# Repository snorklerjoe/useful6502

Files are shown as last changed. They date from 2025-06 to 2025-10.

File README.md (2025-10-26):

# Useful 6502 Machine

The goal of this project is to build a 6502-based portable machine,
running my own operating system.

## Current Status

*See the complete implementation plan and progress here: [Implemementation Plan](./IMPLEMENTATION_PLAN.md)*

PCB assembled, PIC is able to load code for the 6502 to execute, the 6502 can read/write to the 2-port SRAM.

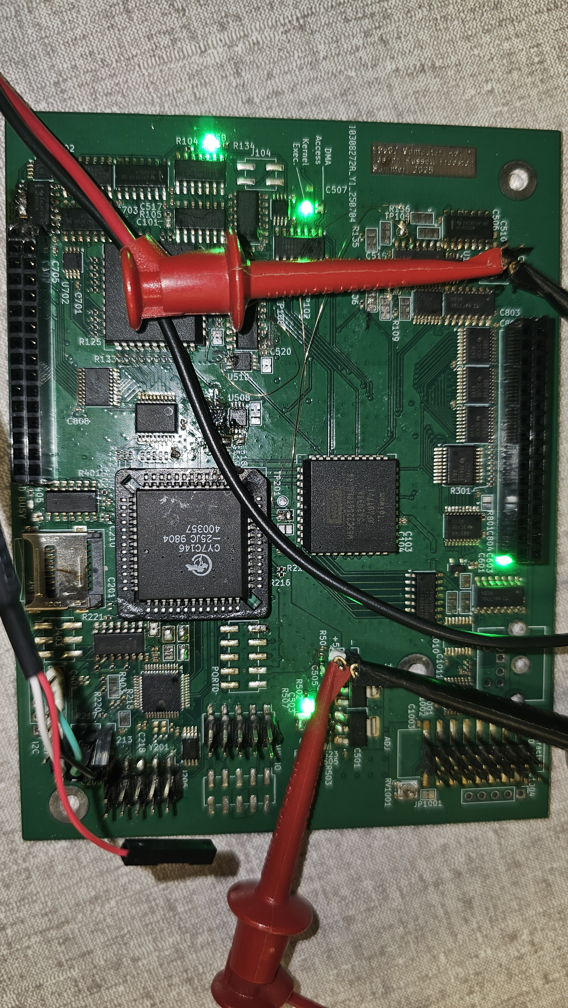
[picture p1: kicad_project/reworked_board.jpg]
Photo of the current (ish) assembled PCB


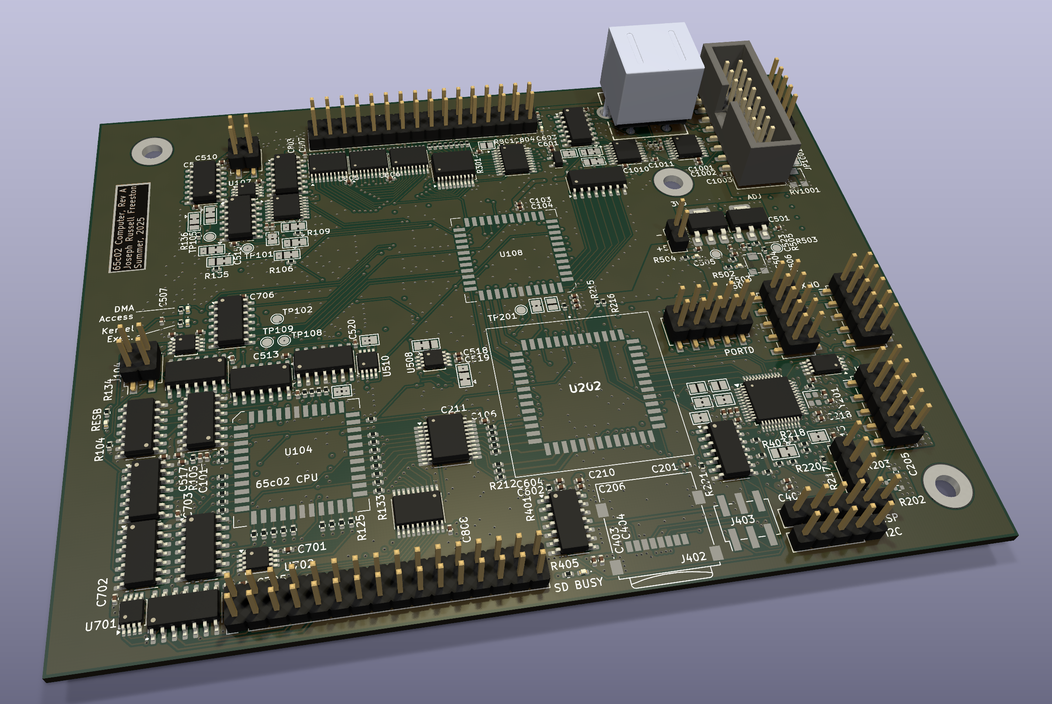
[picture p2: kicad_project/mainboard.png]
Main PCB rendering

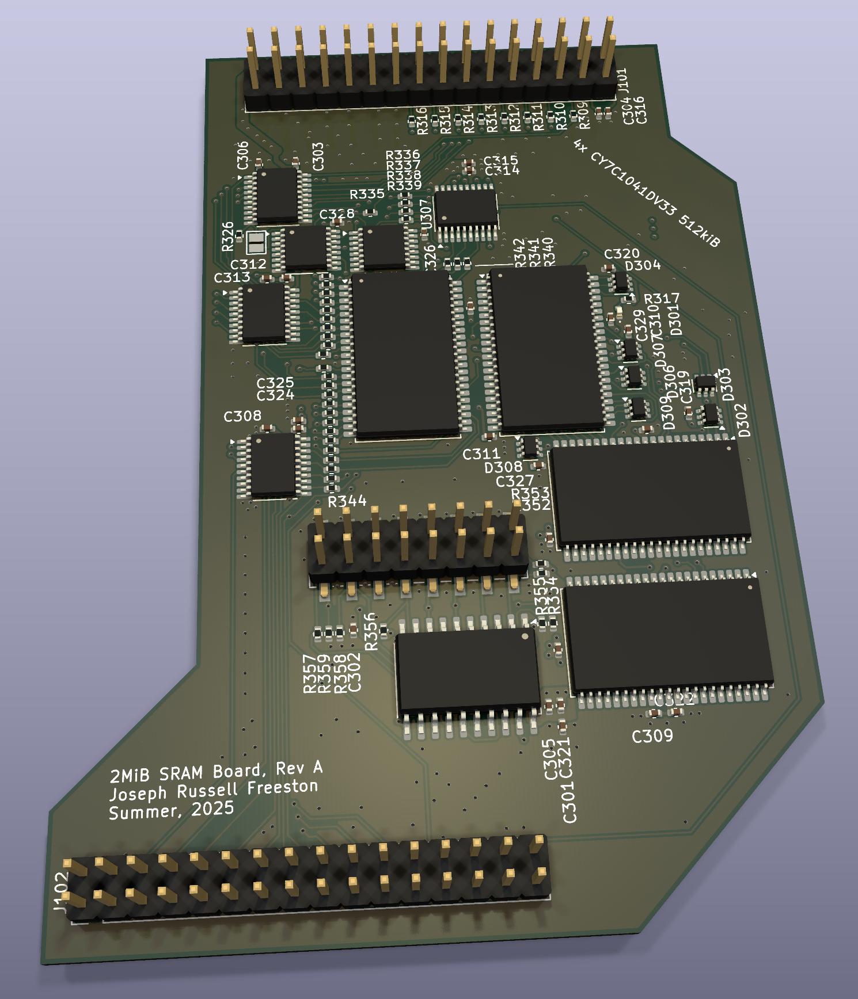
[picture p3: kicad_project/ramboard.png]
RAM Daughterboard rendering


## Hardware Goals

*These are some general points; for the full hardware specification, see here: [Hardware Specification](./HARDWARE.md)*

I want the following end goals to categorize the machine as "useful":

- At least 2 Megabytes of program memory and 2 Megabytes of data memory, of which at least 16k of memory can be used by a single process.
- Protected memory (kernel and user run modes defined by hardware checking if kernel or user code is being executed)
- PIC16 as peripheral coprocessor for fast i/o

## Software Goals

- Traps via "BRK" instruction for sys calls
- Full preemptive multitasking with up to 255 processes, round robin scheduler (maybe mlfq eventually)
- Filesystem: Tree, leaf nodes are devices or drivers.
- Driver for FAT32-formatted SD cards for easy file storage & transfer
- Standard library compatible with cc65 for creating high-level programs
- Basic UNIX-like shell utilities
- Simple web browser?
- SSH client based on DropBear?

## Faults

Faults will be detected by hardware and trigger a RESET, and the kernel will terminate the process.

## Hardware Timers

A hardware timer using the 65c22 will be used to interrupt processes with an NMI.
The kernel will maintain a global clock for user timing needs.

The PIC peripheral coprocessor may, perhaps, feature a watchdog timer to restart the kernel in the event of a crash.

## Particularly Helpful References

There are many resources that have proven themselves indispensible to the progress of his project.  
Here is a *small subset* of such resources:

- <https://www.pagetable.com/c64ref/6502/#>
- <http://www.6502.org/users/andre/index.html>
- <https://wilsonminesco.com/>
- <https://www.burtonsys.com/ps2_chapweske.htm>
- <https://www.pagetable.com/?p=1416>
- <https://github.com/commanderx16/x16-rom/>

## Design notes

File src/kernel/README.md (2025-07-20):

# Kernel Software Secification

This document will define the workings of the kernel I plan to implement for this machine.

Note that present tense will be used in this document irrespective of the implementation status.

## User / Supervisor Modes

The kernel implements user / supervisor modes with a simple mechanism:

- Any interrupt, software (`BRK`) or hardware (`RESB`, `IRQ`, or `NMI`), will force the system into kernel (supervisor) mode.
- As soon as an interrupt occurs, the kernel must quickly force a user-mode inhibit flag
- To exit, the 

## Memory Layout

## Interrupts

### Types & Hardware

### Interrupt Service Routines

## System Tree

### File Paths

## Processes

### Proc Struct
****

### Context Switch

### Scheduling

## System Calls

### Trap Machanism

### List of Calls

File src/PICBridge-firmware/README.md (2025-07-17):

# Build Options

## Setup

I have a modified version of pk2cmd installed on my machine, and the makefile has been given the location of `xc_cc` on my machine.  
If I still have `sudo` in my `Makefile`, it means I have still been too lazy to get the udev rules to work correctly without it.

## Commands

Run `make cycle` to clean, compile, flash, verify, and release the reset pin.

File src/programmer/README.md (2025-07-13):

#  Useful6502 Programmer

This will be python code to use a USB-to-TTL serial device to program kernel
images, load debug binaries, etc. to the 6502 via the PIC interface.

Here is how this will work:

- This script will load a 512-Byte chunk of code via uart to the PIC, along with an address for where it goes
- The PIC will load a 32-Byte copying boot routine to move these code bytes to wherever they need to go  
    This routine will reside in the top 32 bytes of memory addressed by the 6502, and will need to include all of the system vectors.
- The PIC will start the 6502 by bringing RESB high
- The PIC will halt until it gets interrupted by the 6502, indicating that it is done copying.
- At this point, the PIC will hold the 6502 back in a reset state.
  This process will continue until all data has been loaded.
- Finally, the values of the vectors (which reside in SRAM anyway) will be transmitted over uart
- The PIC will load these values in, start the 6502, and wait for an interrupt.

Thus, this programming script needs to do the following:

- Break a 64kiB binary image into 512-Byte chunks
- Figure out the 32-Byte bootloader code for each chunk
- Communicate with the PIC to load it all over and show progress in the terminal

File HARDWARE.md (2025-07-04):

# Hardware Overview

This document provides an overview and detailed description of the hardware for this Useful 6502 Machine project.

*View the full electrical schematic here: [Schematic](./kicad_project/Homebrew6502Project/Homebrew6502Project.pdf)*

## System Overview

The Useful 6502 Machine is a portable computer based on the WDC 65c02 CPU, featuring protected memory, a PIC16 peripheral coprocessor, dual-port SRAM, and support for external storage via SPI EEPROM and SD card. The system is designed for robust multitasking and expandability.

## Major Components

### 65c02 support logic

#### Clock and bus arbitration

The system clock is initially provided by an external function generator, allowing flexible frequency selection for bring-up and testing. The design includes provisions for a future custom clock board, perhaps with a clock divider to select multiple speeds.  
A hardware-test benchmark program will be used to determine maximum reliable clock speeds, which may be operation-dependent. However, the goal of this design is to clock the CPU at a frequency of at least 10MHz.

To meet the timing requirements of the 65c02 and its peripherals, the design generates several delayed and phase-shifted clock signals. Solder jumpers on the board allow for different devices to receieve clock signals with different delays imparted by slower 74xx logic series to ensure that setup and hold times can be met.  
The delayed clocks can also be used to operate bus switches as a measure against bus contention.

It is worth noting that the system clock as described here is separate from the PIC peripheral coprocessor (explained below), which will use an internal PLL or an external crystal. Rather, the system clock applies for the 65c02 CPU and any relevant synchronous devices thereattached.

#### User / Kernel mode logic

The design implements hardware-enforced user and kernel modes to provide memory protection and process isolation. This is achieved using glue logic that monitors the CPU's address and control lines.

When the CPU accesses an interrupt vector, the logic asserts a "kernel mode" signal. Access to kernel memory (the top 16k), as well as privileged instructions is gated by this signal. If user-mode code attempts to access protected resources, the hardware can trigger a fault. All faults are soft resets, which will not affect the information stored in memory but will lose information in the CPU registers. This is not an issue, as a process that generates a fault will be terminated by the kernel immediately and its memory freed.

#### Interrupts

Non-maskable interrupts will solely be generated by an externally-mapped timer in the 65c22 Versatle Interface Adapter (VIA) chip. This will be used to initiate forced context switching, interrupting whatever process is running regardless of the interrupt flag.
Normal (IRQ) interrupts will be used for i/o purposes, which can be disabled during timing-sensitive operations even while in userspace.

#### Direct character i/o

The primary user interface for this machine will be through a PS/2 keyboard input and a set of character LCD displays.

The PS/2 keyboard interface has a single byte buffer. Whenever a byte is received from the keyboard and the buffer is filled, the interface will signal to the keyboard that it cannot accept another byte by pulling the clock line low until the byte is read. The byte can be read by reading `PORTA` of the 65c22 VIA chip. The data ready / data taken handshake bits of the VIA are used by the PS/2 keyboard interface.

To output information to the character LCD interface, two bits of `PORTB` are used, via an active-low decoder, to select which LCD chip select line (of four) will be driven low. Two addional bits are used for the overall LCD enable, and the LCD register select.  
Writing to the data pins is functionally identical to writing to a memory banking regster (see below), with both least-significant address bits set. The LCD interface can only be written to, and so a character buffer will need to exist in memory.

### Memory

All volatile memory will be mapped into a bank-switched 65c02 address space. The mechanisms and specifics thereof are discussed below:

#### Memory map & address decode

Address decode is almost entirely performed by discrete 74xx logic gates. Devices are chosen carefully to consider propagation delays to attempt the maximum possible speed.

The overall virtual (or as far as the 65c02's address space is aware) memory map is as follows:

Addr Range  |   Label   |   Usage   |   Switched    |   User Privs
------------|-----------|-----------|---------------|----------------
FFFF<br>..<br>F810 | DMA  | Mapping of a dual-port SRAM shared with the PIC16 peripheral coprocessor | NEVER | None
F80F<br>..<br>F800 | VIA | Mapping of VIA hardware registers | NEVER | None
F7FF<br>..<br>C000 | KMEM | General-purpose resident kernel memory. Use for top-level trap routines, ISRs, context switching routines, and whatever else will fit. | NEVER | None
BFFF<br>..<br>8000 | BP2 | Third banked page. Available to user processes upon request. Mapped over the same physical memory as BP1 if not in use. | YES | RWX
7FFF<br>..<br>4000  | BP1 | Second banked page. Available to user processes upon request. Mapped over the same physical memory as BP1 if not in use. | YES | RWX
3FFF<br>..<br>0000 | BP0 | First banked page. Not to be confused with "Zero page", which is a portion of this region. Bank 0 belongs to kernel; everything else here is for userspace. | YES | RWX

All banked memory is physically stored on a daughterboard, for ease of experimentation and expandability.

As far as address decode is concerned, one subsection of the implementation determines a `HIMEM` condition based on the top two bits of the "virtual" address. Anything within "High-Memory" (the top 16kiB) belongs exclusively to the kernel. Obviously, the `VIA` and the `DMA` segments are not bank switched and exist physically within the corresponding devices. The `KMEM` segment is also a resident segment and is hardwired to be stored in bank zero.

#### Bank switching

There are a total of four banking registers in use, which technically enable up to 1 GiB of physical memory to be addressed. Because the memory needs to operate asynchronously and as a result of the cost of SRAM, it is unlikely this limit will ever be reached.
That being said, a PSRAM interface may be an option down the line, particularly as the CPU's bus synchronization controls are made available in the RAM daughterboard headers.

The banking registers are configured as follows:

The "Root bank" register (8-bits) is intended to select which RAM card is being addressed, and represents the 8 most-significant bits of the physical address.

The Bank [A, B, and C] registers store the next 8 most-significant bits. Which register is used for these bits is determined by the two most-significant bits of the virtual address, as defined in the memory map above.

Writing to these registers requires a few steps. Before writing to any of the bank registers, the `/WRITBANKEN` flag in `PORTB` of the 65c22 VIA must be driven low. At that point, the write may be performed (only by code executing in `HIMEM`) by any non-`HIMEM` write, partiularly a zero-page write. It is worth noting that the hardware stack will not function until the `/WRITBANKEN` flag is set back to a `1`. During the write, the "Root Bank" register is written if the third bit (bit 2) of the address is set. Otherwise, the A, B, or C register will be written according to the value of the two least-significant bits of the address. Thus, any bank switch may be performed with three 65c02 instructions: a PORTB clear-bit instruction, a zero-page write, and a set-bit instruction to reset `/WRITBANKEN`.

**Bank Register Map:**

Register      | Address/Selection Bits | Function
--------------|-----------------------|-----------
Root Bank    | Addr bit 2 = 1        | Selects RAM card (8 MSbs of physical addr)
Bank A       | Addr bits [1:0] = 00  | second 8 MSbs for BP0 region
Bank B       | Addr bits [1:0] = 01  | second 8 MSbs for BP1 region
Bank C       | Addr bits [1:0] = 10  | second 8 MSbs for BP2 region

Writes are enabled by clearing `/WRITBANKEN` (VIA PORTB), then writing to the appropriate address. The hardware stack is disabled during this operation and re-enabled by setting `/WRITBANKEN`.

**Note:** Registers are write-only; software should maintain shadow copies for context switching and debugging.

#### Memory protection

User memory will all be bank switched. Any process may be given 16, 32, or 48 kiB of memory in 1-3 banks, respectively. All bank registers will be context-switched, so that no process may access any memory outside of the banks assigned to it. If banks of virtual memory are unused by a process, they will be set to the same bank as `BP0`, so that the address space will wrap around.

While in user-mode, if the address becomes set to any location in `HIMEM` without first involving an interrupt vector-pull, a fault will occur and the process will be terminated as described above.

#### CY7C1041DV33 SRAM interface

The initial solution for volatile memory uses 4x CY7C1041DV33 (512kiB SRAM) to provide 2 MiB of RAM. The CY7C1041DV33 was chosen based on availability and price, despite it being arranged in 16-bit words and using 3.3V logic (requiring level conversion). Glue logic, buffers, and line drivers are thus used to interface to the RAM; see the schematic for more details.

#### Dual-port SRAM

The resident `DMA` segment of the address space is mapped to a CY7C146-25JC 2kiB dual-port SRAM, also chosen by availability and price.

This is accessed by both the 65c02 and the PIC peripheral coprocessor, described below. Mutual exclusion synchronization must be implemented in software to ensure that both processors do not attempt to access the same memory location, although there are hardware provisions for utilizing the CY7C146-25JC's built-in mutual-exclusion hardware to pause the 65c02 CPU in the event of an issue, though preferably the PIC will cooperatively yield.

### Peripheral Interfaces and I/O

#### PIC16 peripheral coprocessor

The PIC16 peripheral coprocessor is responsible for handling fast i/o, offloading time-sensitive and busywork-like i/o tasks from the 65c02. It communicates with the 65c02 primarily through the dual-port SRAM, allowing for efficient data exchange and command passing.

The PIC16 manages a few otherwse-tedious interfaces:

- **SD card interface** (via level-shifted open-collector SPI)  
    This will operate merely as a single-sector buffer and SPI interface. The actual FAT32 implementation will run on the 65c02. When it desires a sector be read, this can be signalled to the peripheral coprocessor via an interrupt, and the 65c02 can be interrupted later, once the entire sector is read into the `DMA` memory and ready for the FAT32 interface to access.
- **SPI EEPROM** (for bootloading and storage of the current kernel image)  
    The intention is that this can be written solely through the PIC over UART to flash a new kernel image and bootloader. The self-installing bootloader and boot-time interrupt vectors will be placed in DMA memory, and the 65c02 will be reset by the PIC. The two processors will then cooperate to move the kernel image from the EEPROM into memory in pieces that fit in the `DMA` memory. Once the image is loaded, a handshake will occur to ensure both processors are in a fully-initialized state before the 65c02 initializes drivers and starts up a shell.
- **General serial peripheral busses**, such as UART and I2C can be used to interface with other devices.  
    This may eventually include an ESP-01 based WiFi interface for network access, and will certainly enable the use of RS-232 peripherals down the line with an external MAX-232 based interface.

An ICSP header is included on the board to enable in-circuit programming and debugging of the PIC coprocessor.

Synchronization between the PIC16 and 65c02 is achieved through software protocols, with the option to use the dual-port SRAM's hardware mutual-exclusion features for critical sections as described previously, but the PIC16 is generally expected to yield access to shared resources as needed to avoid contention.

### Boot Process Summary

The boot process for this machine is as follows:

1. **Power-On:**
   - The PIC16 coprocessor initializes using its internal PLL or external crystal.
   - The 65c02 and peripherals are held in reset while the PIC performs initial checks.

2. **Firmware/Kernel Loading:**
   - The PIC16 bootloader communicates with a host PC (via UART) to receive a new kernel image if needed, programming it into the SPI EEPROM.
   - On normal boot, the PIC16 reads the kernel image from the SPI EEPROM and transfers it in chunks to the dual-port SRAM (DMA region) or main RAM.

3. **System Initialization:**
   - Once the kernel image is loaded, the PIC16 signals the 65c02 to release reset.
   - The 65c02 begins execution from the loaded kernel image, initializing memory, bank registers, and device drivers.

4. **Handshake and Ready State:**
   - The PIC16 and 65c02 perform a handshake via the dual-port SRAM to ensure both are ready.
   - The kernel may perform hardware tests or diagnostics before starting user processes.

5. **Normal Operation:**
   - The system enters normal operation, with the kernel on the 65c02 CPU managing multitasking, memory protection, and I/O.

This process ensures reliable startup, easy firmware updates, and robust initialization of all hardware subsystems.

---

*This document will be updated as features evolve.*

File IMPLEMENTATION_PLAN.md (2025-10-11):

# Implementation Plan

This is the implementation plan for my homebrew 65c02 machine, from initial hardware validation to kernel and OS development

## Hardware Debugging & Validation

- [x]  **Rev A design completion**  
  - Goals & constraints identified
  - Initial schematics developed
  - PCB layout
  - PCB, stencil, and component ordering

- [x]  **Main board assembly**  
  - Assembly & reflow

- [x]  **Initial electrical tests**  
  - Test voltage regulators & check for shorts

- [x] **PIC16 bring-up: Hello world**
  - Write and flash a simple test program (UART Hello World) to verify PIC programming and basic operation.

- [x] **PIC to Dual-port SRAM communication**
  - Develop subroutines for accessing and verifying the dual-port SRAM from the PIC

- [ ] **PIC programs 65c02 memory**
  - Use the PIC to write a short program into SRAM.
  - Allow the 65c02 to execute this program, verifying code/data path and bus arbitration.

- [ ] **PIC ↔ SPI EEPROM**
  - Develop routines for the PIC to read/write the SPI EEPROM.
  - Test with known data patterns and verify persistence.

- [ ] **PIC bootloader & host communication**
  - Implement a bootloader on the PIC that communicates with a Python script on the host PC (via UART).
  - Enable easy programming of kernel images into the SPI EEPROM.
  - Validate end-to-end image transfer and storage (using a checksum?).

- [ ] **65c02 boot from SRAM**
  - Use the PIC to load a test/benchmark image into SRAM.
  - Run the image on the 65c02, verifying CPU operation and memory access.

- [ ] **Hardware test & benchmark suite**
  - Develop a comprehensive test image to exercise all hardware features (memory, I/O, timers, etc.).
  - Run tests at various clock frequencies to determine system stability and performance limits.

- [ ] **System clock board**
  - Design and build a dedicated clock board to replace the function generator.
  - Test with the rest of the system

## Kernel Development

This is still vague until the hardware is validated / debugged and low-level firmware matures.

- [ ] **Initial Kernel Bring-Up**
  - Develop a minimal kernel to handle basic process management and hardware abstraction.
  - Test context switching, memory protection, and basic I/O.

- [ ] **Driver Development**
  - Write drivers for SD card (FAT32), serial I/O, and other peripherals.
  - Integrate with kernel and validate functionality.

- [ ] **CC65 Libc**
  - Develop a custom libc that enabls userland applications to be written or ported in C

- [ ] **Userland & Shell**
  - Develop a simple shell and basic utilities.

---

*Update this plan as milestones are reached and new challenges arise.*

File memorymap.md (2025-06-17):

# Memory Map

Addr Range  |   Label   |   Usage   |   Switched    |   User Privs
------------|-----------|-----------|---------------|----------------
F810 - FFFF | DMA  | Mapping of a dual-port SRAM shared with the PIC16 peripheral coprocessor | NEVER | None
F800 - F80F | VIA | Mapping of VIA hardware registers | NEVER | None
C000 - F7FF | KMEM | General-purpose resident kernel memory. Use for top-level trap routines, ISRs, context switching routines, and whatever else will fit. | NEVER | None
8000 - BFFF | BP2 | Second banked page. Available to user processes upon request. Mapped over the same physical memory as BP1 if not in use. | YES | RWX
4000 - 7FFF | BP2 | Second banked page. Available to user processes upon request. Mapped over the same physical memory as BP1 if not in use. | YES | RWX
0000 - 3FFF | BP1 | First banked page. Not to be confused with "Zero page", which is a portion of this region. Bank 0 belongs to kernel; everything else here is for userspace. | YES | RWX

## Special Addresses

Addr | Label    | Usage
-----|----------|------

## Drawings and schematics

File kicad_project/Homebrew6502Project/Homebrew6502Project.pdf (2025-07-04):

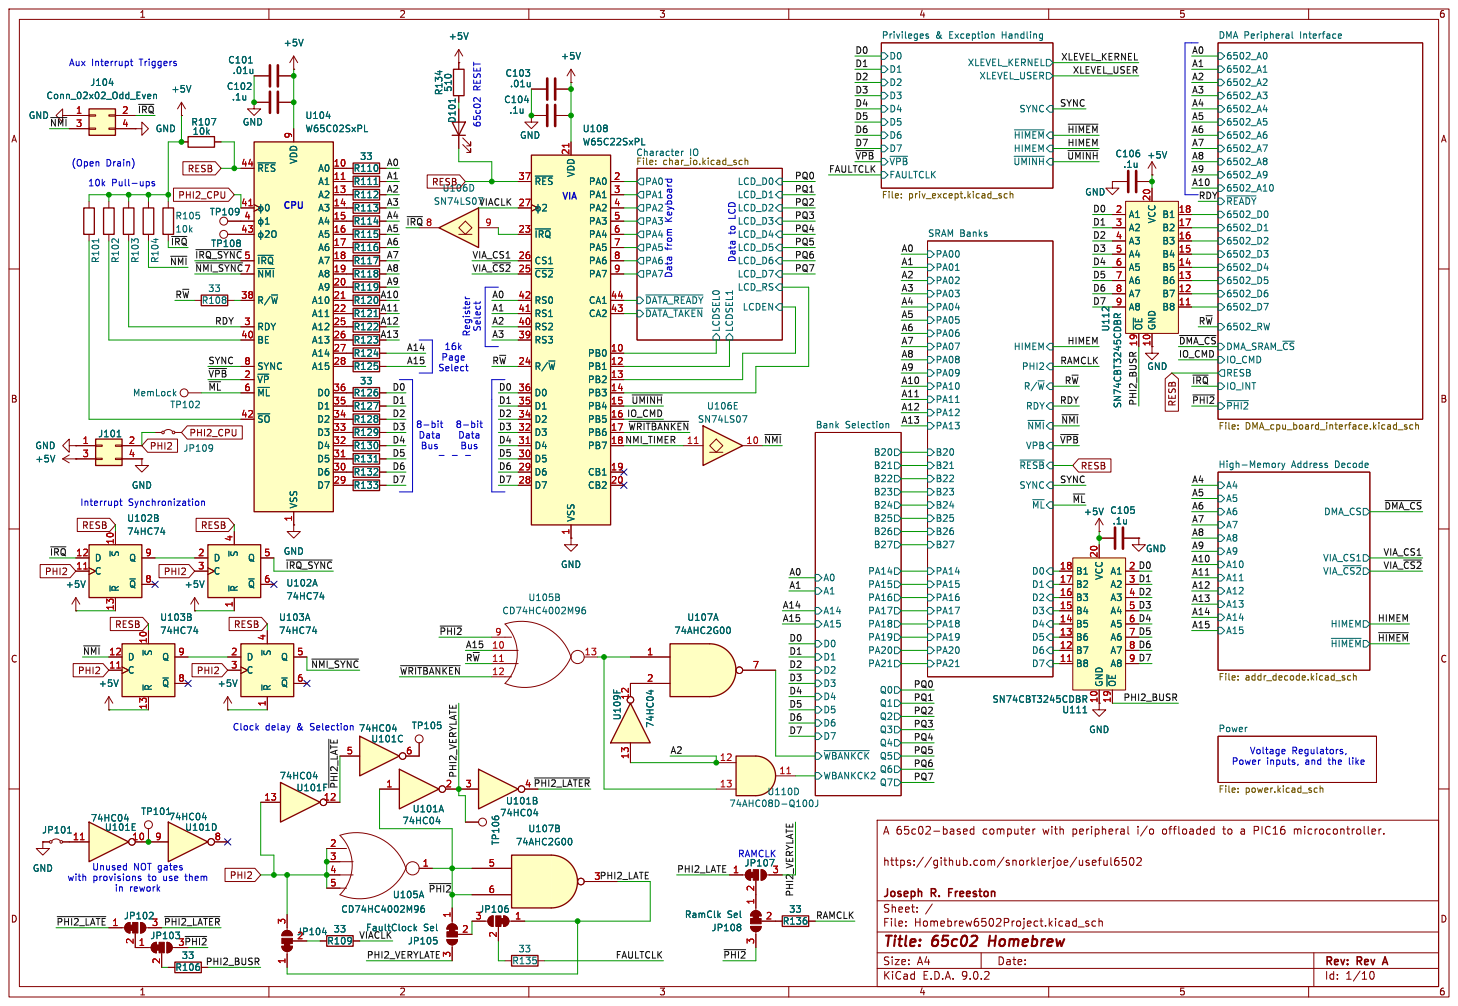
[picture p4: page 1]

8-bit Data Bus

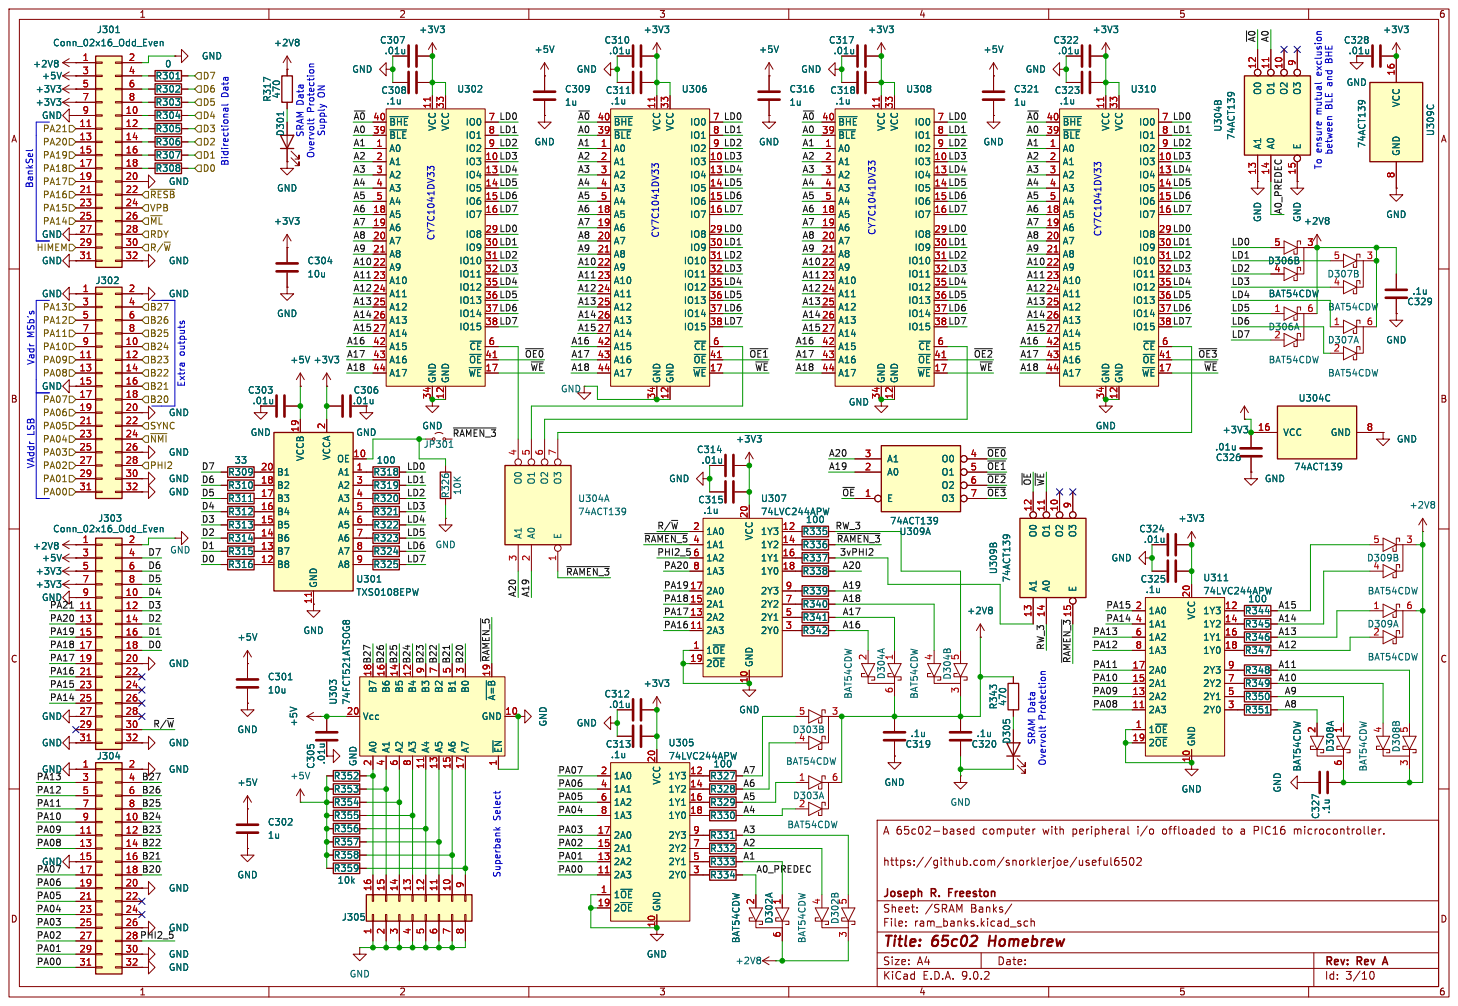
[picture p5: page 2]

IO15 38 ~{CE}6 ~{OE} 41 ~{WE} 17 A0 1 A1 2 A2 3 A3 4 A4 5 A5 18 A6 19 A7 20 A8 21 A9 22 A10 23 A11 24 A12 25 A13 26 A14 27 A15 42 A16 43 A17 44 GND

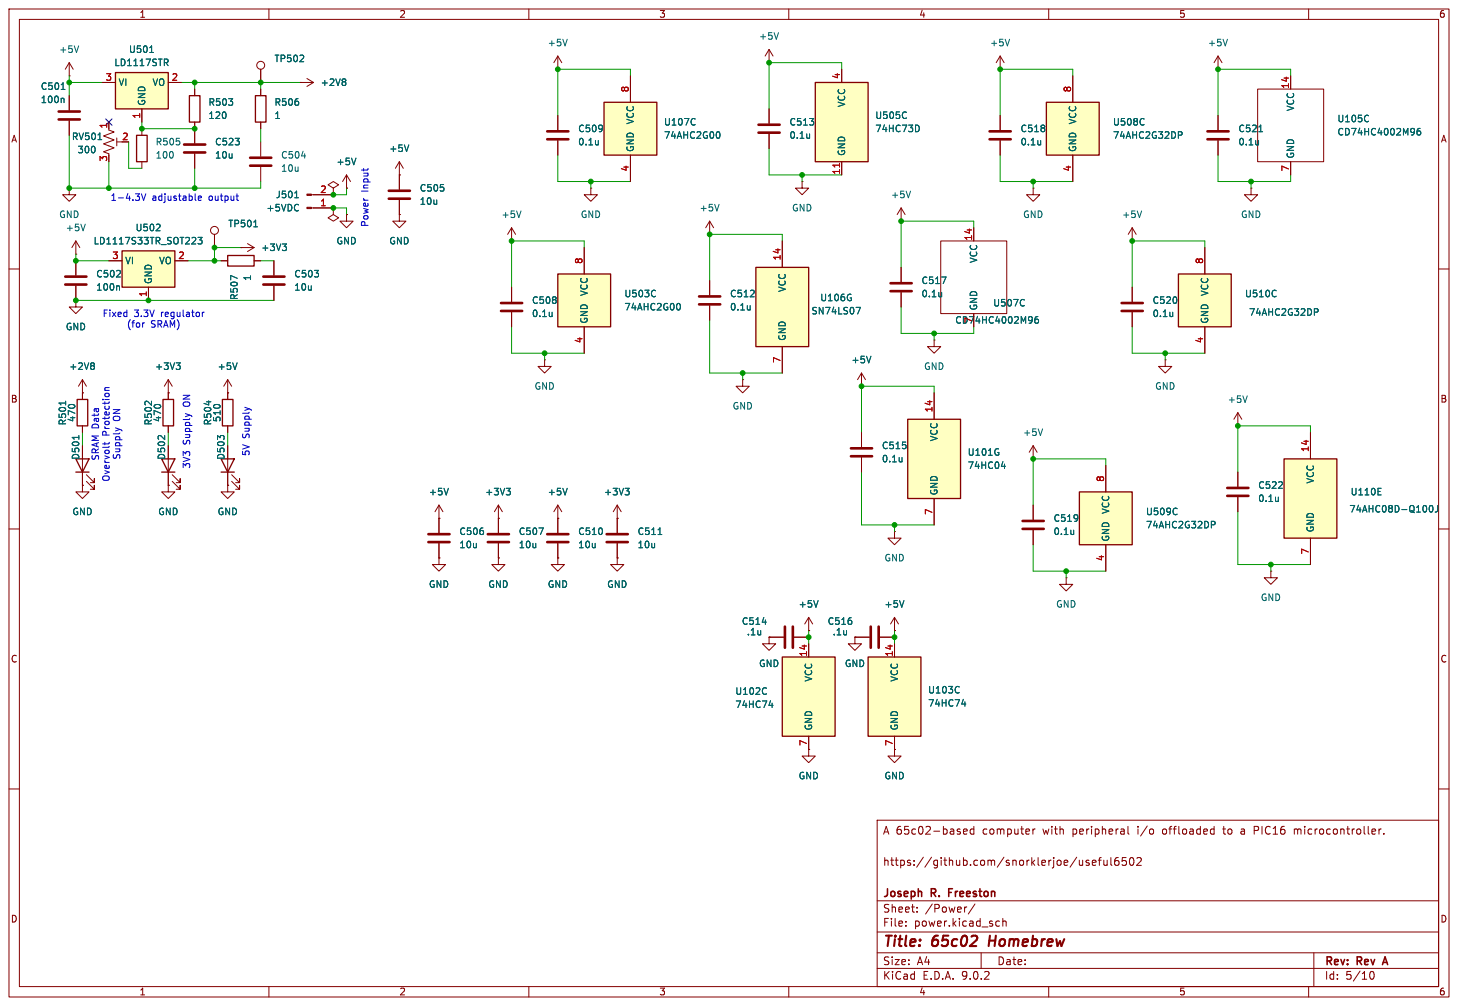
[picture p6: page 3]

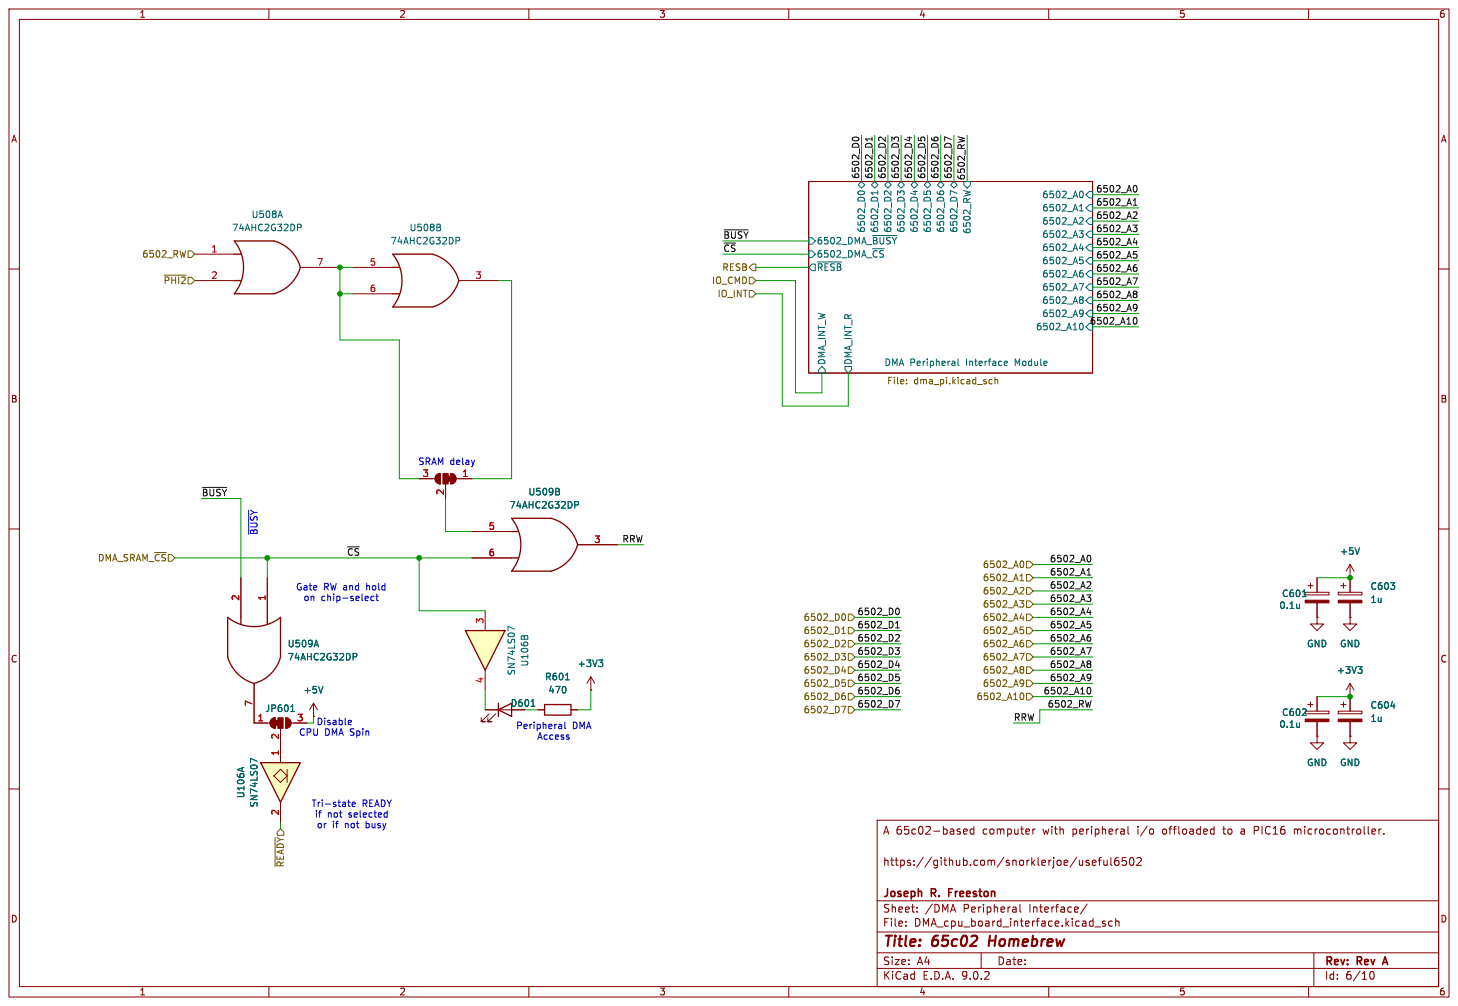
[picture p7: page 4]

or if not busy Gate RW and hold
on chip-select +5V U509A

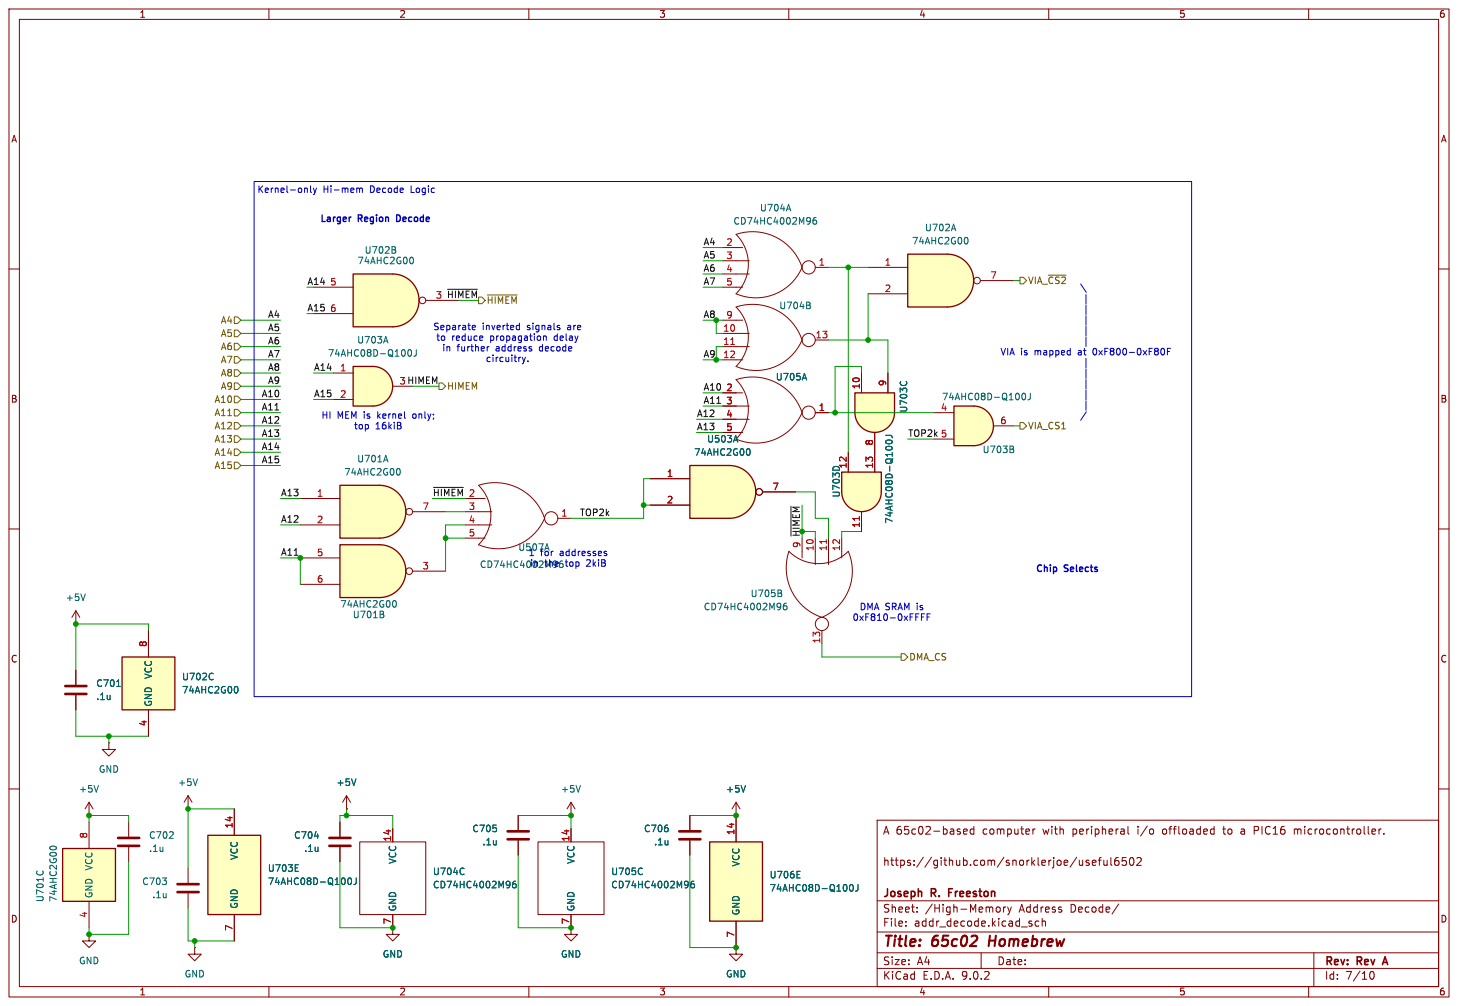
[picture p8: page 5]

Separate inverted signals are

VIA is mapped at 0xF800-0xF80F

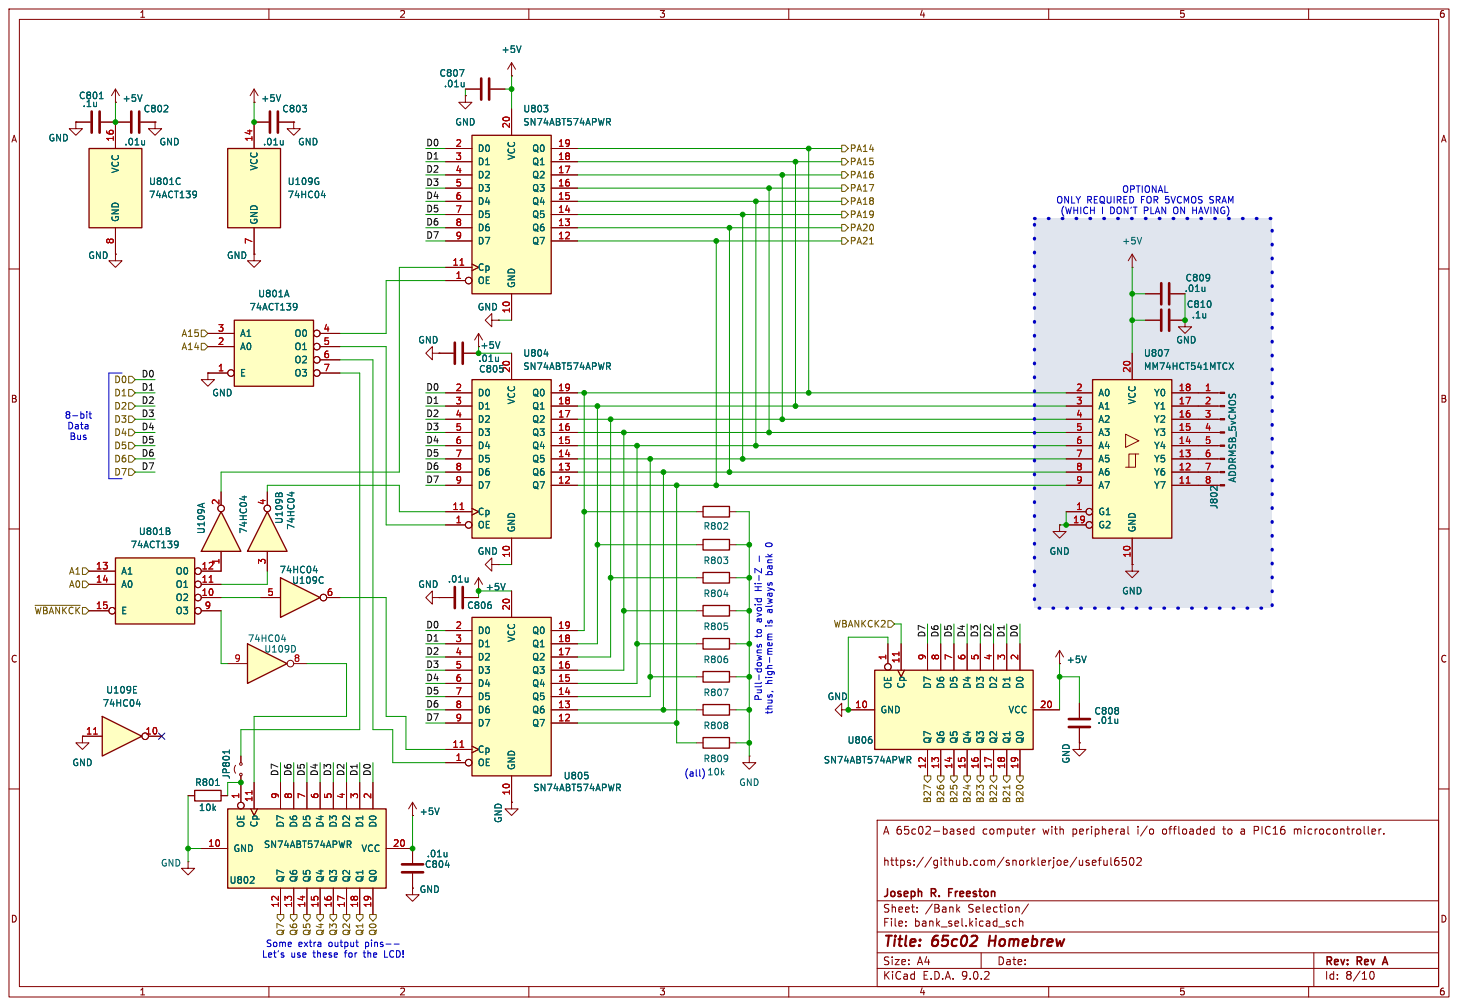
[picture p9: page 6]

(WHICH I DON'T PLAN ON HAVING)
.01u +5V GND
.01u GND

1 VCC 20 GND 10 Q0 19 Q1 18 Q2 17 Q3 16 Q4 15 Q5 14 Q6 13 Q7 12 U802 SN74ABT574APWR GND GND

1 VCC 20 GND 10 Q0 19 Q1 18 Q2 17 Q3 16 Q4 15 Q5 14 Q6 13 Q7 12 U806 SN74ABT574APWR GND GND

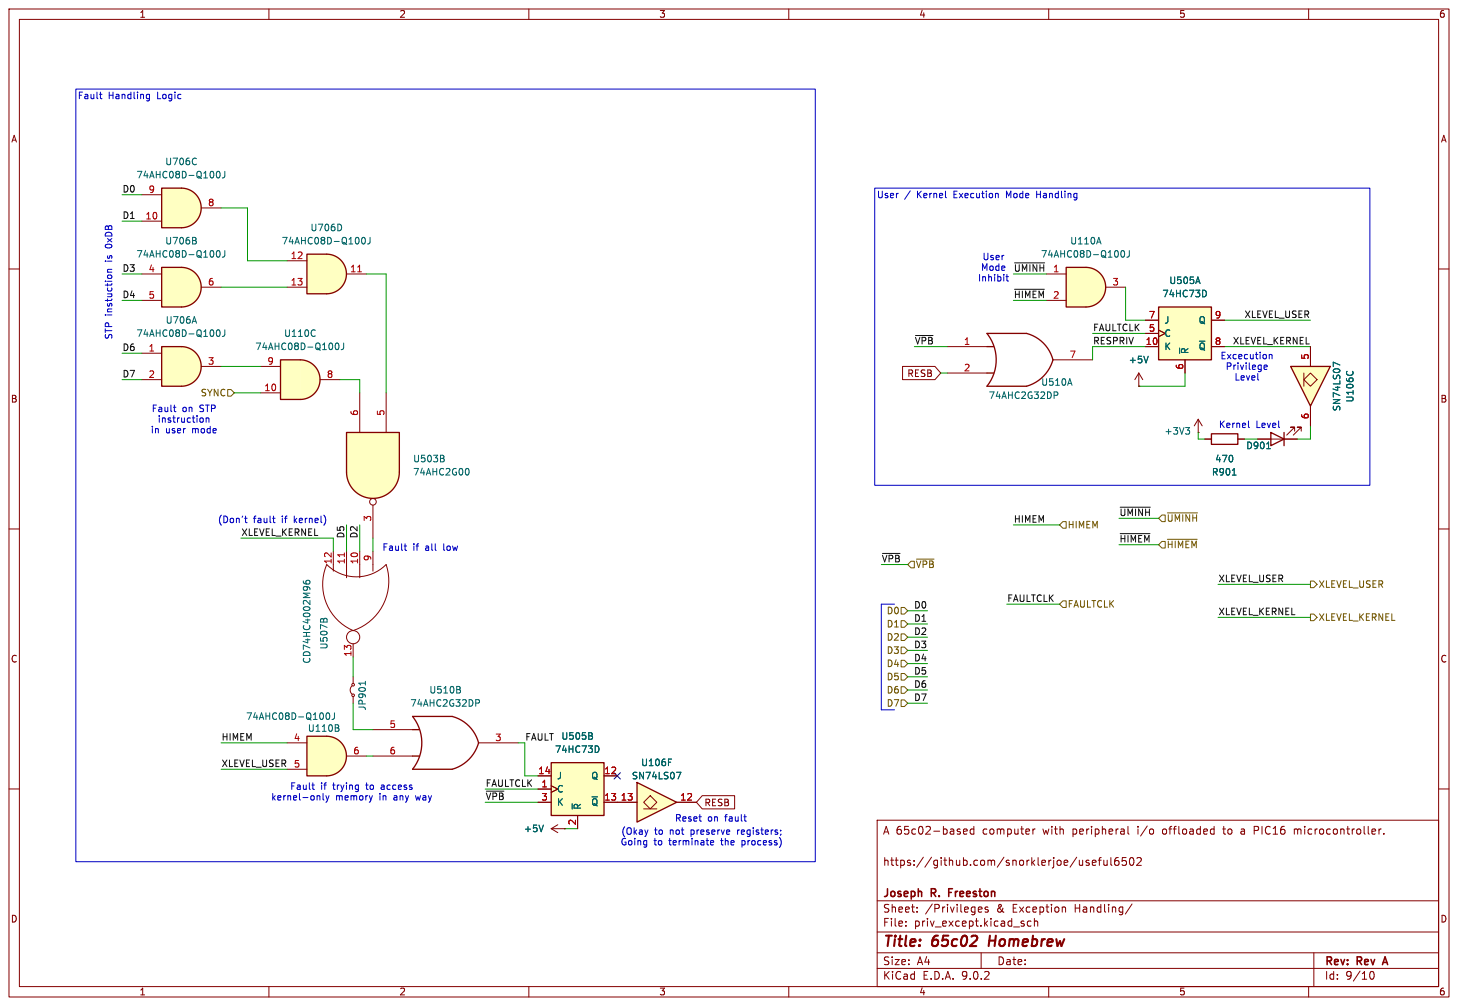
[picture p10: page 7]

Fault if trying to access

(Okay to not preserve registers;

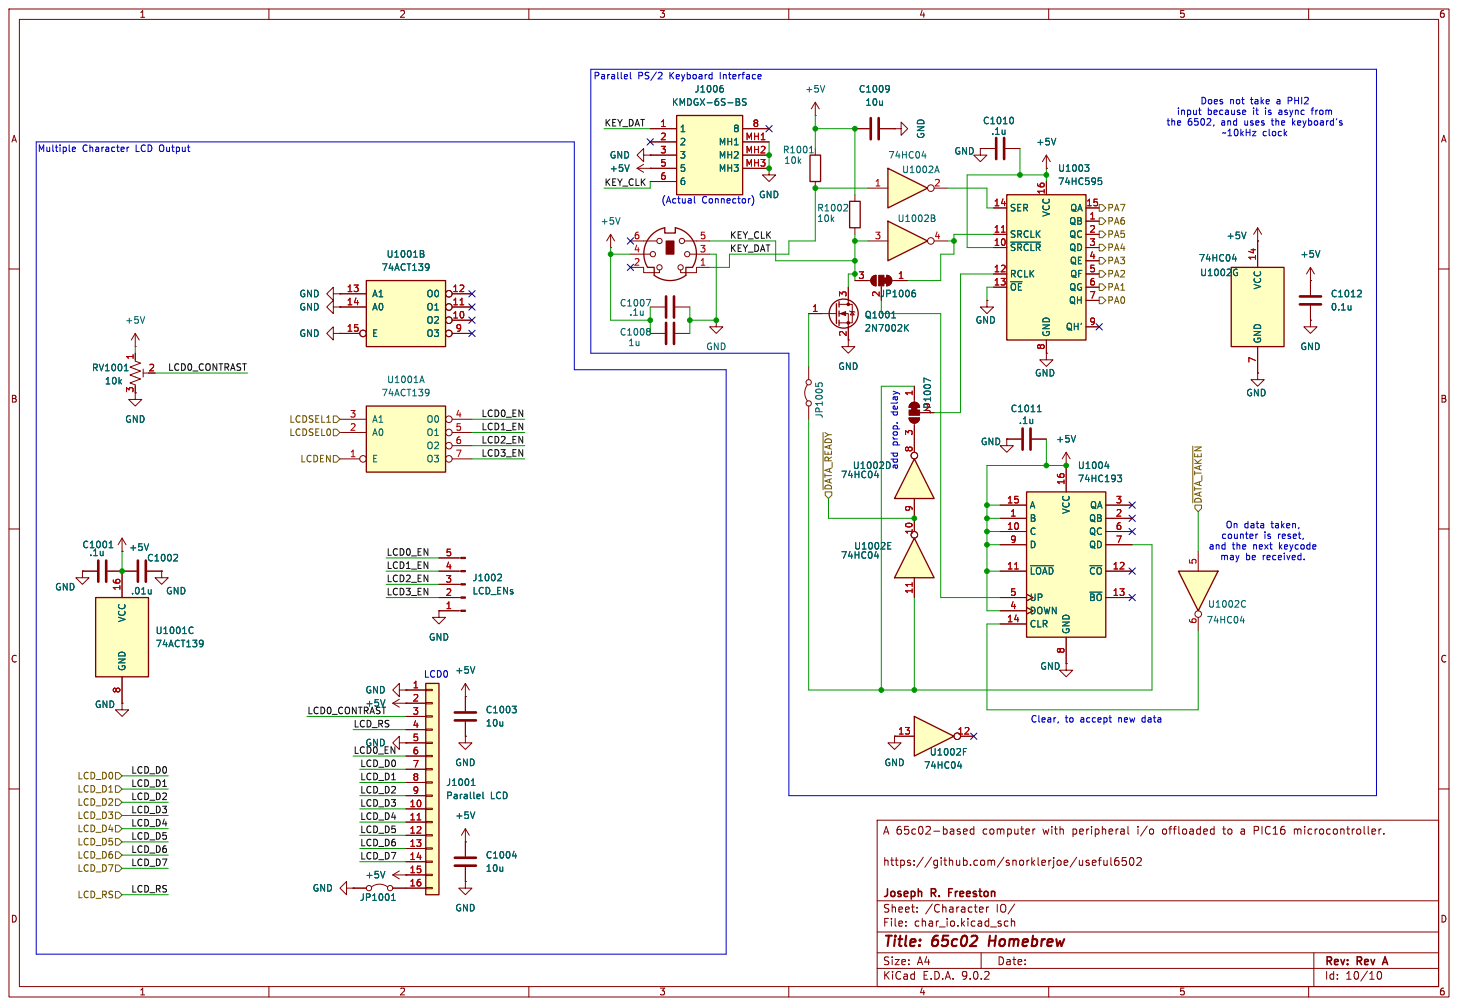
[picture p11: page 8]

input because it is async from

the 6502, and uses the keyboard's ~10kHz clock Clear, to accept new data

GND GND VCC 16 GND

8 QA 3 QB 2 QC 6 QD 7 ~{CO}12 ~{BO}13 GND GND GND

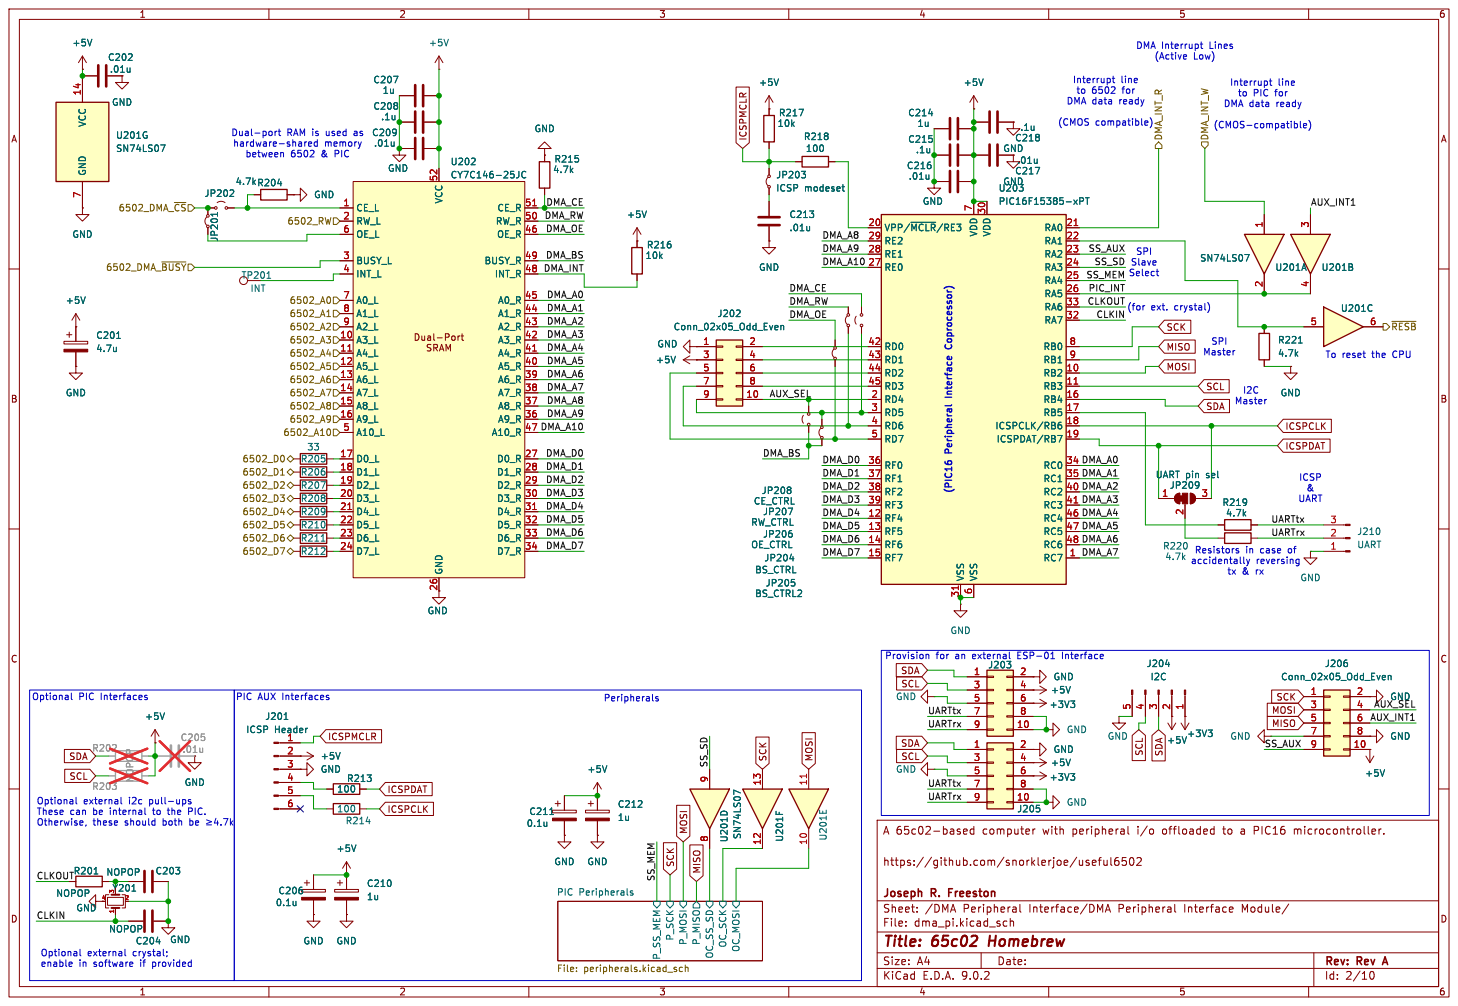
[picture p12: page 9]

to PIC for DMA data ready

to 6502 for DMA data ready

1 2 U203 PIC16F15385-xPT RD5 3 RD6 4 VPP/~{MCLR}/RE3 20 RE2 29 RE1 28 RE0 27 RD0 42 RD1 43 RD2 44 RD3 45 RD4 2 RD7 5 RF0 36 RF1 37 RF2 38 RF3 39 RF4 12 RF5 13 RF6 14 RF7 15 VSS 31 VDD

To reset the CPU

PIC Peripherals File: peripherals.kicad_sch

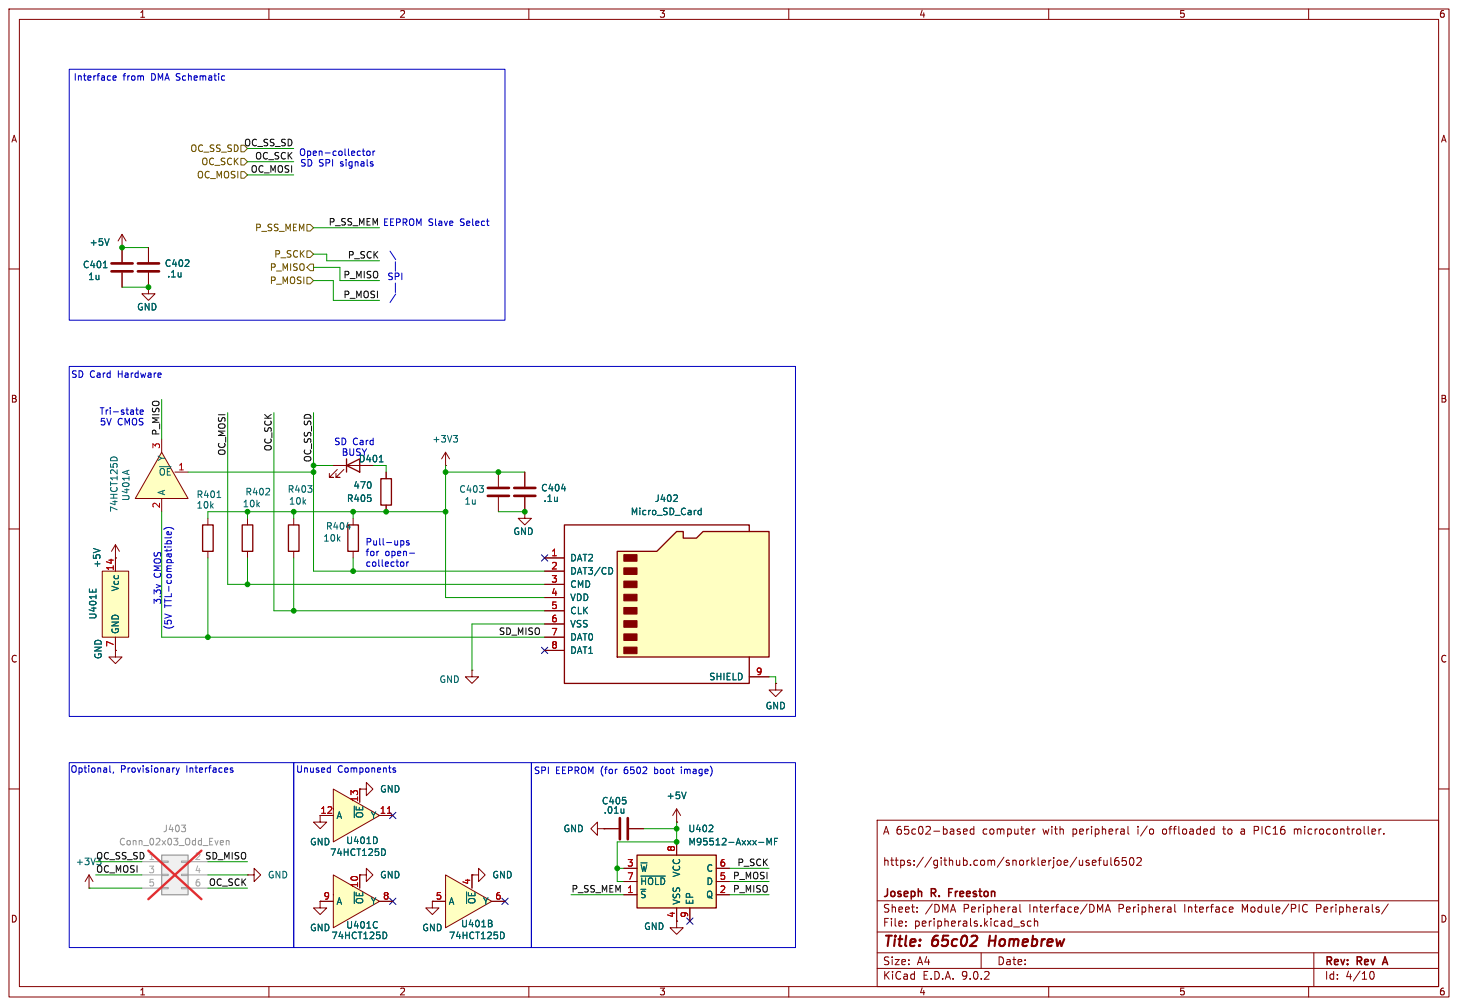
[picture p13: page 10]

Open-collector SD SPI signals C402

for open- collector SD Card BUSY

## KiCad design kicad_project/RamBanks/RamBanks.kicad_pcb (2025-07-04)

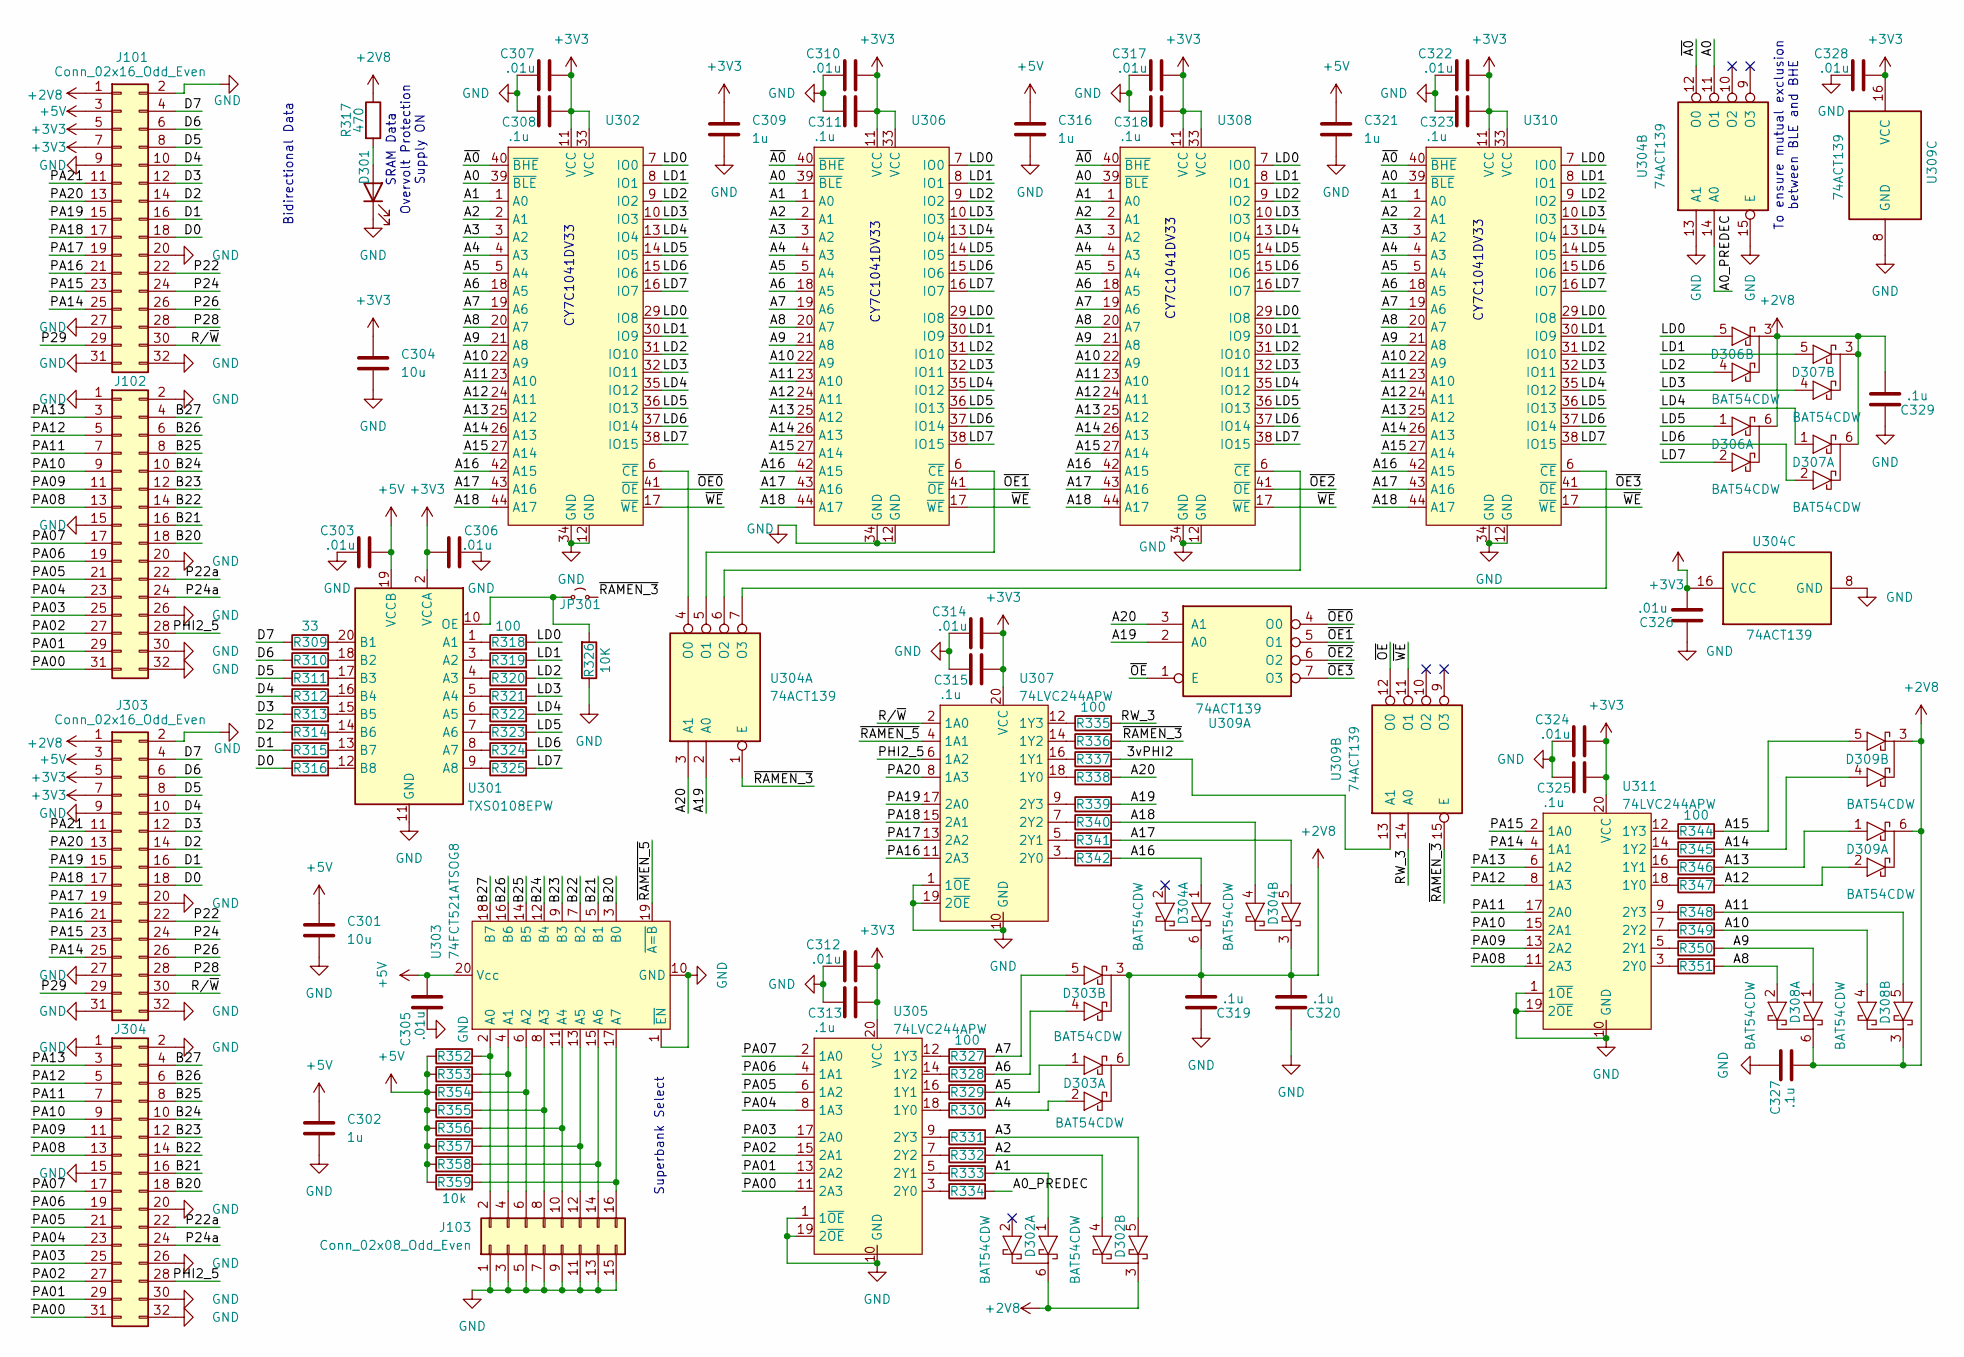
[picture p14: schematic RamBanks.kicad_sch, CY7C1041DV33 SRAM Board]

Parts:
C301, C304: 10u; C_0402_1005Metric
C302, C309, C316, C321: 1u; C_0402_1005Metric
C303, C305, C306, C307, C310, C312, C314, C317, C322, C324, C326, C328: .01u; C_0402_1005Metric
C308, C311, C313, C315, C318, C319, C320, C323, C325, C327, C329: .1u; C_0402_1005Metric
D301: LED; LED_0402_1005Metric
D302, D303, D304, D306, D307, D308, D309: BAT54CDW; SOT-363_SC-70-6
J101, J102: Conn_02x16_Odd_Even; PinHeader_2x16_P2.54mm_Vertical
J103: Conn_02x08_Odd_Even; PinHeader_2x08_P2.54mm_Vertical_SMD
J303, J304: Conn_02x16_Odd_Even; PinHeader_2x16_P2.54mm_Vertical_SMD
JP301: Jumper_2_Small_Open; SolderJumper-2_P1.3mm_Open_Pad1.0x1.5mm
R309, R310, R311, R312, R313, R314, R315, R316: 33; R_0402_1005Metric
R317: 470; R_0402_1005Metric
R318, R319, R320, R321, R322, R323, R324, R325, R327, R328, R329, R330, R331, R332, R333, R334, R335, R336, R337, R338, R339, R340, R341, R342, R344, R345, R346, R347, R348, R349, R350, R351: 100; R_0402_1005Metric
R326: 10K; R_0402_1005Metric
R352, R353, R354, R355, R356, R357, R358, R359: 10k; R_0402_1005Metric
U301: TXS0108EPW; TSSOP-20_4.4x6.5mm_P0.65mm
U302, U306, U308, U310: TSOP-II-44_10.16x18.41mm_P0.8mm
U303: 74FCT521ATSOG8; SOIC-20W_7.5x12.8mm_P1.27mm
U304, U309: 74ACT139; TSSOP-16_4.4x5mm_P0.65mm
U305, U307, U311: 74LVC244APW; TSSOP-20_4.4x6.5mm_P0.65mm

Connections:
+2V8: C319.1, C320.1, C327.1, C329.1, D302.3 (K2), D302.6 (K2), D303.3 (K2), D303.6 (K2), D304.3 (K2), D304.6 (K2), D306.3 (K2), D306.6 (K2), D307.3 (K2), D307.6 (K2), D308.3 (K2), D308.6 (K2), D309.3 (K2), D309.6 (K2), J101.1, J303.1, R317.1
+3V3: C304.1, C306.1, C307.1, C308.1, C309.1, C310.1, C311.1, C312.1, C313.1, C314.1, C315.1, C317.1, C318.1, C322.1, C323.1, C324.1, C325.1, C326.1, C328.1, J101.5, J101.7, J303.5, J303.7, U301.2 (VCCA), U302.11 (VCC), U302.33 (VCC), U304.16 (VCC), U305.20 (VCC), U306.11 (VCC), U306.33 (VCC), U307.20 (VCC), U308.11 (VCC), U308.33 (VCC), U309.16 (VCC), U310.11 (VCC), U310.33 (VCC), U311.20 (VCC)
+5V: C301.1, C302.1, C303.1, C305.1, C316.1, C321.1, J101.3, J303.3, R352.1, R353.1, R354.1, R355.1, R356.1, R357.1, R358.1, R359.1, U301.19 (VCCB), U303.20 (Vcc)
/3vPHI2: R337.2, U309.13 (A1)
/A0: U302.39 (~BLE), U304.11 (O1), U306.39 (~BLE), U308.39 (~BLE), U310.39 (~BLE)
/A0_PREDEC: R334.2, U304.14 (A0)
/A1: D302.1 (A01), R333.2, U302.1 (A0), U306.1 (A0), U308.1 (A0), U310.1 (A0)
/A2: D302.4 (A02), R332.2, U302.2 (A1), U306.2 (A1), U308.2 (A1), U310.2 (A1)
/A3: D302.5 (A12), R331.2, U302.3 (A2), U306.3 (A2), U308.3 (A2), U310.3 (A2)
/A4: D303.2 (A02), R330.2, U302.4 (A3), U306.4 (A3), U308.4 (A3), U310.4 (A3)
/A5: D303.1 (A01), R329.2, U302.5 (A4), U306.5 (A4), U308.5 (A4), U310.5 (A4)
/A6: D303.4 (A02), R328.2, U302.18 (A5), U306.18 (A5), U308.18 (A5), U310.18 (A5)
/A7: D303.5 (A12), R327.2, U302.19 (A6), U306.19 (A6), U308.19 (A6), U310.19 (A6)
/A8: D308.2 (A02), R351.2, U302.20 (A7), U306.20 (A7), U308.20 (A7), U310.20 (A7)
/A9: D308.1 (A01), R350.2, U302.21 (A8), U306.21 (A8), U308.21 (A8), U310.21 (A8)
/A10: D308.4 (A02), R349.2, U302.22 (A9), U306.22 (A9), U308.22 (A9), U310.22 (A9)
/A11: D308.5 (A12), R348.2, U302.23 (A10), U306.23 (A10), U308.23 (A10), U310.23 (A10)
/A12: D309.2 (A02), R347.2, U302.24 (A11), U306.24 (A11), U308.24 (A11), U310.24 (A11)
/A13: D309.1 (A01), R346.2, U302.25 (A12), U306.25 (A12), U308.25 (A12), U310.25 (A12)
/A14: D309.4 (A02), R345.2, U302.26 (A13), U306.26 (A13), U308.26 (A13), U310.26 (A13)
/A15: D309.5 (A12), R344.2, U302.27 (A14), U306.27 (A14), U308.27 (A14), U310.27 (A14)
/A16: D304.1 (A01), R342.2, U302.42 (A15), U306.42 (A15), U308.42 (A15), U310.42 (A15)
/A17: D304.5 (A12), R341.2, U302.43 (A16), U306.43 (A16), U308.43 (A16), U310.43 (A16)
/A18: D304.4 (A02), R340.2, U302.44 (A17), U306.44 (A17), U308.44 (A17), U310.44 (A17)
/A19: R339.2, U304.2 (A0), U309.2 (A0)
/A20: R338.2, U304.3 (A1), U309.3 (A1)
/B20: J102.18, J304.18, U303.3 (B0)
/B21: J102.16, J304.16, U303.5 (B1)
/B22: J102.14, J304.14, U303.7 (B2)
/B23: J102.12, J304.12, U303.9 (B3)
/B24: J102.10, J304.10, U303.12 (B4)
/B25: J102.8, J304.8, U303.14 (B5)
/B26: J102.6, J304.6, U303.16 (B6)
/B27: J102.4, J304.4, U303.18 (B7)
/D0: J101.18, J303.18, R316.1
/D1: J101.16, J303.16, R315.1
/D2: J101.14, J303.14, R314.1
/D3: J101.12, J303.12, R313.1
/D4: J101.10, J303.10, R312.1
/D5: J101.8, J303.8, R311.1
/D6: J101.6, J303.6, R310.1
/D7: J101.4, J303.4, R309.1
/LD0: D306.5 (A12), R318.2, U302.7 (IO0), U302.29 (IO8), U306.7 (IO0), U306.29 (IO8), U308.7 (IO0), U308.29 (IO8), U310.7 (IO0), U310.29 (IO8)
/LD1: D307.5 (A12), R319.2, U302.8 (IO1), U302.30 (IO9), U306.8 (IO1), U306.30 (IO9), U308.8 (IO1), U308.30 (IO9), U310.8 (IO1), U310.30 (IO9)
/LD2: D306.4 (A02), R320.2, U302.9 (IO2), U302.31 (IO10), U306.9 (IO2), U306.31 (IO10), U308.9 (IO2), U308.31 (IO10), U310.9 (IO2), U310.31 (IO10)
/LD3: D307.4 (A02), R321.2, U302.10 (IO3), U302.32 (IO11), U306.10 (IO3), U306.32 (IO11), U308.10 (IO3), U308.32 (IO11), U310.10 (IO3), U310.32 (IO11)
/LD4: D307.1 (A01), R322.2, U302.13 (IO4), U302.35 (IO12), U306.13 (IO4), U306.35 (IO12), U308.13 (IO4), U308.35 (IO12), U310.13 (IO4), U310.35 (IO12)
/LD5: D306.1 (A01), R323.2, U302.14 (IO5), U302.36 (IO13), U306.14 (IO5), U306.36 (IO13), U308.14 (IO5), U308.36 (IO13), U310.14 (IO5), U310.36 (IO13)
/LD6: D307.2 (A02), R324.2, U302.15 (IO6), U302.37 (IO14), U306.15 (IO6), U306.37 (IO14), U308.15 (IO6), U308.37 (IO14), U310.15 (IO6), U310.37 (IO14)
/LD7: D306.2 (A02), R325.2, U302.16 (IO7), U302.38 (IO15), U306.16 (IO7), U306.38 (IO15), U308.16 (IO7), U308.38 (IO15), U310.16 (IO7), U310.38 (IO15)
/P22: J101.22, J303.22
/P22a: J102.22, J304.22
/P24: J101.24, J303.24
/P24a: J102.24, J304.24
/P26: J101.26, J303.26
/P28: J101.28, J303.28
/P29: J101.29, J303.29
/PA00: J102.31, J304.31, U305.11 (2A3)
/PA01: J102.29, J304.29, U305.13 (2A2)
/PA02: J102.27, J304.27, U305.15 (2A1)
/PA03: J102.25, J304.25, U305.17 (2A0)
/PA04: J102.23, J304.23, U305.8 (1A3)
/PA05: J102.21, J304.21, U305.6 (1A2)
/PA06: J102.19, J304.19, U305.4 (1A1)
/PA07: J102.17, J304.17, U305.2 (1A0)
/PA08: J102.13, J304.13, U311.11 (2A3)
/PA09: J102.11, J304.11, U311.13 (2A2)
/PA10: J102.9, J304.9, U311.15 (2A1)
/PA11: J102.7, J304.7, U311.17 (2A0)
/PA12: J102.5, J304.5, U311.8 (1A3)
/PA13: J102.3, J304.3, U311.6 (1A2)
/PA14: J101.25, J303.25, U311.4 (1A1)
/PA15: J101.23, J303.23, U311.2 (1A0)
/PA16: J101.21, J303.21, U307.11 (2A3)
/PA17: J101.19, J303.19, U307.13 (2A2)
/PA18: J101.17, J303.17, U307.15 (2A1)
/PA19: J101.15, J303.15, U307.17 (2A0)
/PA20: J101.13, J303.13, U307.8 (1A3)
/PA21: J101.11, J303.11
/PHI2_5: J102.28, J304.28, U307.6 (1A2)
/RW_3: R335.2, U309.14 (A0)
/R/~W: J101.30, J303.30, U307.2 (1A0)
/~A0: U302.40 (~BHE), U304.12 (O0), U306.40 (~BHE), U308.40 (~BHE), U310.40 (~BHE)
/~OE0: U302.41 (~OE), U309.4 (O0)
/~OE1: U306.41 (~OE), U309.5 (O1)
/~OE2: U308.41 (~OE), U309.6 (O2)
/~OE3: U309.7 (O3), U310.41 (~OE)
/~OE: U309.1 (E), U309.12 (O0)
/~RAMEN_3: JP301.2 (B), R336.2, U304.1 (E), U309.15 (E)
/~RAMEN_5: U303.19 (~A=B), U307.4 (1A1)
/~WE: U302.17 (~WE), U306.17 (~WE), U308.17 (~WE), U309.11 (O1), U310.17 (~WE)
GND: C301.2, C302.2, C303.2, C304.2, C305.2, C306.2, C307.2, C308.2, C309.2, C310.2, C311.2, C312.2, C313.2, C314.2, C315.2, C316.2, C317.2, C318.2, C319.2, C320.2, C321.2, C322.2, C323.2, C324.2, C325.2, C326.2, C327.2, C328.2, C329.2, D301.1 (K), J101.2, J101.9, J101.20, J101.27, J101.31, J101.32, J102.1, J102.2, J102.15, J102.20, J102.26, J102.30, J102.32, J103.1, J103.3, J103.5, J103.7, J103.9, J103.11, J103.13, J103.15, J303.2, J303.9, J303.20, J303.27, J303.31, J303.32, J304.1, J304.2, J304.15, J304.20, J304.26, J304.30, J304.32, R326.1, U301.11 (GND), U302.12 (GND), U302.34 (GND), U303.1 (~EN), U303.10 (GND), U304.8 (GND), U304.13 (A1), U304.15 (E), U305.1 (1~OE), U305.10 (GND), U305.19 (2~OE), U306.12 (GND), U306.34 (GND), U307.1 (1~OE), U307.10 (GND), U307.19 (2~OE), U308.12 (GND), U308.34 (GND), U309.8 (GND), U310.12 (GND), U310.34 (GND), U311.1 (1~OE), U311.10 (GND), U311.19 (2~OE)
unnamed: D301.2 (A), R317.2
unnamed: J103.2, R352.2, U303.2 (A0)
unnamed: J103.4, R353.2, U303.4 (A1)
unnamed: J103.6, R354.2, U303.6 (A2)
unnamed: J103.8, R355.2, U303.8 (A3)
unnamed: J103.10, R356.2, U303.11 (A4)
unnamed: J103.12, R357.2, U303.13 (A5)
unnamed: J103.14, R358.2, U303.15 (A6)
unnamed: J103.16, R359.2, U303.17 (A7)
unnamed: JP301.1 (A), R326.2, U301.10 (OE)
unnamed: R318.1, U301.1 (A1)
unnamed: R319.1, U301.3 (A2)
unnamed: R320.1, U301.4 (A3)
unnamed: R321.1, U301.5 (A4)
unnamed: R322.1, U301.6 (A5)
unnamed: R323.1, U301.7 (A6)
unnamed: R324.1, U301.8 (A7)
unnamed: R325.1, U301.9 (A8)
unnamed: R309.2, U301.20 (B1)
unnamed: R310.2, U301.18 (B2)
unnamed: R311.2, U301.17 (B3)
unnamed: R312.2, U301.16 (B4)
unnamed: R313.2, U301.15 (B5)
unnamed: R314.2, U301.14 (B6)
unnamed: R315.2, U301.13 (B7)
unnamed: R316.2, U301.12 (B8)
unnamed: U302.6 (~CE), U304.4 (O0)
unnamed: U304.5 (O1), U306.6 (~CE)
unnamed: U304.6 (O2), U308.6 (~CE)
unnamed: U304.7 (O3), U310.6 (~CE)
unnamed: R330.1, U305.18 (1Y0)
unnamed: R329.1, U305.16 (1Y1)
unnamed: R328.1, U305.14 (1Y2)
unnamed: R327.1, U305.12 (1Y3)
unnamed: R334.1, U305.3 (2Y0)
unnamed: R333.1, U305.5 (2Y1)
unnamed: R332.1, U305.7 (2Y2)
unnamed: R331.1, U305.9 (2Y3)
unnamed: R338.1, U307.18 (1Y0)
unnamed: R337.1, U307.16 (1Y1)
unnamed: R336.1, U307.14 (1Y2)
unnamed: R335.1, U307.12 (1Y3)
unnamed: R342.1, U307.3 (2Y0)
unnamed: R341.1, U307.5 (2Y1)
unnamed: R340.1, U307.7 (2Y2)
unnamed: R339.1, U307.9 (2Y3)
unnamed: R347.1, U311.18 (1Y0)
unnamed: R346.1, U311.16 (1Y1)
unnamed: R345.1, U311.14 (1Y2)
unnamed: R344.1, U311.12 (1Y3)
unnamed: R351.1, U311.3 (2Y0)
unnamed: R350.1, U311.5 (2Y1)
unnamed: R349.1, U311.7 (2Y2)
unnamed: R348.1, U311.9 (2Y3)

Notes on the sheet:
SRAM Data Overvolt Protection Supply ON
Superbank Select
CY7C1041DV33
To ensure mutual exclusion between BLE and BHE
Bidirectional Data

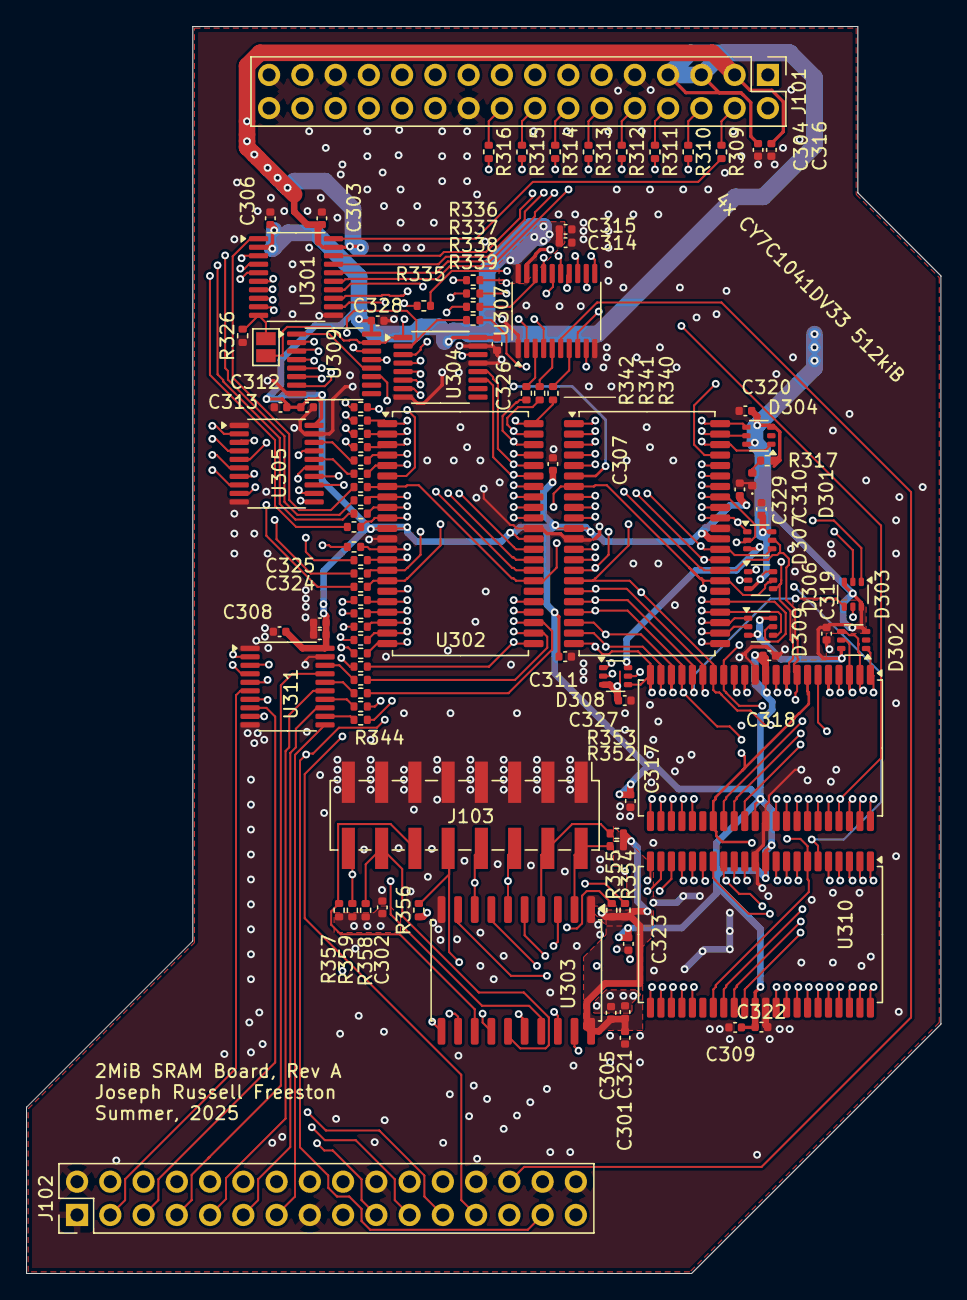
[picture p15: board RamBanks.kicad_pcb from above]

Board: 4 copper layers, 69.8 x 95.2 mm, 102 parts (0 on the bottom side), 138 nets.

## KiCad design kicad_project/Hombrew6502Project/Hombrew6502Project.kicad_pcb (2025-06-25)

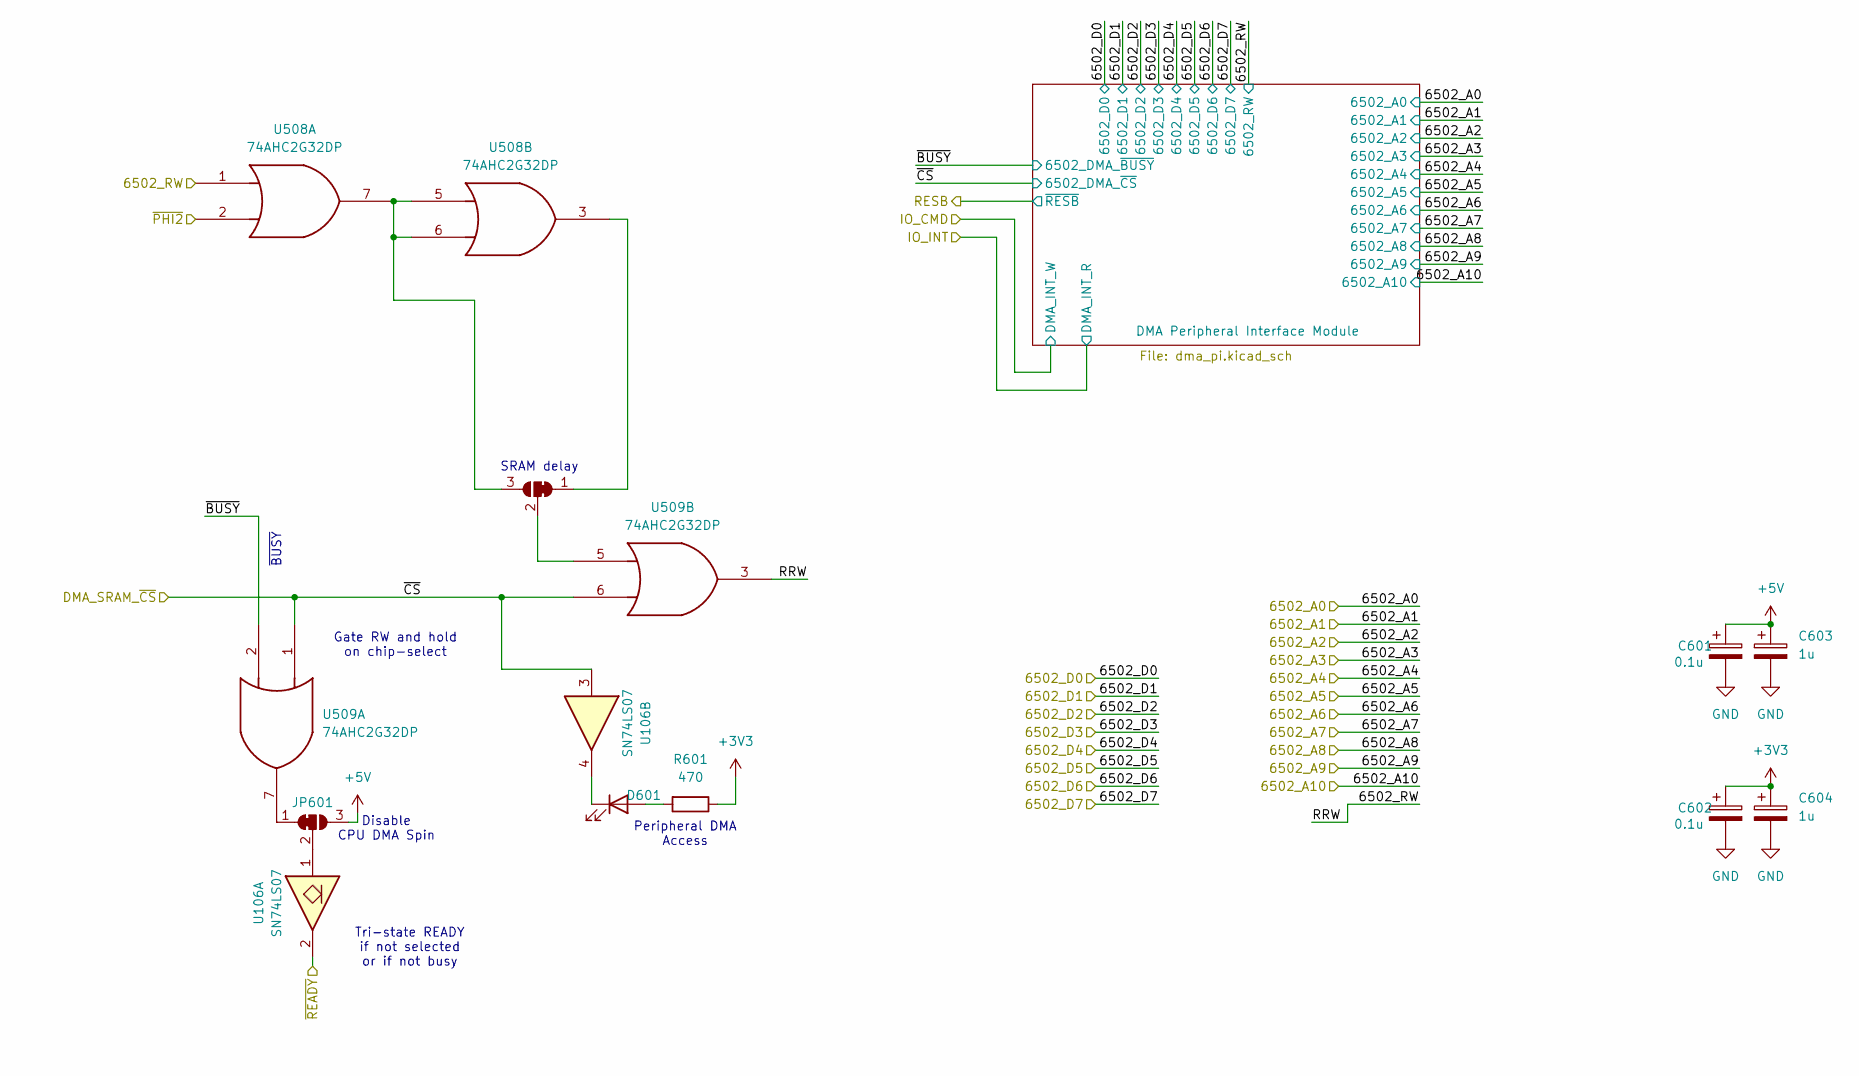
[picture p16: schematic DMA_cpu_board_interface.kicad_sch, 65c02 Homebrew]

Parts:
C601, C602: 0.1u; C_0402_1005Metric
C603, C604: 1u; C_0402_1005Metric
D601: LED; LED_0402_1005Metric
JP601, JP602: SolderJumper_3_Bridged12; SolderJumper-3_P1.3mm_Bridged12_Pad1.0x1.5mm
R601: 470; R_0402_1005Metric
U106: SN74LS07; SOIC-14_3.9x8.7mm_P1.27mm
U508, U509: 74AHC2G32DP; TSSOP-8_3x3mm_P0.65mm

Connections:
+3V3: C602.1, C604.1, R601.1; also elsewhere on the board
+5V: C601.1, C603.1, JP601.3 (B); also elsewhere on the board
/DMA Peripheral Interface/~BUSY: U509.2; also elsewhere on the board
/RDY: U106.2; also elsewhere on the board
/R~W: U508.1, U509.3; also elsewhere on the board
/~DMA_CS: U106.3, U509.1, U509.6; also elsewhere on the board
/~PHI2: U508.2; also elsewhere on the board
GND: C601.2, C602.2, C603.2, C604.2; also elsewhere on the board
unnamed: D601.2 (A), R601.2
unnamed: D601.1 (K), U106.4
unnamed: JP601.1 (A), U509.7
unnamed: JP601.2 (C), U106.1
unnamed: JP602.1 (A), U508.3
unnamed: JP602.3 (B), U508.5, U508.6, U508.7
unnamed: JP602.2 (C), U509.5

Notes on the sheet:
SRAM delay
Gate RW and hold on chip-select
Tri-state READY if not selected or if not busy
~{BUSY}
Disable CPU DMA Spin
Peripheral DMA Access

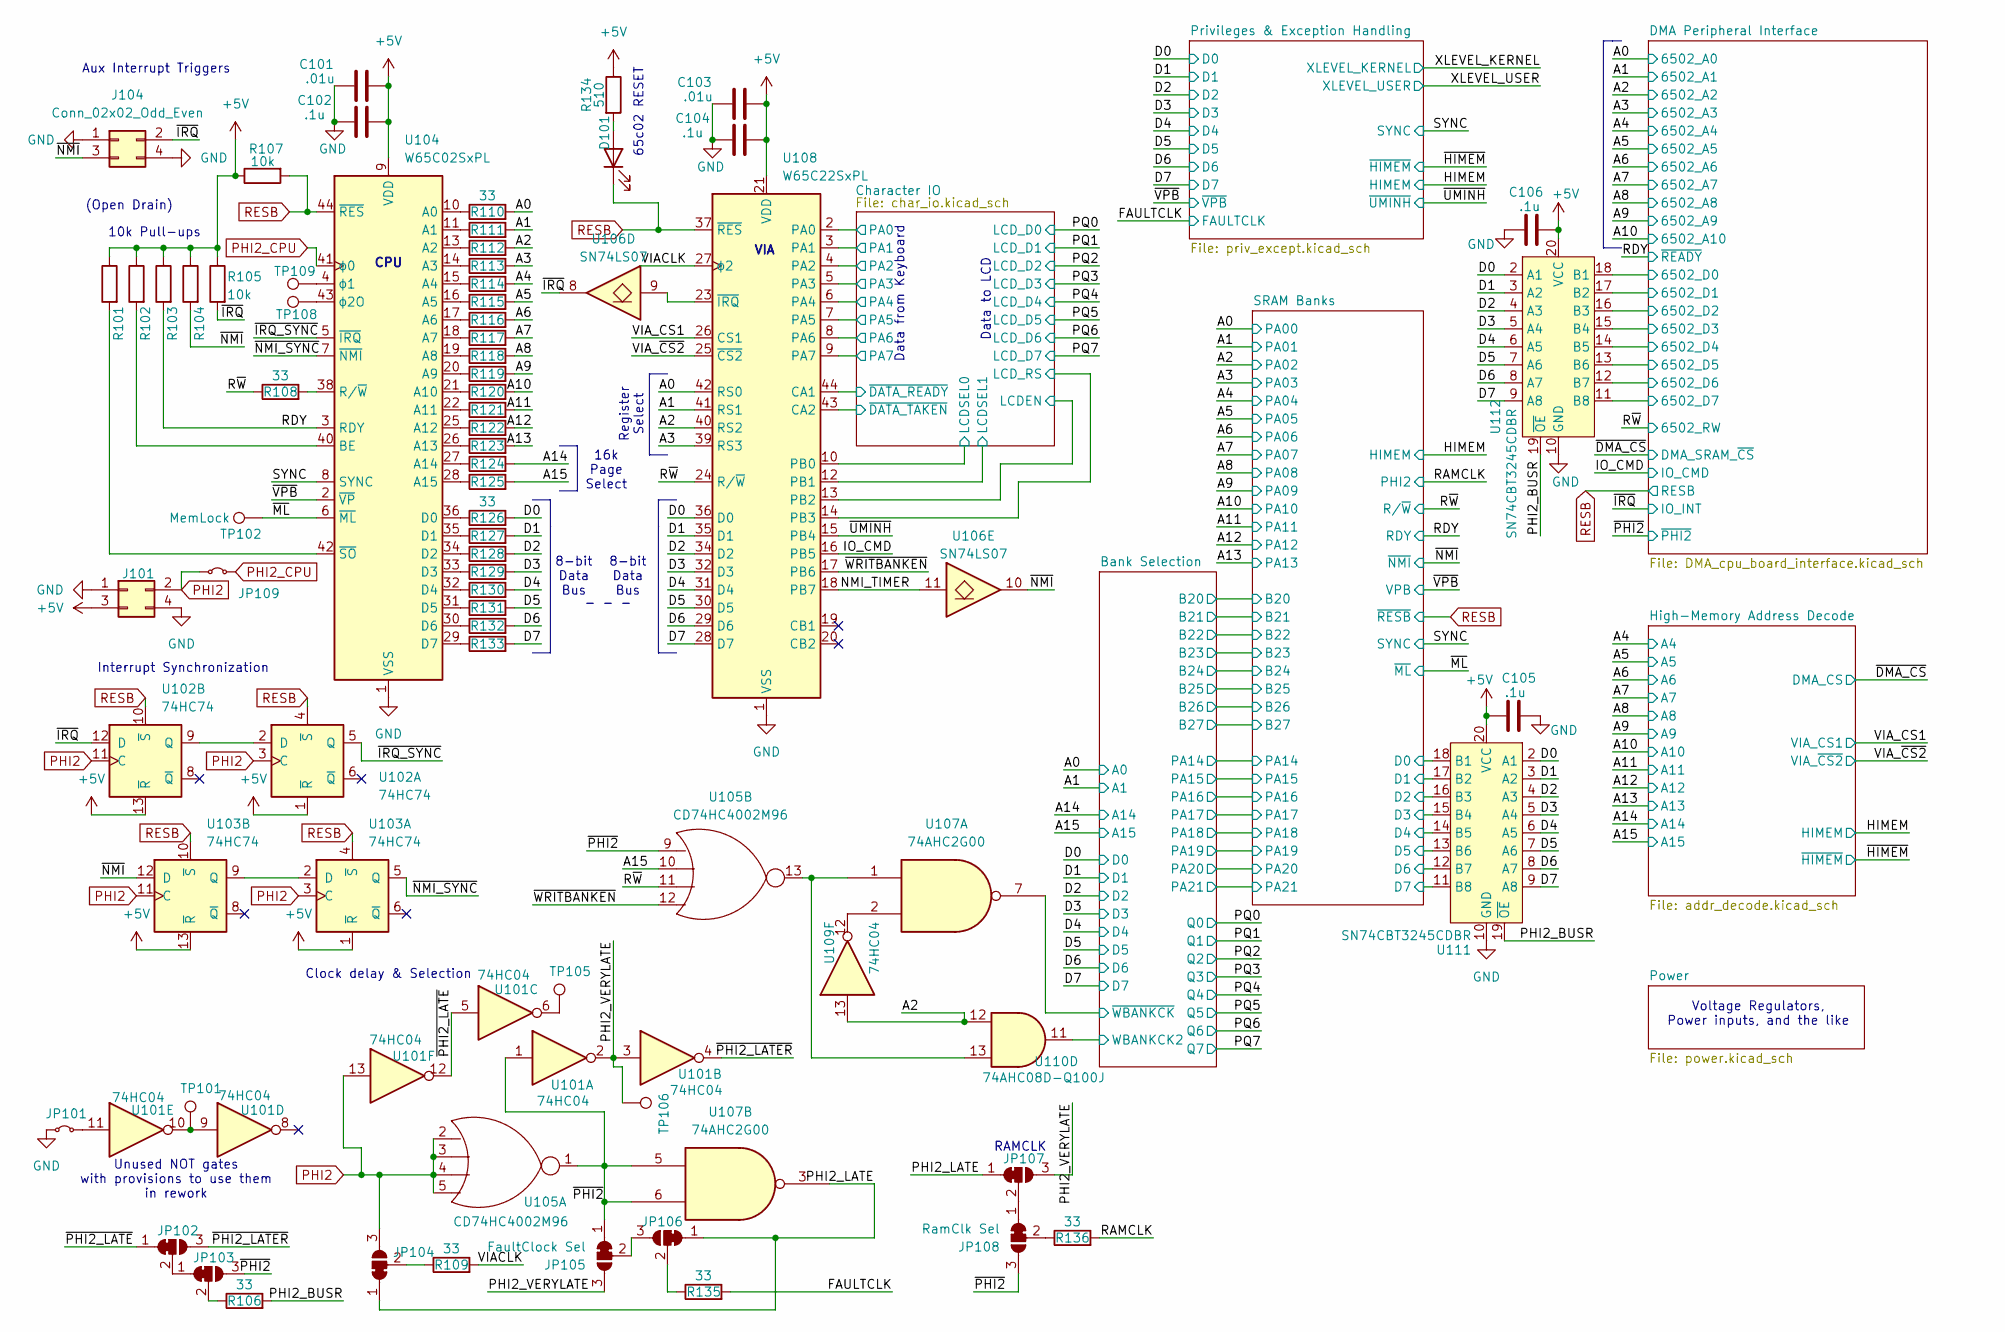
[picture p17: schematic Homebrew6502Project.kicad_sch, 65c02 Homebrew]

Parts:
C101, C103: .01u; C_0402_1005Metric
C102, C104, C105, C106: .1u; C_0402_1005Metric
D101: LED; LED_0402_1005Metric
J101, J104: Conn_02x02_Odd_Even; PinHeader_2x02_P2.54mm_Vertical_SMD
JP101, JP109: Jumper_2_Small_Bridged; SolderJumper-2_P1.3mm_Bridged2Bar_Pad1.0x1.5mm
JP102, JP103, JP105, JP106, JP107: FaultClock Sel; SolderJumper-3_P1.3mm_Bridged12_Pad1.0x1.5mm
JP104: SolderJumper_3_Bridged12; SolderJumper-3_P1.3mm_Bridged12_Pad1.0x1.5mm
JP108: RamClk Sel; SolderJumper-3_P1.3mm_Bridged12_Pad1.0x1.5mm
R101, R102, R103, R104, R105, R107: 10k; R_0402_1005Metric
R106, R108, R109, R110, R111, R112, R113, R114, R115, R116, R117, R118, R119, R120, R121, R122, R123, R124, R125, R126, R127, R128, R129, R130, R131, R132, R133, R135, R136: 33; R_0402_1005Metric
R134: 510; R_0402_1005Metric
TP101: TestPoint; TestPoint_Pad_D2.5mm
TP102: MemLock; TestPoint_Pad_D1.5mm
TP105, TP106: TestPoint; TestPoint_Pad_D1.5mm
TP108: phi2O; TestPoint_Pad_D1.5mm
TP109: phi1; TestPoint_Pad_D1.5mm
U101, U109: 74HC04; SOIC-14_3.9x8.7mm_P1.27mm
U102, U103: 74HC74; SOIC-14_3.9x8.7mm_P1.27mm
U104: W65C02SxPL; PLCC-44
U105: CD74HC4002M96; SOIC-14_3.9x8.7mm_P1.27mm
U106: SN74LS07; SOIC-14_3.9x8.7mm_P1.27mm
U107: 74AHC2G00; TSSOP-8_3x3mm_P0.65mm
U108: W65C22SxPL; PLCC-44
U110: 74AHC08D-Q100J; SOIC-14_3.9x8.7mm_P1.27mm
U111, U112: SN74CBT3245CDBR; SSOP-20_5.3x7.2mm_P0.65mm

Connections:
+5V: C101.1, C102.1, C103.1, C104.1, C105.1, C106.1, J101.3, R101.1, R102.1, R103.1, R104.1, R105.1, R107.1, R134.1, U102.1 (~R), U102.13 (~R), U103.1 (~R), U103.13 (~R), U104.9 (VDD), U104.37 (VDD), U108.21 (VDD), U111.20 (VCC), U112.20 (VCC); also elsewhere on the board
/A0: R110.2, U108.42 (RS0); also elsewhere on the board
/A1: R111.2, U108.41 (RS1); also elsewhere on the board
/A2: R112.2, U108.40 (RS2), U109.13, U110.12; also elsewhere on the board
/A3: R113.2, U108.39 (RS3); also elsewhere on the board
/A4: R114.2; also elsewhere on the board
/A5: R115.2; also elsewhere on the board
/A6: R116.2; also elsewhere on the board
/A7: R117.2; also elsewhere on the board
/A8: R118.2; also elsewhere on the board
/A9: R119.2; also elsewhere on the board
/A10: R120.2; also elsewhere on the board
/A11: R121.2; also elsewhere on the board
/A12: R122.2; also elsewhere on the board
/A13: R123.2; also elsewhere on the board
/A14: R124.2; also elsewhere on the board
/A15: R125.2, U105.10; also elsewhere on the board
/Bank Selection/WBANKCK2: U110.11; also elsewhere on the board
/Bank Selection/~WBANKCK: U107.7; also elsewhere on the board
/Character IO/LCDEN: U108.13 (PB2); also elsewhere on the board
/Character IO/LCDSEL0: U108.10 (PB0); also elsewhere on the board
/Character IO/LCDSEL1: U108.12 (PB1); also elsewhere on the board
/Character IO/LCD_RS: U108.14 (PB3); also elsewhere on the board
/Character IO/PA0: U108.2 (PA0); also elsewhere on the board
/Character IO/PA1: U108.3 (PA1); also elsewhere on the board
/Character IO/PA2: U108.4 (PA2); also elsewhere on the board
/Character IO/PA3: U108.5 (PA3); also elsewhere on the board
/Character IO/PA4: U108.6 (PA4); also elsewhere on the board
/Character IO/PA5: U108.7 (PA5); also elsewhere on the board
/Character IO/PA6: U108.8 (PA6); also elsewhere on the board
/Character IO/PA7: U108.9 (PA7); also elsewhere on the board
/Character IO/~DATA_READY: U108.44 (CA1); also elsewhere on the board
/Character IO/~DATA_TAKEN: U108.43 (CA2); also elsewhere on the board
/D0: R126.2, U108.36 (D0), U111.2 (A1), U112.2 (A1); also elsewhere on the board
/D1: R127.2, U108.35 (D1), U111.3 (A2), U112.3 (A2); also elsewhere on the board
/D2: R128.2, U108.34 (D2), U111.4 (A3), U112.4 (A3); also elsewhere on the board
/D3: R129.2, U108.32 (D3), U111.5 (A4), U112.5 (A4); also elsewhere on the board
/D4: R130.2, U108.31 (D4), U111.6 (A5), U112.6 (A5); also elsewhere on the board
/D5: R131.2, U108.30 (D5), U111.7 (A6), U112.7 (A6); also elsewhere on the board
/D6: R132.2, U108.29 (D6), U111.8 (A7), U112.8 (A7); also elsewhere on the board
/D7: R133.2, U108.28 (D7), U111.9 (A8), U112.9 (A8); also elsewhere on the board
/DMA Peripheral Interface/6502_D0: U112.18 (B1); also elsewhere on the board
/DMA Peripheral Interface/6502_D1: U112.17 (B2); also elsewhere on the board
/DMA Peripheral Interface/6502_D2: U112.16 (B3); also elsewhere on the board
/DMA Peripheral Interface/6502_D3: U112.15 (B4); also elsewhere on the board
/DMA Peripheral Interface/6502_D4: U112.14 (B5); also elsewhere on the board
/DMA Peripheral Interface/6502_D5: U112.13 (B6); also elsewhere on the board
/DMA Peripheral Interface/6502_D6: U112.12 (B7); also elsewhere on the board
/DMA Peripheral Interface/6502_D7: U112.11 (B8); also elsewhere on the board
/FAULTCLK: R135.2; also elsewhere on the board
/IO_CMD: U108.16 (PB5); also elsewhere on the board
/NMI_TIMER: U106.11, U108.18 (PB7)
/PHI2_BUSR: R106.2, U111.19 (~OE), U112.19 (~OE)
/PHI2_LATE: JP104.1 (A), JP106.1 (A), JP107.1 (A), U107.3
/PHI2_VERYLATE: JP105.3 (B), JP107.3 (B), TP106.1, U101.2, U101.3
/RAMCLK: R136.2; also elsewhere on the board
/RDY: R103.2, U104.3 (RDY); also elsewhere on the board
/R~W: R108.1, U105.11, U108.24 (R/~W); also elsewhere on the board
/SRAM Banks/D0: U111.18 (B1); also elsewhere on the board
/SRAM Banks/D1: U111.17 (B2); also elsewhere on the board
/SRAM Banks/D2: U111.16 (B3); also elsewhere on the board
/SRAM Banks/D3: U111.15 (B4); also elsewhere on the board
/SRAM Banks/D4: U111.14 (B5); also elsewhere on the board
/SRAM Banks/D5: U111.13 (B6); also elsewhere on the board
/SRAM Banks/D6: U111.12 (B7); also elsewhere on the board
/SRAM Banks/D7: U111.11 (B8); also elsewhere on the board
/SYNC: U104.8 (SYNC); also elsewhere on the board
/VIACLK: R109.2, U108.27 (ϕ2)
/VIA_CS1: U108.26 (CS1); also elsewhere on the board
/VIA_~CS2: U108.25 (~CS2); also elsewhere on the board
/~IRQ_SYNC: U102.5 (Q), U104.5 (~IRQ)
/~IRQ: J104.2, R105.2, U102.12 (D), U106.8; also elsewhere on the board
/~ML: TP102.1, U104.6 (~ML); also elsewhere on the board
/~NMI_SYNC: U103.5 (Q), U104.7 (~NMI)
/~NMI: J104.3, R104.2, U103.12 (D), U106.10; also elsewhere on the board
/~PHI2_LATER: JP102.3 (B), U101.4
/~PHI2_LATE: JP102.1 (A), U101.5, U101.12
/~PHI2: JP103.3 (B), JP105.1 (A), JP108.3 (B), U101.1, U105.1, U105.9, U107.5, U107.6; also elsewhere on the board
/~UMINH: U108.15 (PB4); also elsewhere on the board
/~VPB: U104.2 (~VP); also elsewhere on the board
/~WRITBANKEN: U105.12, U108.17 (PB6)
GND: C101.2, C102.2, C103.2, C104.2, C105.2, C106.2, J101.1, J101.4, J104.1, J104.4, JP101.1 (A), U104.1 (VSS), U104.23 (VSS), U104.24 (VSS), U108.1 (VSS), U111.10 (GND), U112.10 (GND); also elsewhere on the board
unnamed: D101.2 (A), R134.2
unnamed: JP101.2 (B), U101.11
unnamed: JP102.2 (C), JP103.1 (A)
unnamed: JP103.2 (C), R106.1
unnamed: JP104.2 (C), R109.1
unnamed: JP105.2 (C), JP106.3 (B)
unnamed: JP106.2 (C), R135.1
unnamed: JP107.2 (C), JP108.1 (A)
unnamed: JP108.2 (C), R136.1
unnamed: TP101.1, U101.9, U101.10
unnamed 287: U101.8; also elsewhere on the board
unnamed: TP105.1, U101.6
unnamed: U102.2 (D), U102.9 (Q)
unnamed: U103.2 (D), U103.9 (Q)
unnamed: R110.1, U104.10 (A0)
unnamed: R111.1, U104.11 (A1)
unnamed: R112.1, U104.13 (A2)
unnamed: R113.1, U104.14 (A3)
unnamed: R114.1, U104.15 (A4)
unnamed: R115.1, U104.16 (A5)
unnamed: R116.1, U104.17 (A6)
unnamed: R117.1, U104.18 (A7)
unnamed: R118.1, U104.19 (A8)
unnamed: R119.1, U104.20 (A9)
unnamed: R120.1, U104.21 (A10)
unnamed: R121.1, U104.22 (A11)
unnamed: R122.1, U104.25 (A12)
unnamed: R123.1, U104.26 (A13)
unnamed: R124.1, U104.27 (A14)
unnamed: R125.1, U104.28 (A15)
unnamed: R102.2, U104.40 (BE)
unnamed: R126.1, U104.36 (D0)
unnamed: R127.1, U104.35 (D1)
unnamed: R128.1, U104.34 (D2)
unnamed: R129.1, U104.33 (D3)
unnamed: R130.1, U104.32 (D4)
unnamed: R131.1, U104.31 (D5)
unnamed: R132.1, U104.30 (D6)
unnamed: R133.1, U104.29 (D7)
unnamed: R108.2, U104.38 (R/~W)
unnamed: R101.2, U104.42 (~SO)
unnamed: TP109.1, U104.4 (ϕ1)
unnamed: TP108.1, U104.43 (ϕ2O)
unnamed: U105.13, U107.1, U110.13
unnamed: U107.2, U109.12
unnamed: U106.9, U108.23 (~IRQ)
PHI2: J101.2, JP104.3 (B), JP109.1 (A), U101.13, U102.3 (C), U102.11 (C), U103.3 (C), U103.11 (C), U105.2, U105.3, U105.4, U105.5
PHI2_CPU: JP109.2 (B), U104.41 (ϕ0)
RESB: D101.1 (K), R107.2, U102.4 (~S), U102.10 (~S), U103.4 (~S), U103.10 (~S), U104.44 (~RES), U108.37 (~RES); also elsewhere on the board

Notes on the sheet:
Data to LCD
65c02 RESET
(Open Drain)
VIA
10k Pull-ups
Clock delay & Selection
8-bit Data Bus
- - -
CPU
Register Select
RAMCLK
Data from Keyboard
Aux Interrupt Triggers
Unused NOT gates with provisions to use them in rework
16k Page Select
Interrupt Synchronization
Voltage Regulators, Power inputs, and the like

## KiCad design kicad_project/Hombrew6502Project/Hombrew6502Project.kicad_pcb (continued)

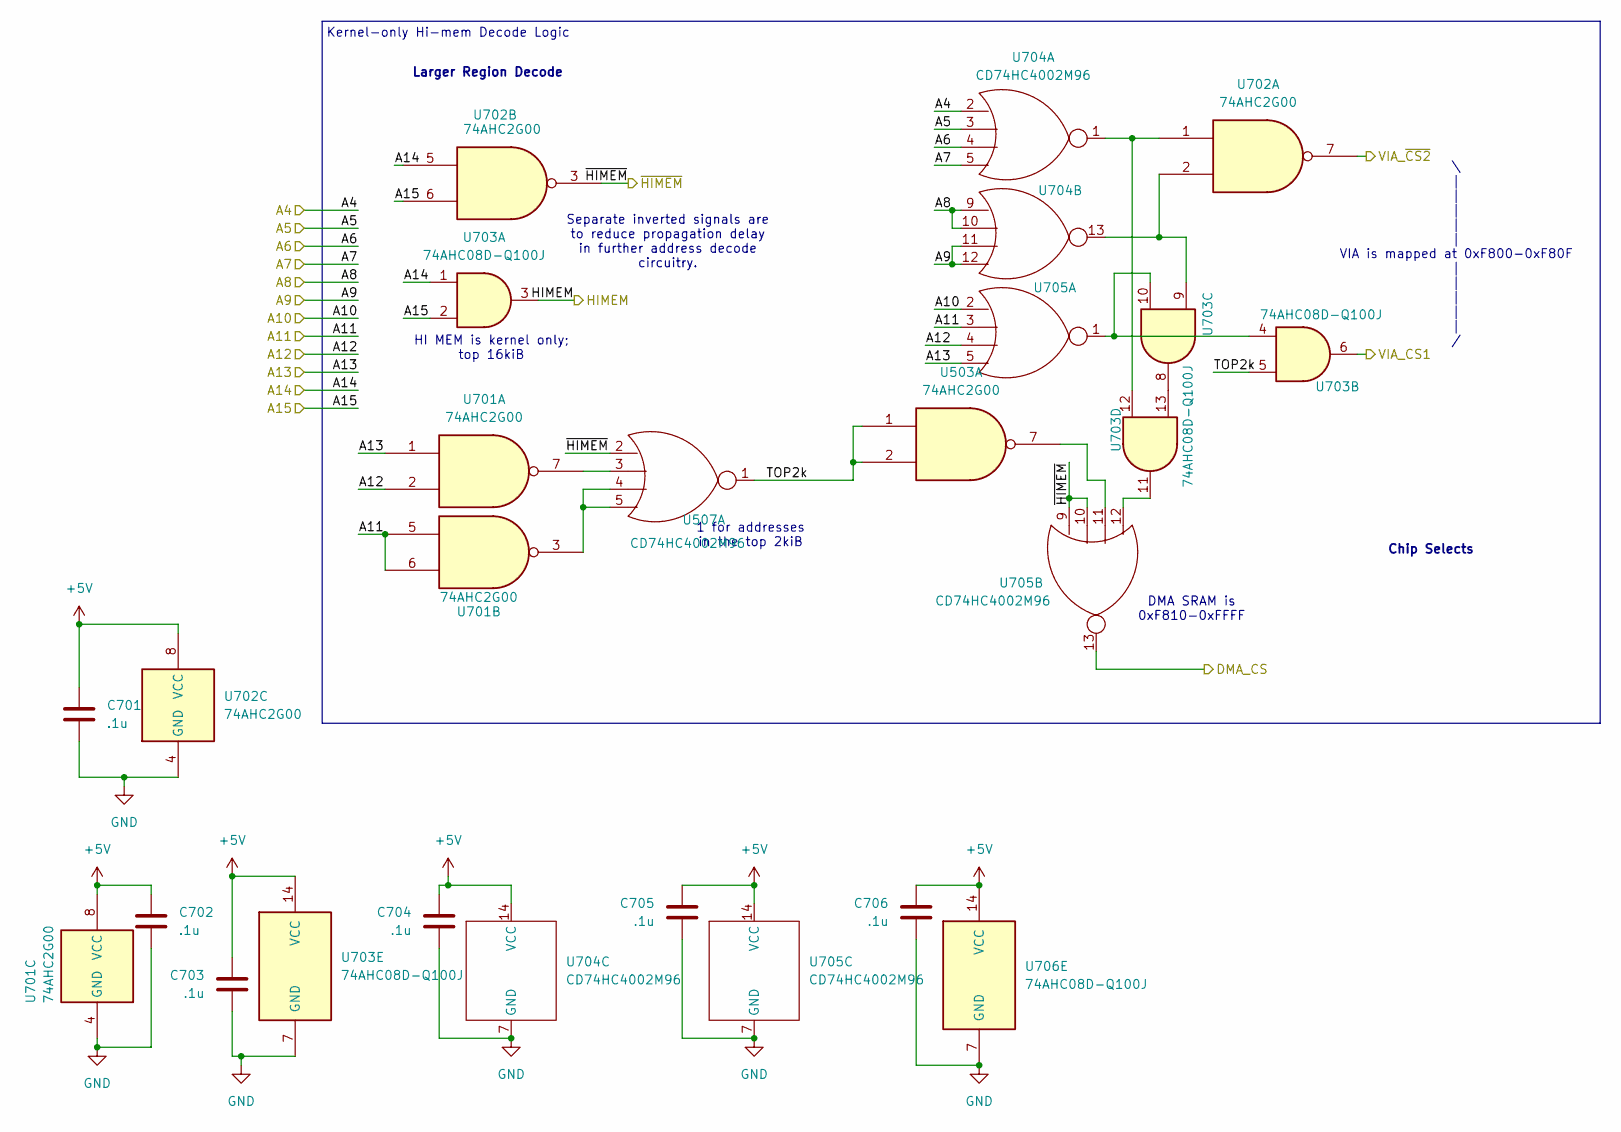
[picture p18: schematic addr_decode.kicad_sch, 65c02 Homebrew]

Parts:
C701, C702, C703, C704, C705, C706: .1u; C_0402_1005Metric
U503, U701, U702: 74AHC2G00; TSSOP-8_3x3mm_P0.65mm
U507, U704, U705: CD74HC4002M96; SOIC-14_3.9x8.7mm_P1.27mm
U703, U706: 74AHC08D-Q100J; SOIC-14_3.9x8.7mm_P1.27mm

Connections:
+5V: C701.1, C702.1, C703.1, C704.1, C705.1, C706.1, U701.8 (VCC), U702.8 (VCC), U703.14 (VCC), U704.14 (VCC), U705.14 (VCC), U706.14 (VCC); also elsewhere on the board
/A4: U704.2; also elsewhere on the board
/A5: U704.3; also elsewhere on the board
/A6: U704.4; also elsewhere on the board
/A7: U704.5; also elsewhere on the board
/A8: U704.9, U704.10; also elsewhere on the board
/A9: U704.11, U704.12; also elsewhere on the board
/A10: U705.2; also elsewhere on the board
/A11: U701.5, U701.6, U705.3; also elsewhere on the board
/A12: U701.2, U705.4; also elsewhere on the board
/A13: U701.1, U705.5; also elsewhere on the board
/A14: U702.5, U703.1; also elsewhere on the board
/A15: U702.6, U703.2; also elsewhere on the board
/HIMEM: U703.3; also elsewhere on the board
/High-Memory Address Decode/TOP2k: U503.1, U503.2, U507.1, U703.5
/VIA_CS1: U703.6; also elsewhere on the board
/VIA_~CS2: U702.7; also elsewhere on the board
/~DMA_CS: U705.13; also elsewhere on the board
/~HIMEM: U507.2, U702.3, U705.9, U705.10; also elsewhere on the board
GND: C701.2, C702.2, C703.2, C704.2, C705.2, C706.2, U701.4 (GND), U702.4 (GND), U703.7 (GND), U704.7 (GND), U705.7 (GND), U706.7 (GND); also elsewhere on the board
unnamed: U503.7, U705.11
unnamed: U507.3, U701.7
unnamed: U507.4, U507.5, U701.3
unnamed: U702.1, U703.12, U704.1
unnamed: U702.2, U703.9, U704.13
unnamed: U703.4, U703.10, U705.1
unnamed: U703.11, U705.12
unnamed: U703.8, U703.13

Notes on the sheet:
Larger Region Decode
Separate inverted signals are to reduce propagation delay in further address decode circuitry.
HI MEM is kernel only; top 16kiB
Chip Selects
Kernel-only Hi-mem Decode Logic
\ | | | | | VIA is mapped at 0xF800-0xF80F | | | | | /
1 for addresses in the top 2kiB
DMA SRAM is 0xF810-0xFFFF

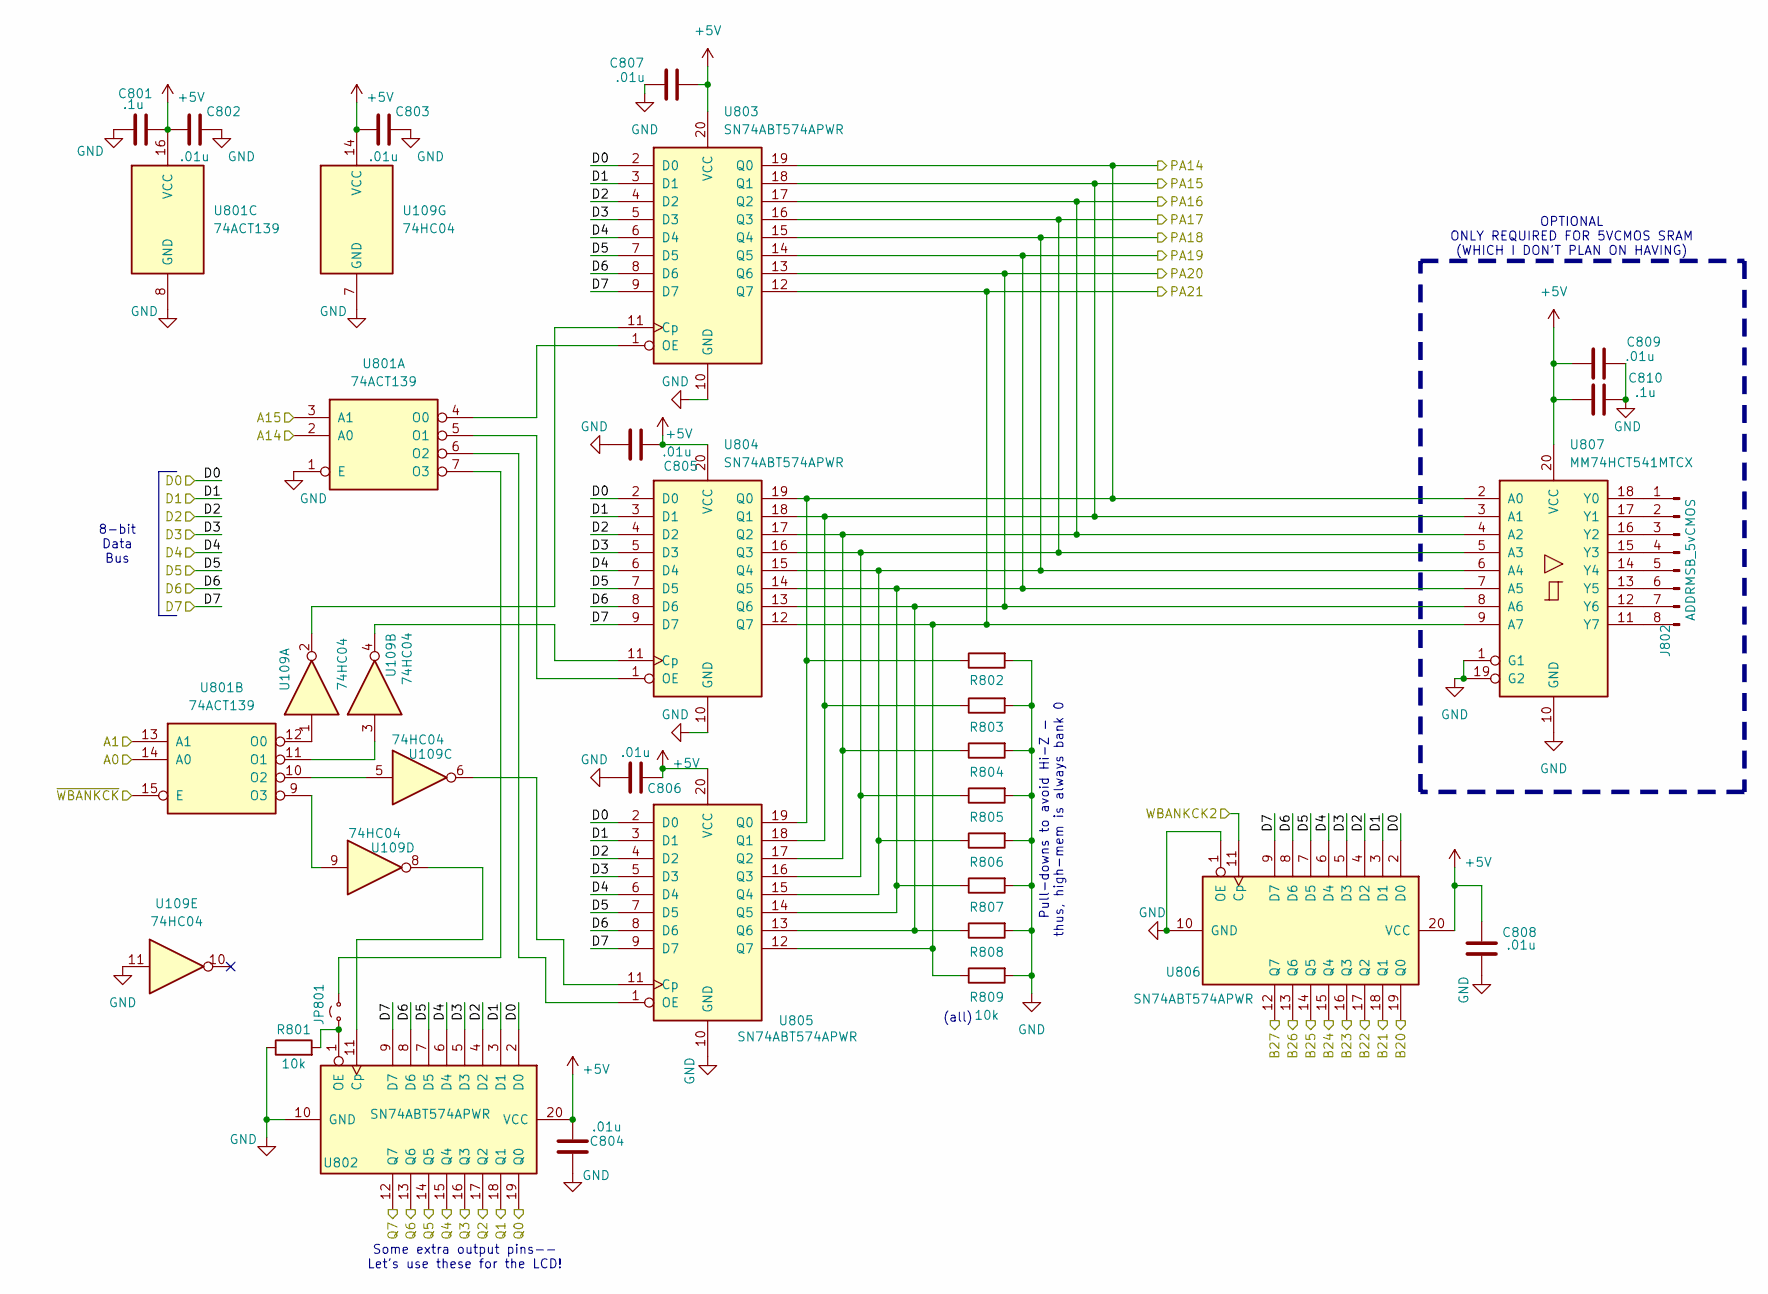
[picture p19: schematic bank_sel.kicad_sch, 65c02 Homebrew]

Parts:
C801: .1u; C_0402_1005Metric
C802, C803, C804, C805, C806, C807, C808: .01u; C_0402_1005Metric
C809: .01u
C810: .1u
J802: ADDRMSB_5vCMOS
JP801: Jumper_2_Small_Open; SolderJumper-2_P1.3mm_Open_Pad1.0x1.5mm
R801, R802, R803, R804, R805, R806, R807, R808, R809: 10k; R_0402_1005Metric
U109: 74HC04; SOIC-14_3.9x8.7mm_P1.27mm
U801: 74ACT139; TSSOP-16_4.4x5mm_P0.65mm
U802, U803, U804, U805, U806: SN74ABT574APWR; TSSOP-20_4.4x6.5mm_P0.65mm
U807: MM74HCT541MTCX

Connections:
+5V: C801.2, C802.1, C803.1, C804.2, C805.2, C806.2, C807.1, C808.2, C809.1, C810.1, U109.14 (VCC), U801.16 (VCC), U802.20 (VCC), U803.20 (VCC), U804.20 (VCC), U805.20 (VCC), U806.20 (VCC), U807.20 (VCC); also elsewhere on the board
/A0: U801.14 (A0); also elsewhere on the board
/A1: U801.13 (A1); also elsewhere on the board
/A14: U801.2 (A0); also elsewhere on the board
/A15: U801.3 (A1); also elsewhere on the board
/Bank Selection/WBANKCK2: U806.11 (Cp); also elsewhere on the board
/Bank Selection/~WBANKCK: U801.15 (E); also elsewhere on the board
/D0: U802.2 (D0), U803.2 (D0), U804.2 (D0), U805.2 (D0), U806.2 (D0); also elsewhere on the board
/D1: U802.3 (D1), U803.3 (D1), U804.3 (D1), U805.3 (D1), U806.3 (D1); also elsewhere on the board
/D2: U802.4 (D2), U803.4 (D2), U804.4 (D2), U805.4 (D2), U806.4 (D2); also elsewhere on the board
/D3: U802.5 (D3), U803.5 (D3), U804.5 (D3), U805.5 (D3), U806.5 (D3); also elsewhere on the board
/D4: U802.6 (D4), U803.6 (D4), U804.6 (D4), U805.6 (D4), U806.6 (D4); also elsewhere on the board
/D5: U802.7 (D5), U803.7 (D5), U804.7 (D5), U805.7 (D5), U806.7 (D5); also elsewhere on the board
/D6: U802.8 (D6), U803.8 (D6), U804.8 (D6), U805.8 (D6), U806.8 (D6); also elsewhere on the board
/D7: U802.9 (D7), U803.9 (D7), U804.9 (D7), U805.9 (D7), U806.9 (D7); also elsewhere on the board
/PQ0: U802.19 (Q0); also elsewhere on the board
/PQ1: U802.18 (Q1); also elsewhere on the board
/PQ2: U802.17 (Q2); also elsewhere on the board
/PQ3: U802.16 (Q3); also elsewhere on the board
/PQ4: U802.15 (Q4); also elsewhere on the board
/PQ5: U802.14 (Q5); also elsewhere on the board
/PQ6: U802.13 (Q6); also elsewhere on the board
/PQ7: U802.12 (Q7); also elsewhere on the board
/SRAM Banks/B20: U806.19 (Q0); also elsewhere on the board
/SRAM Banks/B21: U806.18 (Q1); also elsewhere on the board
/SRAM Banks/B22: U806.17 (Q2); also elsewhere on the board
/SRAM Banks/B23: U806.16 (Q3); also elsewhere on the board
/SRAM Banks/B24: U806.15 (Q4); also elsewhere on the board
/SRAM Banks/B25: U806.14 (Q5); also elsewhere on the board
/SRAM Banks/B26: U806.13 (Q6); also elsewhere on the board
/SRAM Banks/B27: U806.12 (Q7); also elsewhere on the board
/SRAM Banks/PA14: R802.1, U803.19 (Q0), U804.19 (Q0), U805.19 (Q0), U807.2 (A0); also elsewhere on the board
/SRAM Banks/PA15: R803.1, U803.18 (Q1), U804.18 (Q1), U805.18 (Q1), U807.3 (A1); also elsewhere on the board
/SRAM Banks/PA16: R804.1, U803.17 (Q2), U804.17 (Q2), U805.17 (Q2), U807.4 (A2); also elsewhere on the board
/SRAM Banks/PA17: R805.1, U803.16 (Q3), U804.16 (Q3), U805.16 (Q3), U807.5 (A3); also elsewhere on the board
/SRAM Banks/PA18: R806.1, U803.15 (Q4), U804.15 (Q4), U805.15 (Q4), U807.6 (A4); also elsewhere on the board
/SRAM Banks/PA19: R807.1, U803.14 (Q5), U804.14 (Q5), U805.14 (Q5), U807.7 (A5); also elsewhere on the board
/SRAM Banks/PA20: R808.1, U803.13 (Q6), U804.13 (Q6), U805.13 (Q6), U807.8 (A6); also elsewhere on the board
/SRAM Banks/PA21: R809.1, U803.12 (Q7), U804.12 (Q7), U805.12 (Q7), U807.9 (A7); also elsewhere on the board
GND: C801.1, C802.2, C803.2, C804.1, C805.1, C806.1, C807.2, C808.1, C809.2, C810.2, R801.1, R802.2, R803.2, R804.2, R805.2, R806.2, R807.2, R808.2, R809.2, U109.7 (GND), U109.11, U801.1 (E), U801.8 (GND), U802.10 (GND), U803.10 (GND), U804.10 (GND), U805.10 (GND), U806.1 (OE), U806.10 (GND), U807.1 (G1), U807.10 (GND), U807.19 (G2); also elsewhere on the board
unnamed: J802.1, U807.18 (Y0)
unnamed: J802.2, U807.17 (Y1)
unnamed: J802.3, U807.16 (Y2)
unnamed: J802.4, U807.15 (Y3)
unnamed: J802.5, U807.14 (Y4)
unnamed: J802.6, U807.13 (Y5)
unnamed: J802.7, U807.12 (Y6)
unnamed: J802.8, U807.11 (Y7)
unnamed: JP801.1 (A), R801.2, U802.1 (OE)
unnamed: JP801.2 (B), U801.7 (O3)
unnamed: U801.4 (O0), U803.1 (OE)
unnamed: U801.5 (O1), U804.1 (OE)
unnamed: U801.6 (O2), U805.1 (OE)
unnamed: U109.1, U801.12 (O0)
unnamed: U109.3, U801.11 (O1)
unnamed: U109.5, U801.10 (O2)
unnamed: U109.9, U801.9 (O3)
unnamed: U109.8, U802.11 (Cp)
unnamed: U109.2, U803.11 (Cp)
unnamed: U109.4, U804.11 (Cp)
unnamed: U109.6, U805.11 (Cp)

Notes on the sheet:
Pull-downs to avoid Hi-Z — thus, high-mem is always bank 0
8-bit Data Bus
OPTIONAL ONLY REQUIRED FOR 5VCMOS SRAM (WHICH I DON'T PLAN ON HAVING)
Some extra output pins-- Let's use these for the LCD!
(all)

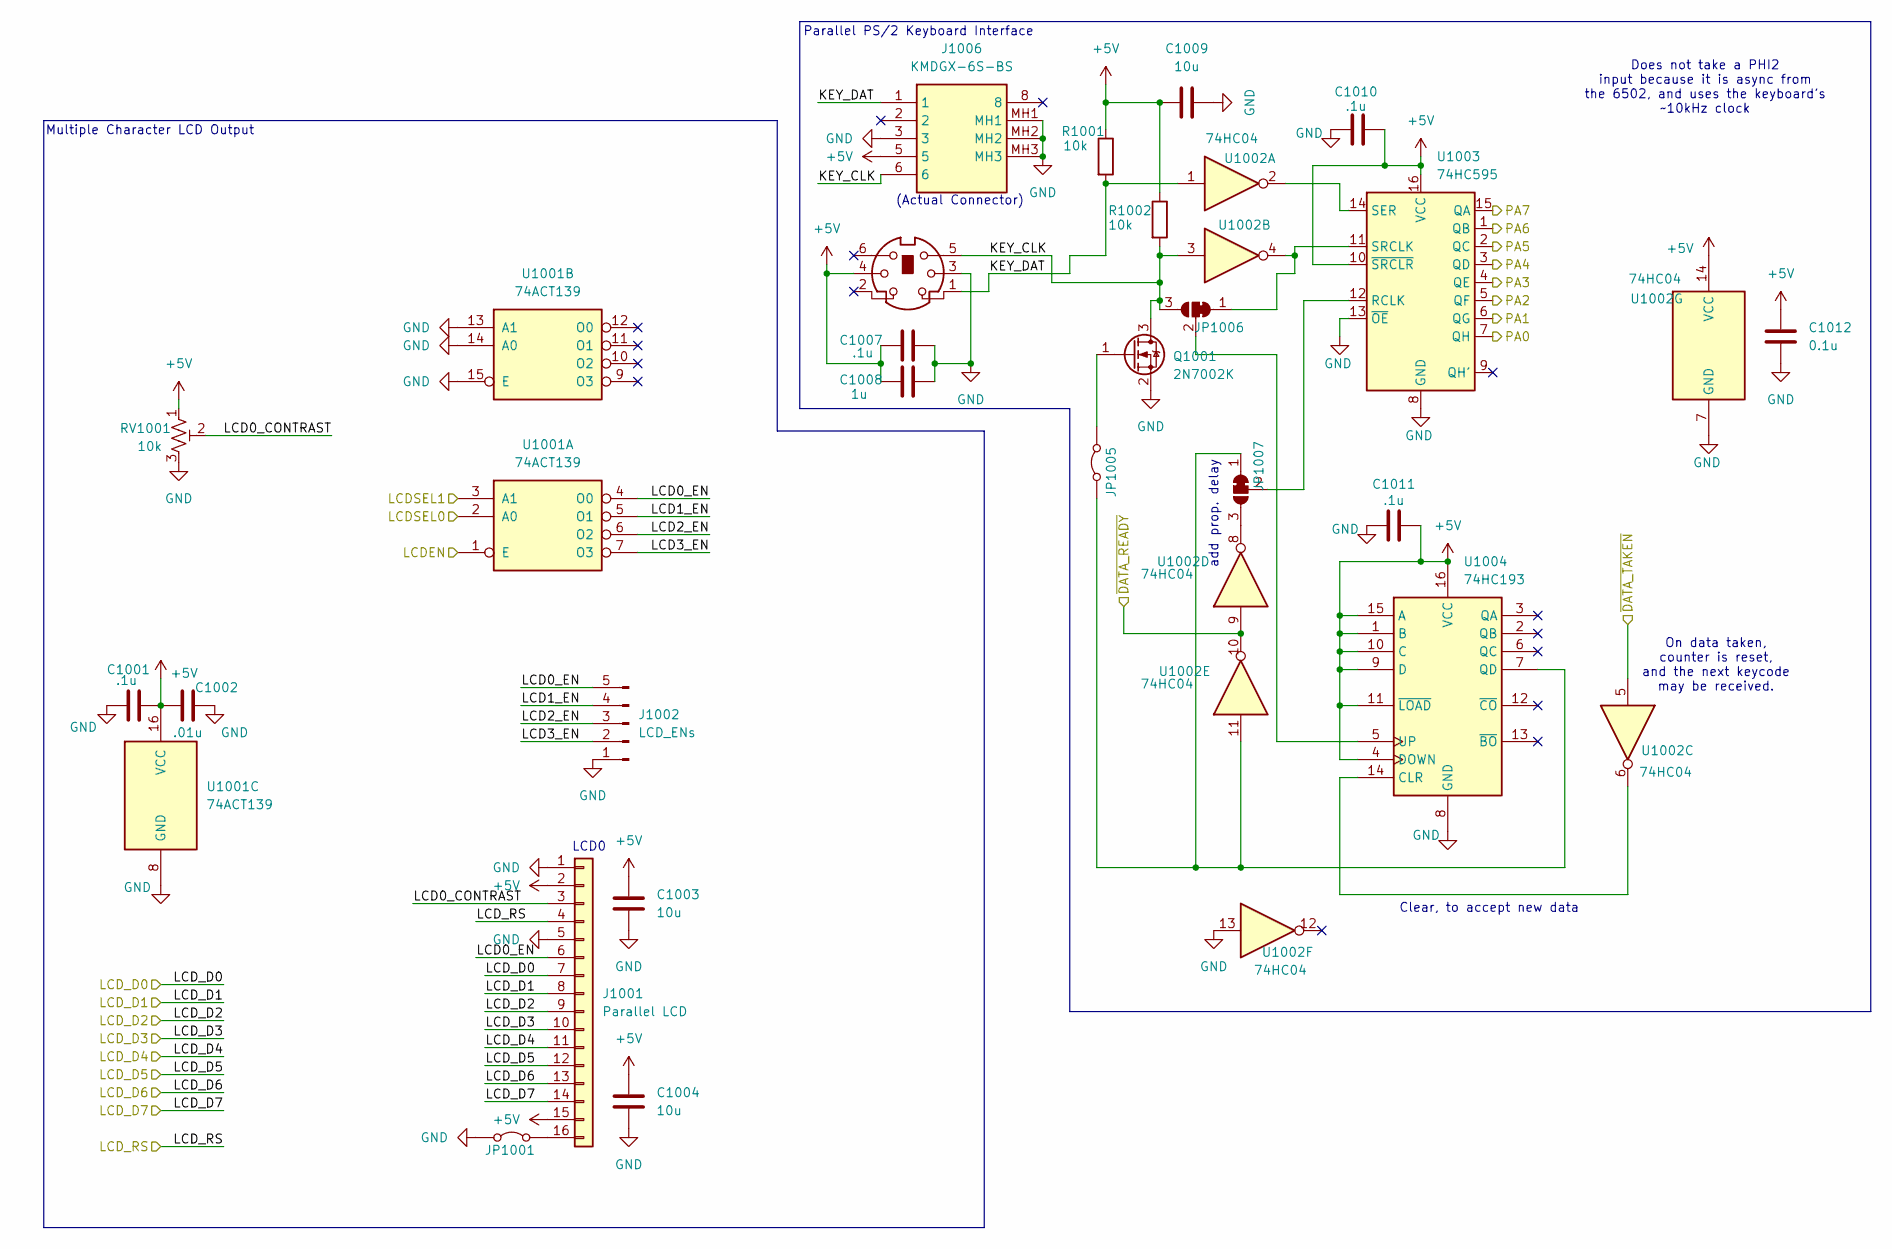
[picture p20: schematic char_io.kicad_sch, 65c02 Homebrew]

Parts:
C1001, C1007, C1010, C1011: .1u; C_0402_1005Metric
C1002: .01u; C_0402_1005Metric
C1003, C1004, C1009: 10u; C_0402_1005Metric
C1008: 1u; C_0402_1005Metric
C1012: 0.1u; C_0402_1005Metric
J1001: Parallel LCD; IDC-Header_2x08_P2.54mm_Vertical_SMD
J1002: LCD_ENs; PinHeader_1x05_P2.54mm_Vertical
J1005: KMDGX-6S-BS
J1006: KMDGX-6S-BS; KMDGX6SBS; Mouser Part Number 806-KMDGX-6S-BS
JP1001, JP1005: Jumper_2_Bridged; SolderJumper-2_P1.3mm_Bridged2Bar_Pad1.0x1.5mm
JP1006, JP1007: SolderJumper_3_Bridged12; SolderJumper-3_P1.3mm_Bridged12_Pad1.0x1.5mm
Q1001: 2N7002K; SOT-23
R1001, R1002: 10k; R_0402_1005Metric
RV1001: 10k; Potentiometer_Bourns_TC33X_Vertical
U1001: 74ACT139; TSSOP-16_4.4x5mm_P0.65mm
U1002: 74HC04; SOIC-14_3.9x8.7mm_P1.27mm
U1003: 74HC595; SOIC-16_3.9x9.9mm_P1.27mm
U1004: 74HC193; TSSOP-16_4.4x5mm_P0.65mm

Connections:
+5V: C1001.2, C1002.1, C1003.1, C1004.1, C1007.1, C1008.1, C1009.1, C1010.2, C1011.2, C1012.1, J1001.2, J1001.15, J1005.4, J1006.5, R1001.1, R1002.1, RV1001.1, U1001.16 (VCC), U1002.14 (VCC), U1003.10 (~SRCLR), U1003.16 (VCC), U1004.1 (B), U1004.4 (DOWN), U1004.9 (D), U1004.10 (C), U1004.11 (~LOAD), U1004.15 (A), U1004.16 (VCC); also elsewhere on the board
/Character IO/KEY_CLK: J1005.5, J1006.6, JP1006.3 (B), Q1001.3 (D), R1002.2, U1002.3
/Character IO/KEY_DAT: J1005.1, J1006.1, R1001.2, U1002.1
/Character IO/LCD0_CONTRAST: J1001.3, RV1001.2
/Character IO/LCD0_EN: J1001.6, J1002.5, U1001.4 (O0)
/Character IO/LCD1_EN: J1002.4, U1001.5 (O1)
/Character IO/LCD2_EN: J1002.3, U1001.6 (O2)
/Character IO/LCD3_EN: J1002.2, U1001.7 (O3)
/Character IO/LCDEN: U1001.1 (E); also elsewhere on the board
/Character IO/LCDSEL0: U1001.2 (A0); also elsewhere on the board
/Character IO/LCDSEL1: U1001.3 (A1); also elsewhere on the board
/Character IO/LCD_RS: J1001.4; also elsewhere on the board
/Character IO/PA0: U1003.7 (QH); also elsewhere on the board
/Character IO/PA1: U1003.6 (QG); also elsewhere on the board
/Character IO/PA2: U1003.5 (QF); also elsewhere on the board
/Character IO/PA3: U1003.4 (QE); also elsewhere on the board
/Character IO/PA4: U1003.3 (QD); also elsewhere on the board
/Character IO/PA5: U1003.2 (QC); also elsewhere on the board
/Character IO/PA6: U1003.1 (QB); also elsewhere on the board
/Character IO/PA7: U1003.15 (QA); also elsewhere on the board
/Character IO/~DATA_READY: U1002.9, U1002.10; also elsewhere on the board
/Character IO/~DATA_TAKEN: U1002.5; also elsewhere on the board
/PQ0: J1001.7; also elsewhere on the board
/PQ1: J1001.8; also elsewhere on the board
/PQ2: J1001.9; also elsewhere on the board
/PQ3: J1001.10; also elsewhere on the board
/PQ4: J1001.11; also elsewhere on the board
/PQ5: J1001.12; also elsewhere on the board
/PQ6: J1001.13; also elsewhere on the board
/PQ7: J1001.14; also elsewhere on the board
GND: C1001.1, C1002.2, C1003.2, C1004.2, C1007.2, C1008.2, C1009.2, C1010.1, C1011.1, C1012.2, J1001.1, J1001.5, J1002.1, J1005.3, J1006.3, J1006.MH1, J1006.MH2, J1006.MH3, JP1001.1 (A), Q1001.2 (S), RV1001.3, U1001.8 (GND), U1001.13 (A1), U1001.14 (A0), U1001.15 (E), U1002.7 (GND), U1002.13, U1003.8 (GND), U1003.13 (~OE), U1004.8 (GND); also elsewhere on the board
unnamed: J1001.16, JP1001.2 (B)
unnamed: JP1005.1 (A), JP1007.1 (A), U1002.11, U1004.7 (QD)
unnamed: JP1005.2 (B), Q1001.1 (G)
unnamed: JP1006.1 (A), U1002.4, U1003.11 (SRCLK)
unnamed: JP1006.2 (C), U1004.5 (UP)
unnamed: JP1007.3 (B), U1002.8
unnamed: JP1007.2 (C), U1003.12 (RCLK)
unnamed: U1002.2, U1003.14 (SER)
unnamed: U1002.6, U1004.14 (CLR)

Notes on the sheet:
On data taken, counter is reset, and the next keycode may be received.
(Actual Connector)
Clear, to accept new data
Multiple Character LCD Output
Parallel PS/2 Keyboard Interface
add prop. delay
LCD0
Does not take a PHI2 input because it is async from the 6502, and uses the keyboard's ~10kHz clock

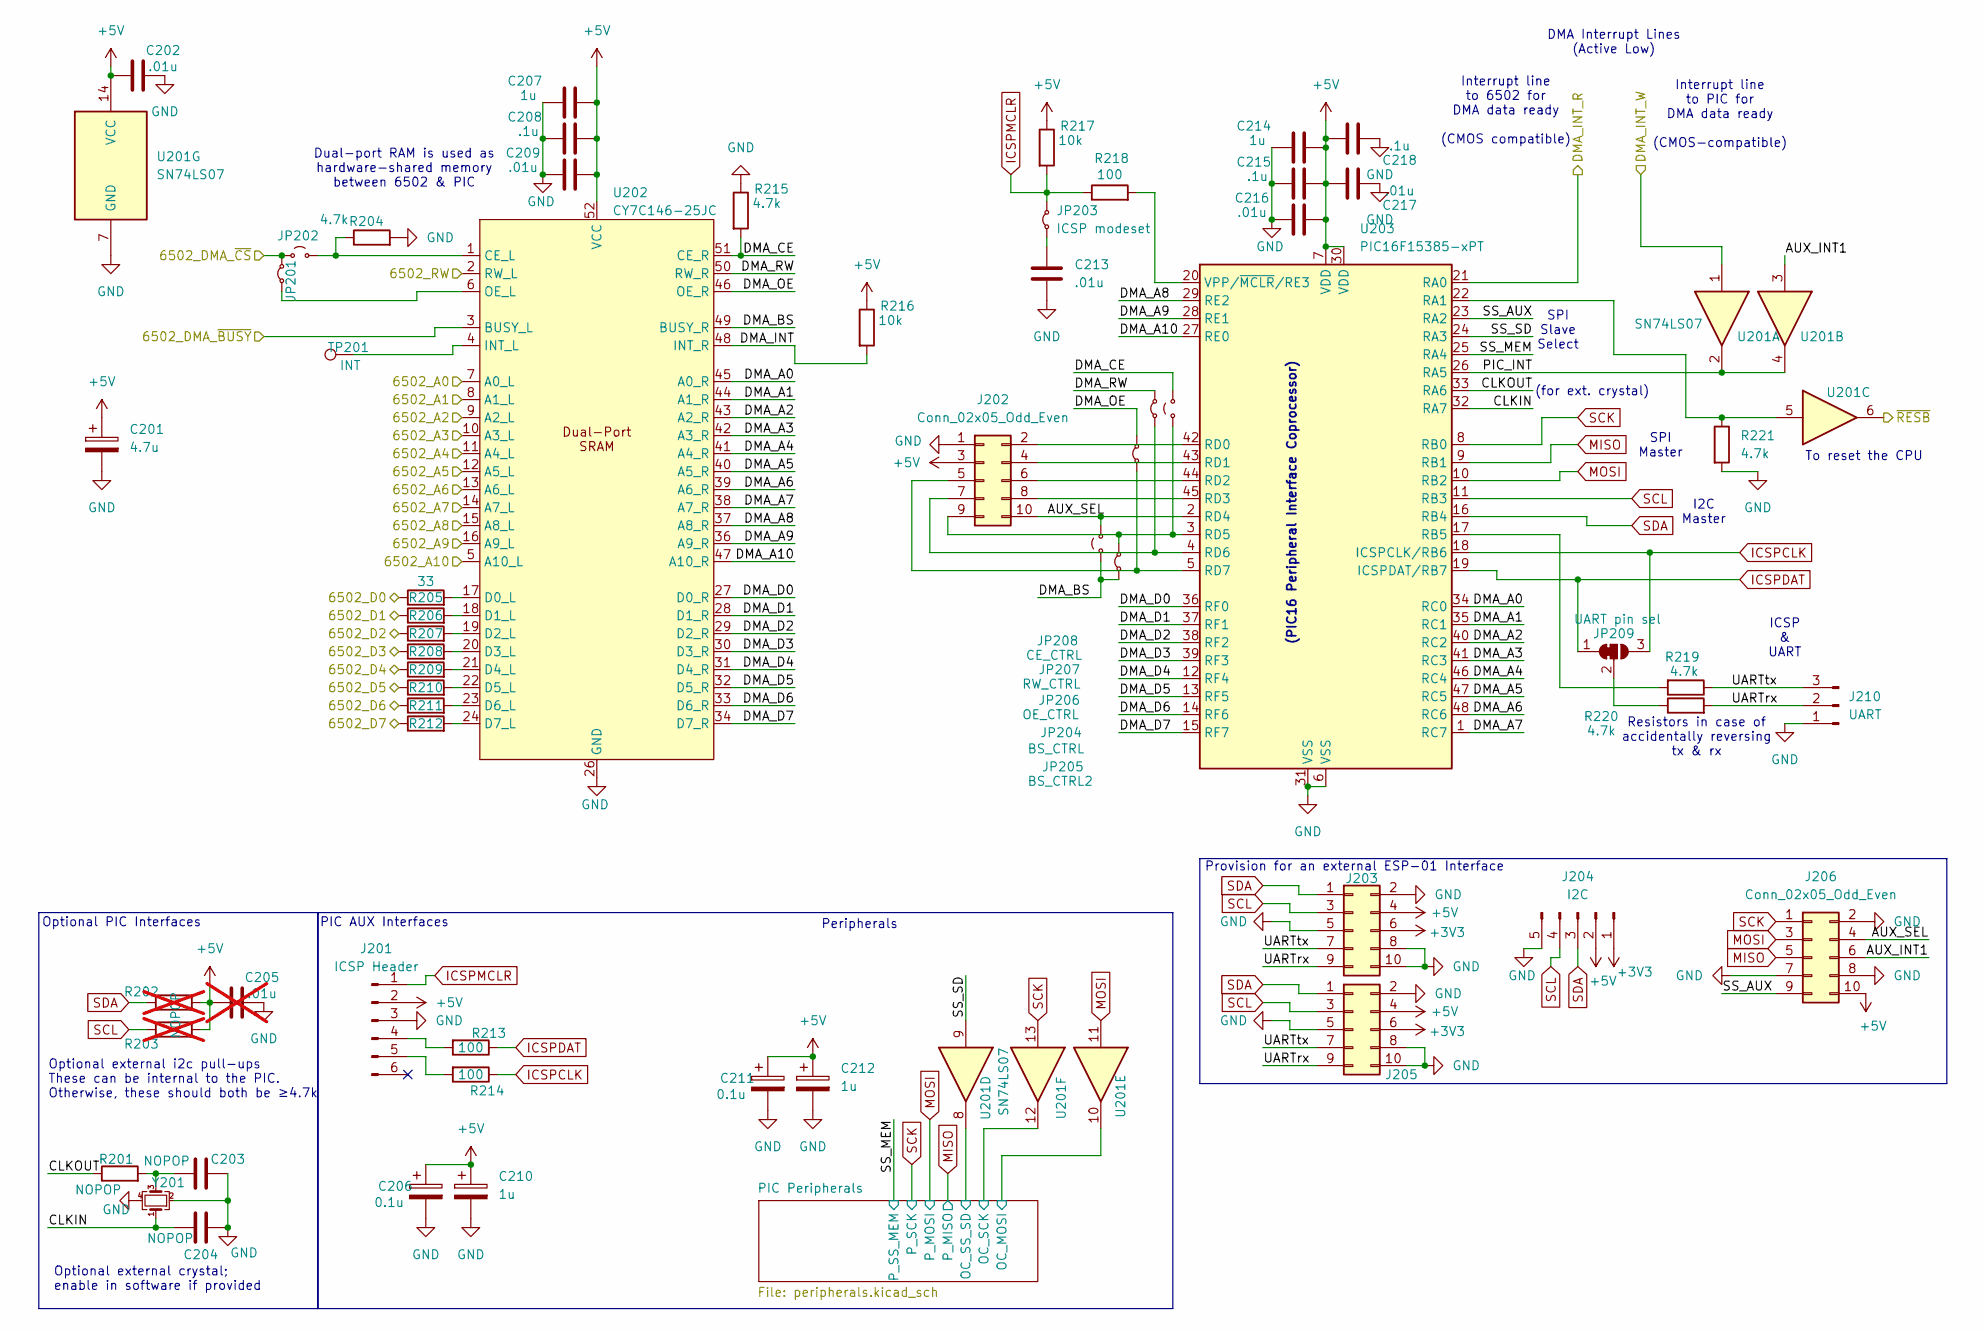
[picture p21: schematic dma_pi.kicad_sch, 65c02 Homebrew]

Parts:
C201: 4.7u; C_0402_1005Metric
C202, C209, C213, C216, C217: .01u; C_0402_1005Metric
C203, C204: NOPOP; C_0402_1005Metric
C205: .01u; C_0402_1005Metric; not fitted
C206, C211: 0.1u; C_0402_1005Metric
C207, C210, C212, C214: 1u; C_0402_1005Metric
C208, C215, C218: .1u; C_0402_1005Metric
J201: ICSP Header; PinHeader_1x06_P2.54mm_Vertical
J202, J203, J205, J206: Conn_02x05_Odd_Even; PinHeader_2x05_P2.54mm_Vertical_SMD
J204: I2C; PinHeader_1x05_P2.54mm_Vertical
J210: UART; FanPinHeader_1x03_P2.54mm_Vertical
JP201: Jumper_2_Small_Bridged; SolderJumper-2_P1.3mm_Bridged2Bar_Pad1.0x1.5mm
JP202: Jumper_2_Small_Open; SolderJumper-2_P1.3mm_Open_Pad1.0x1.5mm
JP203: ICSP modeset; SolderJumper-2_P1.3mm_Bridged2Bar_Pad1.0x1.5mm
JP204: BS_CTRL; SolderJumper-2_P1.3mm_Open_Pad1.0x1.5mm
JP205: BS_CTRL2; SolderJumper-2_P1.3mm_Bridged2Bar_Pad1.0x1.5mm
JP206: OE_CTRL; SolderJumper-2_P1.3mm_Bridged2Bar_Pad1.0x1.5mm
JP207: RW_CTRL; SolderJumper-2_P1.3mm_Bridged2Bar_Pad1.0x1.5mm
JP208: CE_CTRL; SolderJumper-2_P1.3mm_Open_Pad1.0x1.5mm
JP209: UART pin sel; SolderJumper-3_P1.3mm_Bridged12_Pad1.0x1.5mm
R201: NOPOP; R_0402_1005Metric
R202, R203: NOPOP; R_0402_1005Metric; not fitted
R204, R215, R219, R220, R221: 4.7k; R_0402_1005Metric
R205, R206, R207, R208, R209, R210, R211, R212: 33; R_0402_1005Metric
R213, R214, R218: 100; R_0402_1005Metric
R216, R217: 10k; R_0402_1005Metric
TP201: INT; TestPoint_Pad_D1.5mm
U201: SN74LS07; SOIC-14_3.9x8.7mm_P1.27mm
U202: CY7C146-25JC; 845221B1RKTP
U203: PIC16F15385-xPT; TQFP-48_7x7mm_P0.5mm
Y201: NOPOP; Crystal_SMD_2016-4Pin_2.0x1.6mm

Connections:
+3V3: J203.6, J204.1, J205.6; also elsewhere on the board
+5V: C201.1, C202.2, C205.2, C206.1, C207.1, C208.1, C209.1, C210.1, C211.1, C212.1, C214.1, C215.1, C216.1, C217.1, C218.1, J201.2, J202.3, J203.4, J204.2, J205.4, J206.10, R202.2, R203.2, R216.1, R217.1, U201.14 (VCC), U202.52 (VCC), U203.7 (VDD), U203.30 (VDD); also elsewhere on the board
/A0: U202.7 (A0_L); also elsewhere on the board
/A1: U202.8 (A1_L); also elsewhere on the board
/A2: U202.9 (A2_L); also elsewhere on the board
/A3: U202.10 (A3_L); also elsewhere on the board
/A4: U202.11 (A4_L); also elsewhere on the board
/A5: U202.12 (A5_L); also elsewhere on the board
/A6: U202.13 (A6_L); also elsewhere on the board
/A7: U202.14 (A7_L); also elsewhere on the board
/A8: U202.15 (A8_L); also elsewhere on the board
/A9: U202.16 (A9_L); also elsewhere on the board
/A10: U202.5 (A10_L); also elsewhere on the board
/DMA Peripheral Interface/6502_D0: R205.1; also elsewhere on the board
/DMA Peripheral Interface/6502_D1: R206.1; also elsewhere on the board
/DMA Peripheral Interface/6502_D2: R207.1; also elsewhere on the board
/DMA Peripheral Interface/6502_D3: R208.1; also elsewhere on the board
/DMA Peripheral Interface/6502_D4: R209.1; also elsewhere on the board
/DMA Peripheral Interface/6502_D5: R210.1; also elsewhere on the board
/DMA Peripheral Interface/6502_D6: R211.1; also elsewhere on the board
/DMA Peripheral Interface/6502_D7: R212.1; also elsewhere on the board
/DMA Peripheral Interface/DMA Peripheral Interface Module/AUX_INT1: J206.6, U201.3
/DMA Peripheral Interface/DMA Peripheral Interface Module/AUX_SEL: J202.10, J206.4, JP204.2 (B), U203.2 (RD4)
/DMA Peripheral Interface/DMA Peripheral Interface Module/CLKIN: C204.1, U203.32 (RA7), Y201.1
/DMA Peripheral Interface/DMA Peripheral Interface Module/CLKOUT: R201.1, U203.33 (RA6)
/DMA Peripheral Interface/DMA Peripheral Interface Module/DMA_A0: U202.45 (A0_R), U203.34 (RC0)
/DMA Peripheral Interface/DMA Peripheral Interface Module/DMA_A1: U202.44 (A1_R), U203.35 (RC1)
/DMA Peripheral Interface/DMA Peripheral Interface Module/DMA_A2: U202.43 (A2_R), U203.40 (RC2)
/DMA Peripheral Interface/DMA Peripheral Interface Module/DMA_A3: U202.42 (A3_R), U203.41 (RC3)
/DMA Peripheral Interface/DMA Peripheral Interface Module/DMA_A4: U202.41 (A4_R), U203.46 (RC4)
/DMA Peripheral Interface/DMA Peripheral Interface Module/DMA_A5: U202.40 (A5_R), U203.47 (RC5)
/DMA Peripheral Interface/DMA Peripheral Interface Module/DMA_A6: U202.39 (A6_R), U203.48 (RC6)
/DMA Peripheral Interface/DMA Peripheral Interface Module/DMA_A7: U202.38 (A7_R), U203.1 (RC7)
/DMA Peripheral Interface/DMA Peripheral Interface Module/DMA_A8: U202.37 (A8_R), U203.29 (RE2)
/DMA Peripheral Interface/DMA Peripheral Interface Module/DMA_A9: U202.36 (A9_R), U203.28 (RE1)
/DMA Peripheral Interface/DMA Peripheral Interface Module/DMA_A10: U202.47 (A10_R), U203.27 (RE0)
/DMA Peripheral Interface/DMA Peripheral Interface Module/DMA_BS: JP204.1 (A), JP205.1 (A), U202.49 (BUSY_R)
/DMA Peripheral Interface/DMA Peripheral Interface Module/DMA_CE: JP208.2 (B), R215.2, U202.51 (CE_R)
/DMA Peripheral Interface/DMA Peripheral Interface Module/DMA_D0: U202.27 (D0_R), U203.36 (RF0)
/DMA Peripheral Interface/DMA Peripheral Interface Module/DMA_D1: U202.28 (D1_R), U203.37 (RF1)
/DMA Peripheral Interface/DMA Peripheral Interface Module/DMA_D2: U202.29 (D2_R), U203.38 (RF2)
/DMA Peripheral Interface/DMA Peripheral Interface Module/DMA_D3: U202.30 (D3_R), U203.39 (RF3)
/DMA Peripheral Interface/DMA Peripheral Interface Module/DMA_D4: U202.31 (D4_R), U203.12 (RF4)
/DMA Peripheral Interface/DMA Peripheral Interface Module/DMA_D5: U202.32 (D5_R), U203.13 (RF5)
/DMA Peripheral Interface/DMA Peripheral Interface Module/DMA_D6: U202.33 (D6_R), U203.14 (RF6)
/DMA Peripheral Interface/DMA Peripheral Interface Module/DMA_D7: U202.34 (D7_R), U203.15 (RF7)
/DMA Peripheral Interface/DMA Peripheral Interface Module/DMA_INT: R216.2, U202.48 (INT_R)
/DMA Peripheral Interface/DMA Peripheral Interface Module/DMA_OE: JP206.2 (B), U202.46 (OE_R)
/DMA Peripheral Interface/DMA Peripheral Interface Module/DMA_RW: JP207.2 (B), U202.50 (RW_R)
/DMA Peripheral Interface/DMA Peripheral Interface Module/PIC Peripherals/OC_MO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: U201.10; also elsewhere on the board
/DMA Peripheral Interface/DMA Peripheral Interface Module/PIC Peripherals/OC_SCK: U201.12; also elsewhere on the board
/DMA Peripheral Interface/DMA Peripheral Interface Module/PIC Peripherals/OC_SS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: U201.8; also elsewhere on the board
/DMA Peripheral Interface/DMA Peripheral Interface Module/PIC_INT: U201.2, U201.4, U203.26 (RA5)
/DMA Peripheral Interface/DMA Peripheral Interface Module/SS_AUX: J206.9, U203.23 (RA2)
/DMA Peripheral Interface/DMA Peripheral Interface Module/SS_MEM: U203.25 (RA4); also elsewhere on the board
/DMA Peripheral Interface/DMA Peripheral Interface Module/SS_SD: U201.9, U203.24 (RA3)
/DMA Peripheral Interface/DMA Peripheral Interface Module/UARTrx: J203.9, J205.9, J210.2, R220.2
/DMA Peripheral Interface/DMA Peripheral Interface Module/UARTtx: J203.7, J205.7, J210.3, R219.1
/DMA Peripheral Interface/~BUSY: U202.3 (BUSY_L); also elsewhere on the board
/IO_CMD: U201.1; also elsewhere on the board
/R~W: U202.2 (RW_L); also elsewhere on the board
/~DMA_CS: JP201.2 (B), JP202.1 (A); also elsewhere on the board
/~IRQ: U203.21 (RA0); also elsewhere on the board
GND: C201.2, C202.1, C203.1, C204.2, C205.1, C206.2, C207.2, C208.2, C209.2, C210.2, C211.2, C212.2, C213.2, C214.2, C215.2, C216.2, C217.2, C218.2, J201.3, J202.1, J203.2, J203.5, J203.8, J203.10, J204.5, J205.2, J205.5, J205.8, J205.10, J206.2, J206.7, J206.8, J210.1, R204.2, R215.1, R221.2, U201.7 (GND), U202.26 (GND), U203.6 (VSS), U203.31 (VSS), Y201.2, Y201.4; also elsewhere on the board
ICSPCLK: JP209.3 (B), R214.1, U203.18 (ICSPCLK/RB6)
ICSPDAT: JP209.1 (A), R213.1, U203.19 (ICSPDAT/RB7)
ICSPMCLR: J201.1, JP203.2 (B), R217.2, R218.1
MISO: J206.5, U203.9 (RB1); also elsewhere on the board
MOSI: J206.3, U201.11, U203.10 (RB2); also elsewhere on the board
unnamed: C203.2, R201.2, Y201.3
unnamed: J201.4, R213.2
unnamed: J201.5, R214.2
unnamed: J202.2, U203.42 (RD0)
unnamed: J202.4, U203.43 (RD1)
unnamed: J202.5, JP206.1 (A), U203.5 (RD7)
unnamed: J202.6, U203.44 (RD2)
unnamed: J202.7, JP207.1 (A), U203.4 (RD6)
unnamed: J202.8, U203.45 (RD3)
unnamed: J202.9, JP205.2 (B), JP208.1 (A), U203.3 (RD5)
unnamed: JP201.1 (A), U202.6 (OE_L)
unnamed: JP202.2 (B), R204.1, U202.1 (CE_L)
unnamed: C213.1, JP203.1 (A)
unnamed: JP209.2 (C), R220.1
unnamed: R205.2, U202.17 (D0_L)
unnamed: R206.2, U202.18 (D1_L)
unnamed: R207.2, U202.19 (D2_L)
unnamed: R208.2, U202.20 (D3_L)
unnamed: R209.2, U202.21 (D4_L)
unnamed: R210.2, U202.22 (D5_L)
unnamed: R211.2, U202.23 (D6_L)
unnamed: R212.2, U202.24 (D7_L)
unnamed: TP201.1, U202.4 (INT_L)
unnamed: R221.1, U201.5, U203.22 (RA1)
unnamed: R219.2, U203.17 (RB5)
unnamed: R218.2, U203.20 (VPP/~MCLR/RE3)
RESB: U201.6; also elsewhere on the board
SCK: J206.1, U201.13, U203.8 (RB0); also elsewhere on the board
SCL: J203.3, J204.4, J205.3, R203.1, U203.11 (RB3)
SDA: J203.1, J204.3, J205.1, R202.1, U203.16 (RB4)

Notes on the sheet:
Peripherals
PIC AUX Interfaces
SPI Slave Select
Interrupt line to 6502 for DMA data ready (CMOS compatible)
DMA Interrupt Lines (Active Low)
(for ext. crystal)
(PIC16 Peripheral Interface Coprocessor)
Optional external i2c pull-ups These can be internal to the PIC. Otherwise, these should both be ≥4.7k
Optional PIC Interfaces
Provision for an external ESP-01 Interface
Optional external crystal; enable in software if provided
Interrupt line to PIC for DMA data ready (CMOS-compatible)
Dual-port RAM is used as hardware-shared memory between 6502 & PIC
ICSP & UART
SPI Master
To reset the CPU
I2C Master
Resistors in case of accidentally reversing tx & rx

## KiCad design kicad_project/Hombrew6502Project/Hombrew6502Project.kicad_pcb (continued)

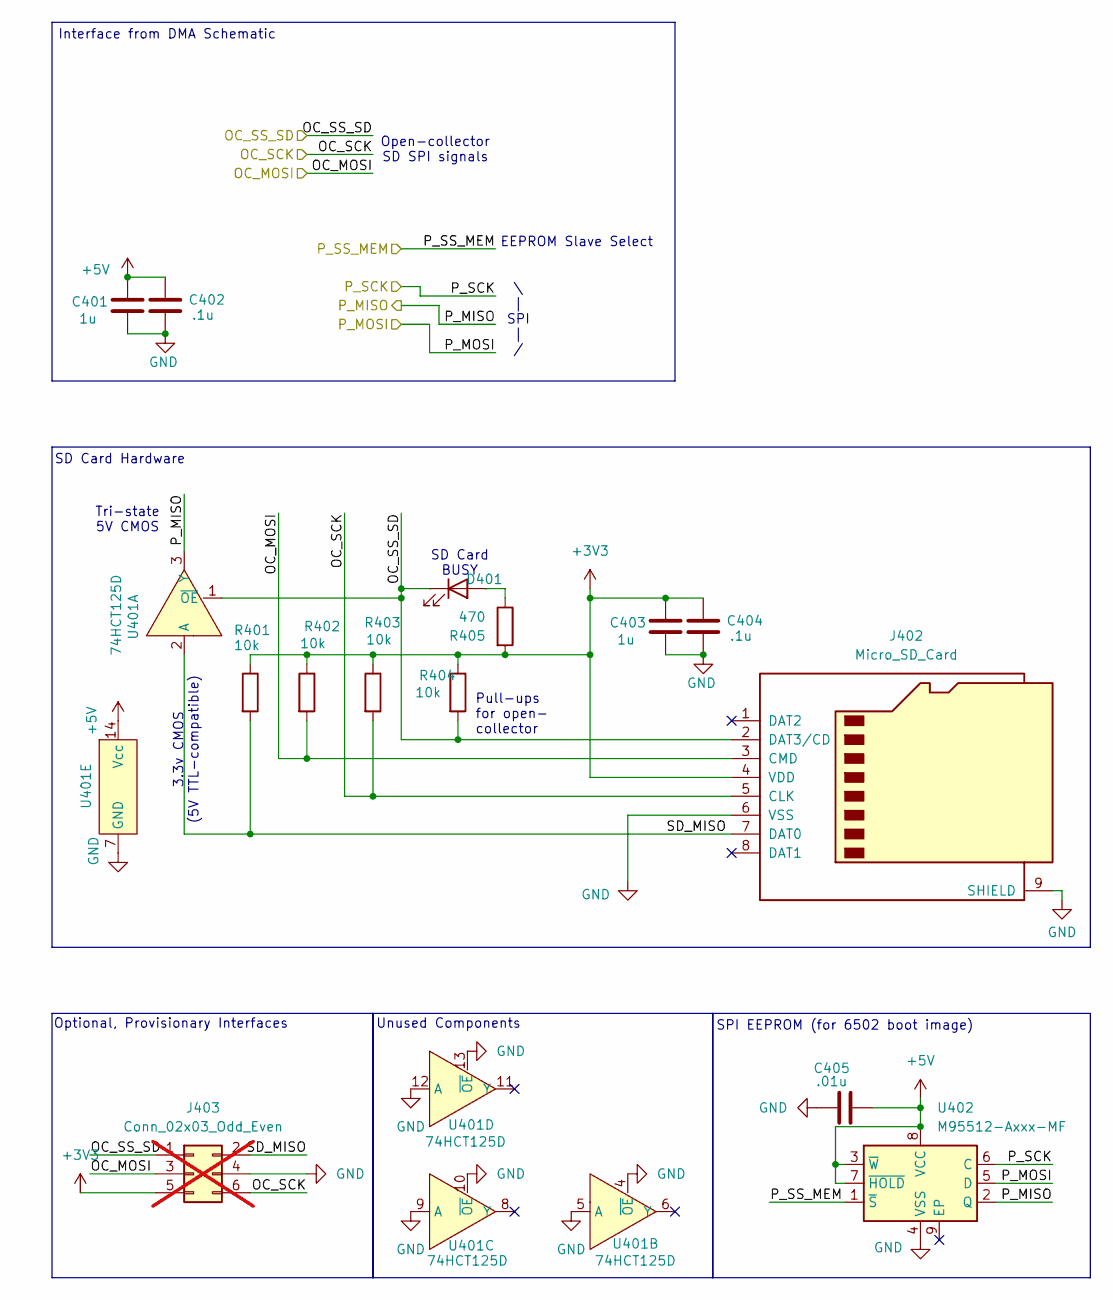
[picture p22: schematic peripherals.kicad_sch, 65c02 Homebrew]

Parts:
C401, C403: 1u; C_0402_1005Metric
C402, C404: .1u; C_0402_1005Metric
C405: .01u; C_0402_1005Metric
D401: LED; LED_0402_1005Metric
J402: Micro_SD_Card; microSD_HC_Wuerth_693072010801
J403: Conn_02x03_Odd_Even; PinHeader_2x03_P2.54mm_Vertical_SMD; not fitted
R401, R402, R403, R404: 10k; R_0402_1005Metric
R405: 470; R_0402_1005Metric
U401: 74HCT125D; SOIC-14_3.9x8.7mm_P1.27mm
U402: M95512-Axxx-MF; TSSOP-8_4.4x3mm_P0.65mm

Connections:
+3V3: C403.1, C404.1, J402.4 (VDD), J403.5, R401.1, R402.1, R403.1, R404.1, R405.2; also elsewhere on the board
+5V: C401.1, C402.1, C405.1, U401.14 (Vcc), U402.3 (~W), U402.7 (~HOLD), U402.8 (VCC); also elsewhere on the board
/DMA Peripheral Interface/DMA Peripheral Interface Module/PIC Peripherals/OC_MO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: J402.3 (CMD), J403.3, R402.2; also elsewhere on the board
/DMA Peripheral Interface/DMA Peripheral Interface Module/PIC Peripherals/OC_SCK: J402.5 (CLK), J403.6, R403.2; also elsewhere on the board
/DMA Peripheral Interface/DMA Peripheral Interface Module/PIC Peripherals/OC_SS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: D401.1 (K), J402.2 (DAT3/CD), J403.1, R404.2, U401.1 (~OE); also elsewhere on the board
/DMA Peripheral Interface/DMA Peripheral Interface Module/PIC Peripherals/SD_MI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: J402.7 (DAT0), J403.2, R401.2, U401.2 (A)
/DMA Peripheral Interface/DMA Peripheral Interface Module/SS_MEM: U402.1 (~S); also elsewhere on the board
GND: C401.2, C402.2, C403.2, C404.2, C405.2, J402.6 (VSS), J402.9 (SHIELD), J403.4, U401.4 (~OE), U401.5 (A), U401.7 (GND), U401.9 (A), U401.10 (~OE), U401.12 (A), U401.13 (~OE), U402.4 (VSS); also elsewhere on the board
MISO: U401.3 (Y), U402.2 (Q); also elsewhere on the board
MOSI: U402.5 (D); also elsewhere on the board
unnamed: D401.2 (A), R405.1
SCK: U402.6 (C); also elsewhere on the board

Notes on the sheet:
3.3v CMOS (5V TTL-compatible)
Interface from DMA Schematic
Unused Components
EEPROM Slave Select
SD Card Hardware
\ | SPI | /
Pull-ups for open- collector
SPI EEPROM (for 6502 boot image)
Tri-state 5V CMOS
Optional, Provisionary Interfaces
Open-collector SD SPI signals
SD Card BUSY

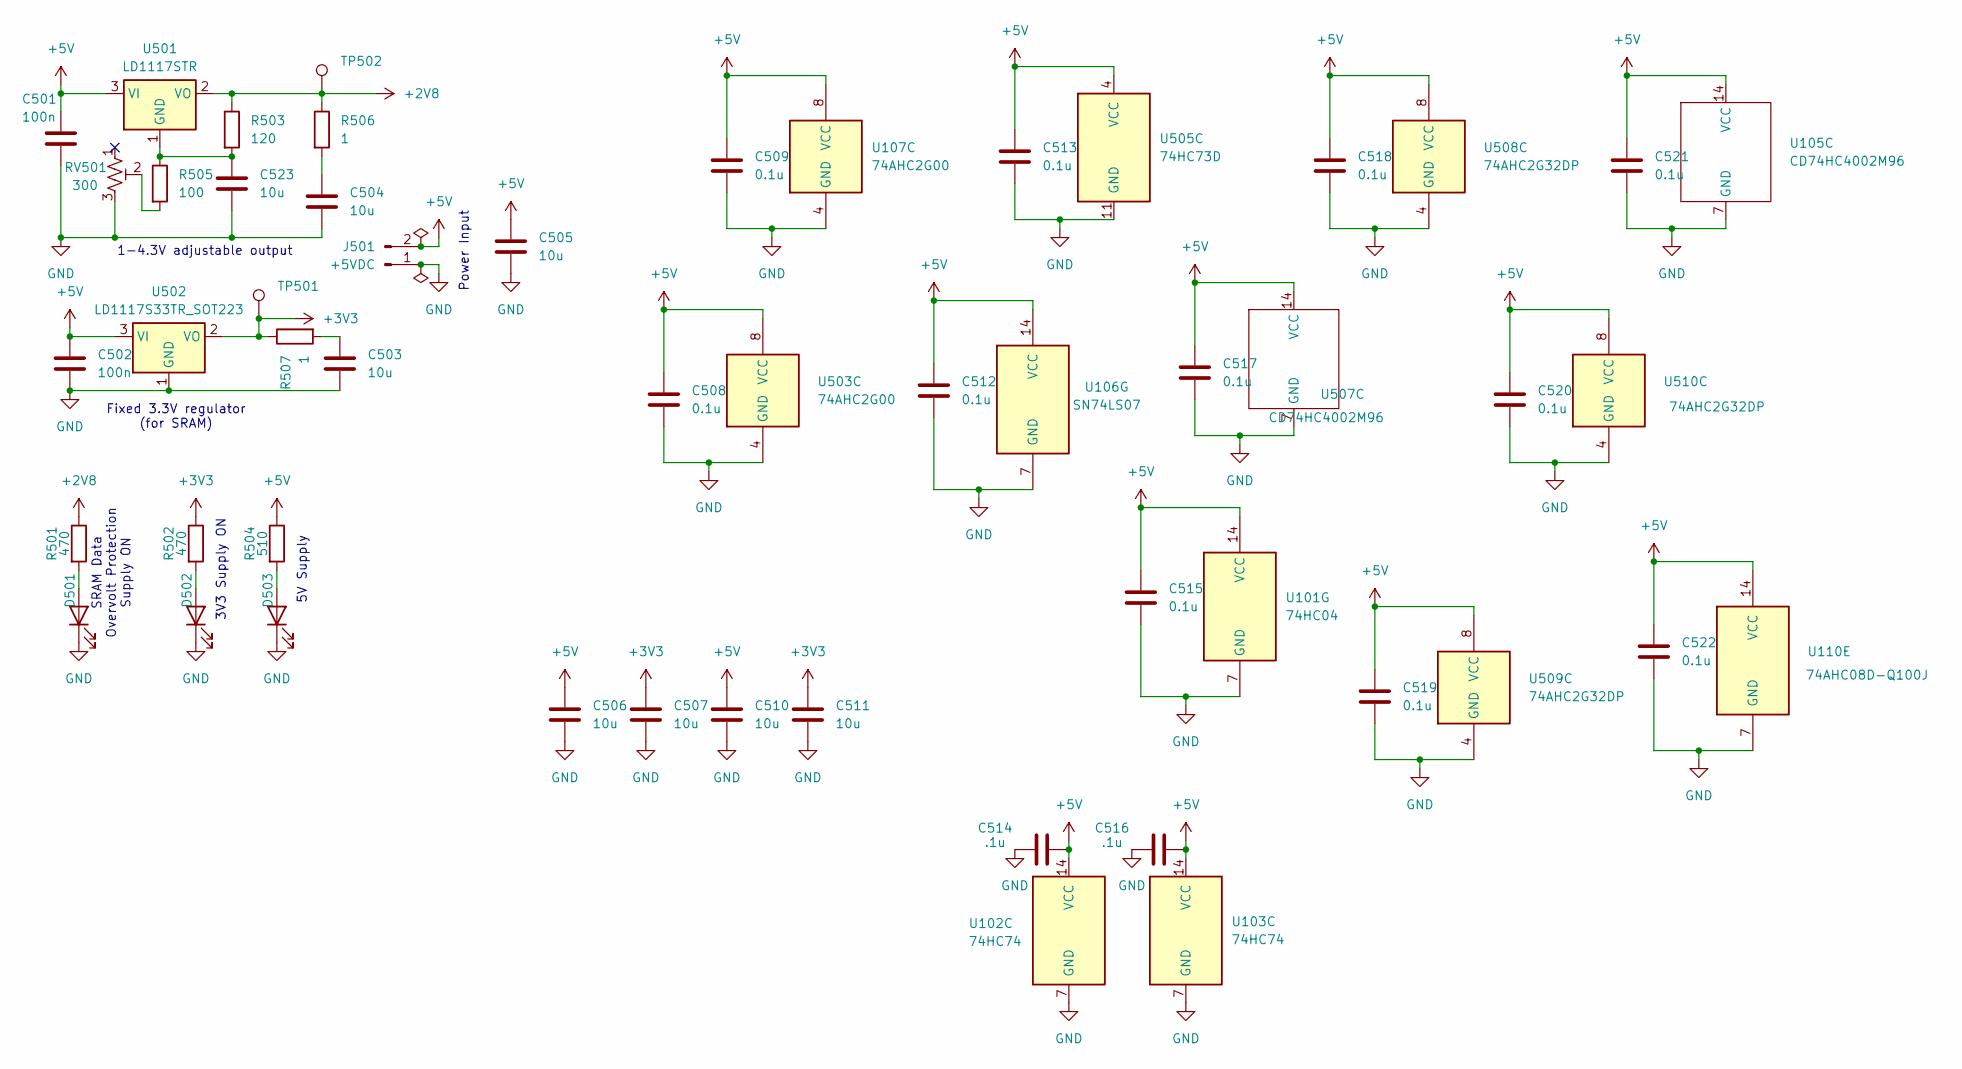
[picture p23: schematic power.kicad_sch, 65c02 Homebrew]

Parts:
C501, C502: 100n; C_0402_1005Metric
C503, C504, C505, C506, C507, C510, C511, C523: 10u; C_0402_1005Metric
C508, C509, C512, C513, C515, C517, C518, C519, C520, C521, C522: 0.1u; C_0402_1005Metric
C514, C516: .1u; C_0402_1005Metric
D501, D502, D503: LED; LED_0402_1005Metric
J501: +5VDC; PinHeader_1x02_P2.54mm_Vertical
R501, R502: 470; R_0402_1005Metric
R503: 120; R_0402_1005Metric
R504: 510; R_0402_1005Metric
R505: 100; R_0402_1005Metric
R506, R507: 1; R_0402_1005Metric
RV501: 300; Potentiometer_Bourns_TC33X_Vertical
TP501, TP502: TestPoint; TestPoint_Pad_D2.5mm
U101: 74HC04; SOIC-14_3.9x8.7mm_P1.27mm
U102, U103: 74HC74; SOIC-14_3.9x8.7mm_P1.27mm
U105, U507: CD74HC4002M96; SOIC-14_3.9x8.7mm_P1.27mm
U106: SN74LS07; SOIC-14_3.9x8.7mm_P1.27mm
U107, U503: 74AHC2G00; TSSOP-8_3x3mm_P0.65mm
U110: 74AHC08D-Q100J; SOIC-14_3.9x8.7mm_P1.27mm
U501: LD1117STR; SOT-223-3_TabPin2
U502: LD1117S33TR_SOT223; SOT-223-3_TabPin2
U505: 74HC73D; SOIC-14_3.9x8.7mm_P1.27mm
U508, U509, U510: 74AHC2G32DP; TSSOP-8_3x3mm_P0.65mm

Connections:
+2V8: R501.1, R503.1, R506.1, TP502.1, U501.2 (VO); also elsewhere on the board
+3V3: C507.1, C511.1, R502.1, R507.1, TP501.1, U502.2 (VO); also elsewhere on the board
+5V: C501.1, C502.1, C505.1, C506.1, C508.1, C509.1, C510.1, C512.1, C513.1, C514.1, C515.1, C516.1, C517.1, C518.1, C519.1, C520.1, C521.1, C522.1, J501.2, R504.1, U101.14 (VCC), U102.14 (VCC), U103.14 (VCC), U105.14 (VCC), U106.14 (VCC), U107.8 (VCC), U110.14 (VCC), U501.3 (VI), U502.3 (VI), U503.8 (VCC), U505.4 (VCC), U507.14 (VCC), U508.8 (VCC), U509.8 (VCC), U510.8 (VCC); also elsewhere on the board
GND: C501.2, C502.2, C503.2, C504.2, C505.2, C506.2, C507.2, C508.2, C509.2, C510.2, C511.2, C512.2, C513.2, C514.2, C515.2, C516.2, C517.2, C518.2, C519.2, C520.2, C521.2, C522.2, C523.2, D501.1 (K), D502.1 (K), D503.1 (K), J501.1, RV501.3, U101.7 (GND), U102.7 (GND), U103.7 (GND), U105.7 (GND), U106.7 (GND), U107.4 (GND), U110.7 (GND), U502.1 (GND), U503.4 (GND), U505.11 (GND), U507.7 (GND), U508.4 (GND), U509.4 (GND), U510.4 (GND); also elsewhere on the board
unnamed: C503.1, R507.2
unnamed: C504.1, R506.2
unnamed: D501.2 (A), R501.2
unnamed: D502.2 (A), R502.2
unnamed: D503.2 (A), R504.2
unnamed: R505.2, RV501.2
unnamed: C523.1, R503.2, R505.1, U501.1 (GND)

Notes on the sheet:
Fixed 3.3V regulator (for SRAM)
1-4.3V adjustable output
SRAM Data Overvolt Protection Supply ON
Power Input
5V Supply
3V3 Supply ON

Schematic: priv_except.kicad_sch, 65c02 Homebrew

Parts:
D901: LED; LED_0402_1005Metric
JP901: Jumper_2_Small_Bridged; SolderJumper-2_P1.3mm_Bridged2Bar_Pad1.0x1.5mm
R901: 470; R_0402_1005Metric
U106: SN74LS07; SOIC-14_3.9x8.7mm_P1.27mm
U110, U706: 74AHC08D-Q100J; SOIC-14_3.9x8.7mm_P1.27mm
U503: 74AHC2G00; TSSOP-8_3x3mm_P0.65mm
U505: 74HC73D; SOIC-14_3.9x8.7mm_P1.27mm
U507: CD74HC4002M96; SOIC-14_3.9x8.7mm_P1.27mm
U510: 74AHC2G32DP; TSSOP-8_3x3mm_P0.65mm

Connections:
+3V3: R901.1; also elsewhere on the board
+5V: U505.2 (~R), U505.6 (~R); also elsewhere on the board
/D0: U706.9; also elsewhere on the board
/D1: U706.10; also elsewhere on the board
/D2: U507.10; also elsewhere on the board
/D3: U706.4; also elsewhere on the board
/D4: U706.5; also elsewhere on the board
/D5: U507.11; also elsewhere on the board
/D6: U706.1; also elsewhere on the board
/D7: U706.2; also elsewhere on the board
/FAULTCLK: U505.1 (C), U505.5 (C); also elsewhere on the board
/HIMEM: U110.4; also elsewhere on the board
/Privileges & Exception Handling/FAULT: U505.14 (J), U510.3
/Privileges & Exception Handling/RESPRIV: U505.10 (K), U510.7
/SYNC: U110.10; also elsewhere on the board
/XLEVEL_KERNEL: U106.5, U505.8 (~Q), U507.12
/XLEVEL_USER: U110.5, U505.9 (Q)
/~HIMEM: U110.2; also elsewhere on the board
/~UMINH: U110.1; also elsewhere on the board
/~VPB: U505.3 (K), U510.1; also elsewhere on the board
unnamed: D901.2 (A), R901.2
unnamed: D901.1 (K), U106.6
unnamed: JP901.1 (A), U510.5
unnamed: JP901.2 (B), U507.13
unnamed: U110.6, U510.6
unnamed: U110.8, U503.6
unnamed: U110.9, U706.3
unnamed: U503.3, U507.9
unnamed: U503.5, U706.11
unnamed: U110.3, U505.7 (J)
unnamed: U106.13, U505.13 (~Q)
unnamed: U706.8, U706.12
unnamed: U706.6, U706.13
RESB: U106.12, U510.2; also elsewhere on the board

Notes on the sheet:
User Mode Inhibit
Kernel Level
Fault if trying to access kernel-only memory in any way
User / Kernel Execution Mode Handling
(Don't fault if kernel)
Fault if all low
Reset on fault
(Okay to not preserve registers; Going to terminate the process)
Fault on STP instruction in user mode
STP instuction is 0xDB
Excecution Privilege Level
Fault Handling Logic

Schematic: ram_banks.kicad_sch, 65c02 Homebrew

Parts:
C301, C304: 10u; C_0402_1005Metric
C302, C309, C316, C321: 1u; C_0402_1005Metric
C303, C305, C306, C307, C310, C312, C314, C317, C322, C324, C326, C328: .01u; C_0402_1005Metric
C308, C311, C313, C315, C318, C319, C320, C323, C325, C327, C329: .1u; C_0402_1005Metric
D301, D305: LED; LED_0402_1005Metric
D302, D303, D304, D306, D307, D308, D309: BAT54CDW; SOT-363_SC-70-6
J301, J302: Conn_02x16_Odd_Even; PinHeader_2x16_P2.54mm_Vertical
J303, J304: Conn_02x16_Odd_Even; PinHeader_2x16_P2.54mm_Vertical_SMD
J305: Conn_02x08_Counter_Clockwise; PinHeader_2x08_P2.54mm_Vertical_SMD
JP301: Jumper_2_Small_Open; SolderJumper-2_P1.3mm_Open_Pad1.0x1.5mm
R301, R302, R303, R304, R305, R306, R307, R308: 0; R_0402_1005Metric
R309, R310, R311, R312, R313, R314, R315, R316: 33; R_0402_1005Metric
R317, R343: 470; R_0402_1005Metric
R318, R319, R320, R321, R322, R323, R324, R325, R327, R328, R329, R330, R331, R332, R333, R334, R335, R336, R337, R338, R339, R340, R341, R342, R344, R345, R346, R347, R348, R349, R350, R351: 100; R_0402_1005Metric
R326: 10K; R_0402_1005Metric
R352, R353, R354, R355, R356, R357, R358, R359: 10k; R_0402_1005Metric
U301: TXS0108EPW; TSSOP-20_4.4x6.5mm_P0.65mm
U302, U306, U308, U310: TSOP-II-44_10.16x18.41mm_P0.8mm
U303: 74FCT521ATSOG8; SOIC-20W_7.5x12.8mm_P1.27mm
U304, U309: 74ACT139; TSSOP-16_4.4x5mm_P0.65mm
U305, U307, U311: 74LVC244APW; TSSOP-20_4.4x6.5mm_P0.65mm

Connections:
+2V8: C319.1, C320.1, C327.1, C329.1, D302.3 (K2), D302.6 (K2), D303.3 (K2), D303.6 (K2), D304.3 (K2), D304.6 (K2), D306.3 (K2), D306.6 (K2), D307.3 (K2), D307.6 (K2), D308.3 (K2), D308.6 (K2), D309.3 (K2), D309.6 (K2), J301.1, J303.1, R317.1, R343.1; also elsewhere on the board
+3V3: C304.1, C306.1, C307.1, C308.1, C310.1, C311.1, C312.1, C313.1, C314.1, C315.1, C317.1, C318.1, C322.1, C323.1, C324.1, C325.1, C326.1, C328.1, J301.5, J301.7, J303.5, J303.7, U301.2 (VCCA), U302.11 (VCC), U302.33 (VCC), U304.16 (VCC), U305.20 (VCC), U306.11 (VCC), U306.33 (VCC), U307.20 (VCC), U308.11 (VCC), U308.33 (VCC), U309.16 (VCC), U310.11 (VCC), U310.33 (VCC), U311.20 (VCC); also elsewhere on the board
+5V: C301.1, C302.1, C303.1, C305.1, C309.1, C316.1, C321.1, J301.3, J303.3, R352.1, R353.1, R354.1, R355.1, R356.1, R357.1, R358.1, R359.1, U301.19 (VCCB), U303.20 (Vcc); also elsewhere on the board
/A0: J302.31, J304.31, U305.11 (2A3); also elsewhere on the board
/A1: J302.29, J304.29, U305.13 (2A2); also elsewhere on the board
/A2: J302.27, J304.27, U305.15 (2A1); also elsewhere on the board
/A3: J302.25, J304.25, U305.17 (2A0); also elsewhere on the board
/A4: J302.23, J304.23, U305.8 (1A3); also elsewhere on the board
/A5: J302.21, J304.21, U305.6 (1A2); also elsewhere on the board
/A6: J302.19, J304.19, U305.4 (1A1); also elsewhere on the board
/A7: J302.17, J304.17, U305.2 (1A0); also elsewhere on the board
/A8: J302.13, J304.13, U311.11 (2A3); also elsewhere on the board
/A9: J302.11, J304.11, U311.13 (2A2); also elsewhere on the board
/A10: J302.9, J304.9, U311.15 (2A1); also elsewhere on the board
/A11: J302.7, J304.7, U311.17 (2A0); also elsewhere on the board
/A12: J302.5, J304.5, U311.8 (1A3); also elsewhere on the board
/A13: J302.3, J304.3, U311.6 (1A2); also elsewhere on the board
/HIMEM: J301.29; also elsewhere on the board
/RAMCLK: J302.28; also elsewhere on the board
/RDY: J301.28; also elsewhere on the board
/R~W: J301.30, J303.30, U307.2 (1A0); also elsewhere on the board
/SRAM Banks/3vPHI2: R337.2, U309.13 (A1)
/SRAM Banks/A0: U302.39 (~BLE), U304.11 (O1), U306.39 (~BLE), U308.39 (~BLE), U310.39 (~BLE)
/SRAM Banks/A0_PREDEC: D302.2 (A02), R334.2, U304.14 (A0)
/SRAM Banks/A1: D302.1 (A01), R333.2, U302.1 (A0), U306.1 (A0), U308.1 (A0), U310.1 (A0)
/SRAM Banks/A2: D302.4 (A02), R332.2, U302.2 (A1), U306.2 (A1), U308.2 (A1), U310.2 (A1)
/SRAM Banks/A3: D302.5 (A12), R331.2, U302.3 (A2), U306.3 (A2), U308.3 (A2), U310.3 (A2)
/SRAM Banks/A4: D303.2 (A02), R330.2, U302.4 (A3), U306.4 (A3), U308.4 (A3), U310.4 (A3)
/SRAM Banks/A5: D303.1 (A01), R329.2, U302.5 (A4), U306.5 (A4), U308.5 (A4), U310.5 (A4)
/SRAM Banks/A6: D303.4 (A02), R328.2, U302.18 (A5), U306.18 (A5), U308.18 (A5), U310.18 (A5)
/SRAM Banks/A7: D303.5 (A12), R327.2, U302.19 (A6), U306.19 (A6), U308.19 (A6), U310.19 (A6)
/SRAM Banks/A8: D308.2 (A02), R351.2, U302.20 (A7), U306.20 (A7), U308.20 (A7), U310.20 (A7)
/SRAM Banks/A9: D308.1 (A01), R350.2, U302.21 (A8), U306.21 (A8), U308.21 (A8), U310.21 (A8)
/SRAM Banks/A10: D308.4 (A02), R349.2, U302.22 (A9), U306.22 (A9), U308.22 (A9), U310.22 (A9)
/SRAM Banks/A11: D308.5 (A12), R348.2, U302.23 (A10), U306.23 (A10), U308.23 (A10), U310.23 (A10)
/SRAM Banks/A12: D309.2 (A02), R347.2, U302.24 (A11), U306.24 (A11), U308.24 (A11), U310.24 (A11)
/SRAM Banks/A13: D309.1 (A01), R346.2, U302.25 (A12), U306.25 (A12), U308.25 (A12), U310.25 (A12)
/SRAM Banks/A14: D309.4 (A02), R345.2, U302.26 (A13), U306.26 (A13), U308.26 (A13), U310.26 (A13)
/SRAM Banks/A15: D309.5 (A12), R344.2, U302.27 (A14), U306.27 (A14), U308.27 (A14), U310.27 (A14)
/SRAM Banks/A16: D304.2 (A02), R342.2, U302.42 (A15), U306.42 (A15), U308.42 (A15), U310.42 (A15)
/SRAM Banks/A17: D304.1 (A01), R341.2, U302.43 (A16), U306.43 (A16), U308.43 (A16), U310.43 (A16)
/SRAM Banks/A18: D304.4 (A02), R340.2, U302.44 (A17), U306.44 (A17), U308.44 (A17), U310.44 (A17)
/SRAM Banks/A19: R339.2, U304.2 (A0), U309.2 (A0)
/SRAM Banks/A20: R338.2, U304.3 (A1), U309.3 (A1)
/SRAM Banks/B20: J302.18, J304.18, U303.3 (B0); also elsewhere on the board
/SRAM Banks/B21: J302.16, J304.16, U303.5 (B1); also elsewhere on the board
/SRAM Banks/B22: J302.14, J304.14, U303.7 (B2); also elsewhere on the board
/SRAM Banks/B23: J302.12, J304.12, U303.9 (B3); also elsewhere on the board
/SRAM Banks/B24: J302.10, J304.10, U303.12 (B4); also elsewhere on the board
/SRAM Banks/B25: J302.8, J304.8, U303.14 (B5); also elsewhere on the board
/SRAM Banks/B26: J302.6, J304.6, U303.16 (B6); also elsewhere on the board
/SRAM Banks/B27: J302.4, J304.4, U303.18 (B7); also elsewhere on the board
/SRAM Banks/D0: J303.18, R308.2, R316.1; also elsewhere on the board
/SRAM Banks/D1: J303.16, R307.2, R315.1; also elsewhere on the board
/SRAM Banks/D2: J303.14, R306.2, R314.1; also elsewhere on the board
/SRAM Banks/D3: J303.12, R305.2, R313.1; also elsewhere on the board
/SRAM Banks/D4: J303.10, R304.2, R312.1; also elsewhere on the board
/SRAM Banks/D5: J303.8, R303.2, R311.1; also elsewhere on the board
/SRAM Banks/D6: J303.6, R302.2, R310.1; also elsewhere on the board
/SRAM Banks/D7: J303.4, R301.2, R309.1; also elsewhere on the board
/SRAM Banks/LD0: D306.5 (A12), R318.2, U302.7 (IO0), U302.29 (IO8), U306.7 (IO0), U306.29 (IO8), U308.7 (IO0), U308.29 (IO8), U310.7 (IO0), U310.29 (IO8)
/SRAM Banks/LD1: D307.5 (A12), R319.2, U302.8 (IO1), U302.30 (IO9), U306.8 (IO1), U306.30 (IO9), U308.8 (IO1), U308.30 (IO9), U310.8 (IO1), U310.30 (IO9)
/SRAM Banks/LD2: D306.4 (A02), R320.2, U302.9 (IO2), U302.31 (IO10), U306.9 (IO2), U306.31 (IO10), U308.9 (IO2), U308.31 (IO10), U310.9 (IO2), U310.31 (IO10)
/SRAM Banks/LD3: D307.4 (A02), R321.2, U302.10 (IO3), U302.32 (IO11), U306.10 (IO3), U306.32 (IO11), U308.10 (IO3), U308.32 (IO11), U310.10 (IO3), U310.32 (IO11)
/SRAM Banks/LD4: D307.1 (A01), R322.2, U302.13 (IO4), U302.35 (IO12), U306.13 (IO4), U306.35 (IO12), U308.13 (IO4), U308.35 (IO12), U310.13 (IO4), U310.35 (IO12)
/SRAM Banks/LD5: D306.1 (A01), R323.2, U302.14 (IO5), U302.36 (IO13), U306.14 (IO5), U306.36 (IO13), U308.14 (IO5), U308.36 (IO13), U310.14 (IO5), U310.36 (IO13)
/SRAM Banks/LD6: D307.2 (A02), R324.2, U302.15 (IO6), U302.37 (IO14), U306.15 (IO6), U306.37 (IO14), U308.15 (IO6), U308.37 (IO14), U310.15 (IO6), U310.37 (IO14)
/SRAM Banks/LD7: D306.2 (A02), R325.2, U302.16 (IO7), U302.38 (IO15), U306.16 (IO7), U306.38 (IO15), U308.16 (IO7), U308.38 (IO15), U310.16 (IO7), U310.38 (IO15)
/SRAM Banks/PA14: J301.25, J303.25, U311.4 (1A1); also elsewhere on the board
/SRAM Banks/PA15: J301.23, J303.23, U311.2 (1A0); also elsewhere on the board
/SRAM Banks/PA16: J301.21, J303.21, U307.11 (2A3); also elsewhere on the board
/SRAM Banks/PA17: J301.19, J303.19, U307.13 (2A2); also elsewhere on the board
/SRAM Banks/PA18: J301.17, J303.17, U307.15 (2A1); also elsewhere on the board
/SRAM Banks/PA19: J301.15, J303.15, U307.17 (2A0); also elsewhere on the board
/SRAM Banks/PA20: J301.13, J303.13, U307.8 (1A3); also elsewhere on the board
/SRAM Banks/PA21: J301.11, J303.11; also elsewhere on the board
/SRAM Banks/PHI2_5: J304.28, U307.6 (1A2)
/SRAM Banks/RW_3: D304.5 (A12), R335.2, U309.14 (A0)
/SRAM Banks/~A0: U302.40 (~BHE), U304.12 (O0), U306.40 (~BHE), U308.40 (~BHE), U310.40 (~BHE)
/SRAM Banks/~OE0: U302.41 (~OE), U309.4 (O0)
/SRAM Banks/~OE1: U306.41 (~OE), U309.5 (O1)
/SRAM Banks/~OE2: U308.41 (~OE), U309.6 (O2)
/SRAM Banks/~OE3: U309.7 (O3), U310.41 (~OE)
/SRAM Banks/~OE: U309.1 (E), U309.12 (O0)
/SRAM Banks/~RAMEN_3: JP301.2 (B), R336.2, U304.1 (E), U309.15 (E)
/SRAM Banks/~RAMEN_5: U303.19 (~A=B), U307.4 (1A1)
/SRAM Banks/~WE: U302.17 (~WE), U306.17 (~WE), U308.17 (~WE), U309.11 (O1), U310.17 (~WE)
/SYNC: J302.22; also elsewhere on the board
/~ML: J301.26; also elsewhere on the board
/~NMI: J302.24; also elsewhere on the board
/~VPB: J301.24; also elsewhere on the board
GND: C301.2, C302.2, C303.2, C304.2, C305.2, C306.2, C307.2, C308.2, C309.2, C310.2, C311.2, C312.2, C313.2, C314.2, C315.2, C316.2, C317.2, C318.2, C319.2, C320.2, C321.2, C322.2, C323.2, C324.2, C325.2, C326.2, C327.2, C328.2, C329.2, D301.1 (K), D305.1 (K), J301.2, J301.9, J301.20, J301.27, J301.31, J301.32, J302.1, J302.2, J302.15, J302.20, J302.26, J302.30, J302.32, J303.2, J303.9, J303.20, J303.27, J303.31, J303.32, J304.1, J304.2, J304.15, J304.20, J304.26, J304.30, J304.32, J305.1, J305.2, J305.3, J305.4, J305.5, J305.6, J305.7, J305.8, R326.1, U301.11 (GND), U302.12 (GND), U302.34 (GND), U303.1 (~EN), U303.10 (GND), U304.8 (GND), U304.13 (A1), U304.15 (E), U305.1 (1~OE), U305.10 (GND), U305.19 (2~OE), U306.12 (GND), U306.34 (GND), U307.1 (1~OE), U307.10 (GND), U307.19 (2~OE), U308.12 (GND), U308.34 (GND), U309.8 (GND), U310.12 (GND), U310.34 (GND), U311.1 (1~OE), U311.10 (GND), U311.19 (2~OE); also elsewhere on the board
unnamed: D301.2 (A), R317.2
unnamed: D305.2 (A), R343.2
unnamed: J301.4, R301.1
unnamed: J301.6, R302.1
unnamed: J301.8, R303.1
unnamed: J301.10, R304.1
unnamed: J301.12, R305.1
unnamed: J301.14, R306.1
unnamed: J301.16, R307.1
unnamed: J301.18, R308.1
unnamed: J305.9, R359.2, U303.17 (A7)
unnamed: J305.10, R358.2, U303.15 (A6)
unnamed: J305.11, R357.2, U303.13 (A5)
unnamed: J305.12, R356.2, U303.11 (A4)
unnamed: J305.13, R355.2, U303.8 (A3)
unnamed: J305.14, R354.2, U303.6 (A2)
unnamed: J305.15, R353.2, U303.4 (A1)
unnamed: J305.16, R352.2, U303.2 (A0)
unnamed: JP301.1 (A), R326.2, U301.10 (OE)
unnamed: R318.1, U301.1 (A1)
unnamed: R319.1, U301.3 (A2)
unnamed: R320.1, U301.4 (A3)
unnamed: R321.1, U301.5 (A4)
unnamed: R322.1, U301.6 (A5)
unnamed: R323.1, U301.7 (A6)
unnamed: R324.1, U301.8 (A7)
unnamed: R325.1, U301.9 (A8)
unnamed: R309.2, U301.20 (B1)
unnamed: R310.2, U301.18 (B2)
unnamed: R311.2, U301.17 (B3)
unnamed: R312.2, U301.16 (B4)
unnamed: R313.2, U301.15 (B5)
unnamed: R314.2, U301.14 (B6)
unnamed: R315.2, U301.13 (B7)
unnamed: R316.2, U301.12 (B8)
unnamed: U302.6 (~CE), U304.4 (O0)
unnamed: U304.5 (O1), U306.6 (~CE)
unnamed: U304.6 (O2), U308.6 (~CE)
unnamed: U304.7 (O3), U310.6 (~CE)
unnamed: R330.1, U305.18 (1Y0)
unnamed: R329.1, U305.16 (1Y1)
unnamed: R328.1, U305.14 (1Y2)
unnamed: R327.1, U305.12 (1Y3)
unnamed: R334.1, U305.3 (2Y0)
unnamed: R333.1, U305.5 (2Y1)
unnamed: R332.1, U305.7 (2Y2)
unnamed: R331.1, U305.9 (2Y3)
unnamed: R338.1, U307.18 (1Y0)
unnamed: R337.1, U307.16 (1Y1)
unnamed: R336.1, U307.14 (1Y2)
unnamed: R335.1, U307.12 (1Y3)
unnamed: R342.1, U307.3 (2Y0)
unnamed: R341.1, U307.5 (2Y1)
unnamed: R340.1, U307.7 (2Y2)
unnamed: R339.1, U307.9 (2Y3)
unnamed: R347.1, U311.18 (1Y0)
unnamed: R346.1, U311.16 (1Y1)
unnamed: R345.1, U311.14 (1Y2)
unnamed: R344.1, U311.12 (1Y3)
unnamed: R351.1, U311.3 (2Y0)
unnamed: R350.1, U311.5 (2Y1)
unnamed: R349.1, U311.7 (2Y2)
unnamed: R348.1, U311.9 (2Y3)
RESB: J301.22; also elsewhere on the board

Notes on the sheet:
VAddr LSB
CY7C1041DV33
Bidirectional Data
Vadr MSb's
SRAM Data Overvolt Protection
Superbank Select
Extra outputs
To ensure mutual exclusion between BLE and BHE
SRAM Data Overvolt Protection Supply ON
BankSel

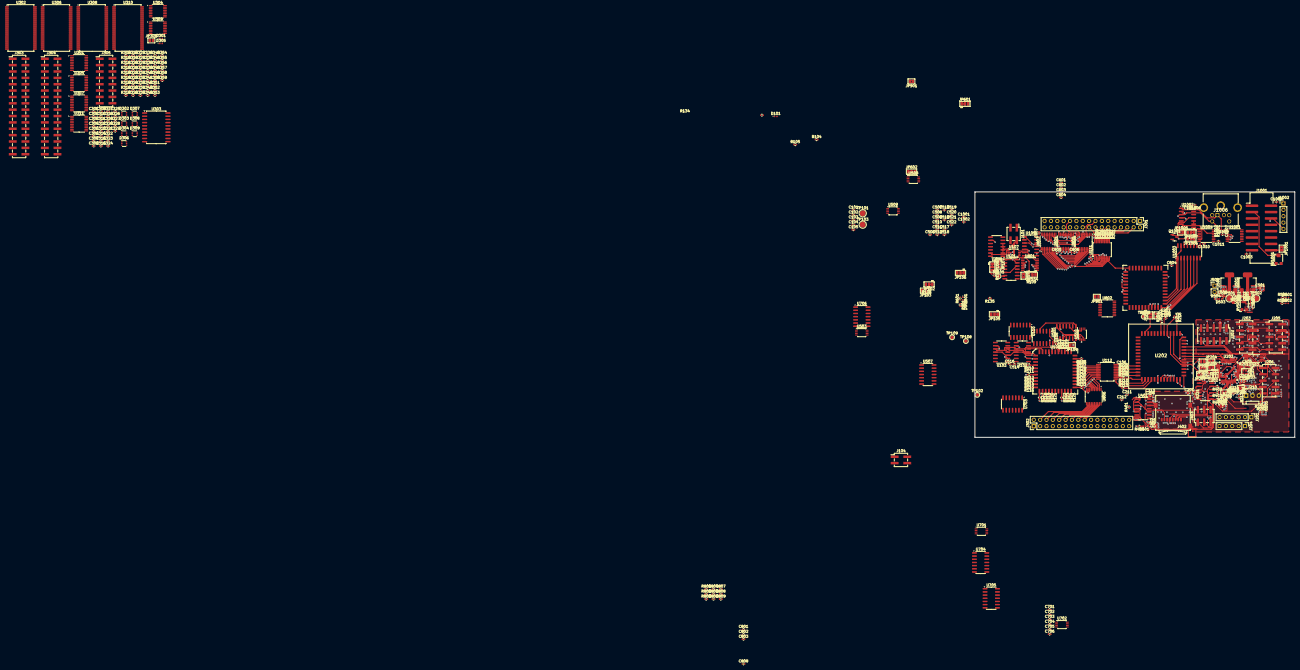
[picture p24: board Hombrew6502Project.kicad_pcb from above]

Board: 4 copper layers, 127.6 x 98.0 mm, 378 parts (0 on the bottom side), 408 nets.

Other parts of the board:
TP103: TestPoint; TestPoint_Pad_D2.5mm

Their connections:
unnamed 287: TP103.1; also elsewhere on the board

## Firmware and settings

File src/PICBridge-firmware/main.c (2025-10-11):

/*  main.c
 * 
 *  This is a simple shell, with one-character commands (executing on \n). It is not meant for humans, but rather for my
 * programmer python script. But also, since I want to be able to debug stuff manually, here's the rundown:
 * 
 * Ex Cmd         Function & use
 * =======      ===================
 * !            Panic: throws the 6502 into reset, disables everything
 * Wdeadabcdef1 Writes 0xabcdef1 to location 0xdead in EEPROM (hex string may be as long as intended, so long as it is a multiple of two chars for 8 bits)
 * Rdead0006    Reads 0x6 bytes starting at 0xDEAD in EEPROM (reads out hex values)
 * w0abdeadbeef Writes 0xDEADBEEF into addr 0x0ab in SRAM
 * r0ab004      Reads 0x004 bytes from SRAM starting at 0x0ab
 * O            Un-resets the 6502
 * -            Resets the 6502
 */

#define COMM_VERSION "0.0"

#define assert(val, message) if(!val) {uart_puts(message); while(1);}

#include "mcc_generated_files/system/system.h"
#include "hardware.h"
#include <string.h>
#include "m95_eeprom.h"
#include "conio.h"

volatile char rx_buffer[70];
volatile char cmd_buffer[70];
char eeprom_sram_io_buffer[64];
volatile uint8_t rx_index = 0;
volatile bool message_ready = false;

// Convert a single hex character to its value (0-15), or -1 if invalid
static int hex2val(char c) {
    if (c >= '0' && c <= '9') return c - '0';
    if (c >= 'A' && c <= 'F') return c - 'A' + 10;
    if (c >= 'a' && c <= 'f') return c - 'a' + 10;
    return -1;
}

// Convert a hex string to a byte array
static int hexstr_to_bytes(const char* str, int len, uint8_t* out, int maxout) {
    int bytes = 0;
    for(int i=0; i<len && bytes<maxout; i+=2) {
        int hi = hex2val(str[i]);
        int lo = (i+1 < len) ? hex2val(str[i+1]) : -1;
        if(hi<0 || lo<0) break;
        out[bytes++] = (hi<<4) | lo;
    }
    return bytes;
}

// Convert a hex string to an integer (up to 4 digits)
static unsigned int hexstr_to_uint(const char* str, int digits) {
    unsigned int val = 0;
    for(int i=0; i<digits; i++) {
        int v = hex2val(str[i]);
        if(v<0) break;
        val = (val<<4) | v;
    }
    return val;
}

// UART Interrupt Routine - keep it simple and fast!
void onUartInput(void) {
    if(EUSART2_IsRxReady()) {
        char received = EUSART2_Read();
        
        // Store character in buffer (leave room for null terminator)
        if(rx_index < 69) {
            rx_buffer[rx_index++] = received;
            
            // Check for end of message
            if(received == '\n' || received == '\r') {
                rx_buffer[rx_index] = '\0';  // Null terminate
                message_ready = true;
                rx_index = 0;  // Reset for next message
            }
        } else {
            // Buffer overflow - reset
            rx_index = 0;
        }
    }
}

/*
    Main application
*/
int main(void)
{
    //LATAbits.LATA4 = 1;    // Start with CS high for my scope trigger to do what I want...

    SYSTEM_Initialize();
    SRAM_init();
    INTERRUPT_GlobalInterruptEnable(); 
    INTERRUPT_PeripheralInterruptEnable(); 
    cpu6502_reset();
    cpu6502_uninterrupt();

    EUSART2_RxCompleteCallbackRegister(onUartInput);
    EUSART2_ReceiveInterruptEnable();

    uart_puts("\n\r\n\r\n\r=================================================\n\rBasic i/o INITIALIZED\n\r");

    // Configure RA3 as output
    TRISAbits.TRISA3 = 0;  // Set RA3 as output
    LATAbits.LATA3 = 1;    // Initialize RA3 high

    char status = M95_init();
    if(status < 0) {
        uart_puts("Err initializing EEPROM... :(\n\r");
        while(1);  // Stall forevermore
    }
    uint8_t sram_buf[16];
    SRAM_write(0x000, 0x00);
    assert(SRAM_read(0) == 0x00, "Error writing to 0x000 of SRAM")
    SRAM_write(0x000, 0xDD);
    assert(SRAM_read(0) == 0xDD, "Error writing to 0x000 of SRAM")
    SRAM_write(0xF00, 0x00);
    assert(SRAM_read(0xF00) == 0x00, "Error writing to 0xF00 of SRAM")
    SRAM_write(0xF00, 0xAF);
    assert(SRAM_read(0xF00) == 0xAF, "Error writing to 0xF00 of SRAM")
    

    uart_puts("Init success. :)\n\rUSEFUL 6502 COPROCESSOR CONTROL SHELL by JOSEPH R FREESTON");
    uart_puts("\n\rVersion: ");
    uart_puts(COMM_VERSION);
    uart_puts("\n\rREADY\n\r");

    while (1) {
        // Check for received UART messages
        if(message_ready) {
            strcpy(cmd_buffer, rx_buffer);
            message_ready = false;  // Clear the flag

            int len = strlen(cmd_buffer);
            if(len == 0) continue;

            // EEPROM write: Wdeadabcdef1
            if(cmd_buffer[0] == 'W') {
                if(len < 5) { uart_puts("ERR:BAD_CMD\n\r"); continue; }
                unsigned int addr = hexstr_to_uint(cmd_buffer+1, 4);
                int datalen = len - 5;
                if(datalen <= 0) { uart_puts("ERR:NO_DATA\n\r"); continue; }
                int bytes = hexstr_to_bytes(cmd_buffer+5, datalen, eeprom_sram_io_buffer, sizeof(eeprom_sram_io_buffer));
                char retval = M95_write_bytes(addr, bytes, eeprom_sram_io_buffer);
                if(retval < 0 && retval != 0xFF) {
                    uart_puts("ERR:EEPROM_WRITE:");
                    putch_hex(retval);
                    uart_puts("\n\r");
                } else {
                    uart_puts("OK:EEPROM_WRITE:");
                    putch_hex(retval);
                    uart_puts("\n\r");
                }
            }
            // EEPROM read: Rdead0006
            else if(cmd_buffer[0] == 'R') {
                if(len < 9) { uart_puts("ERR:BAD_CMD\n\r"); continue; }
                unsigned int addr = hexstr_to_uint(cmd_buffer+1, 4);
                unsigned int nbytes = hexstr_to_uint(cmd_buffer+5, 4);
                if(nbytes > sizeof(eeprom_sram_io_buffer)) nbytes = sizeof(eeprom_sram_io_buffer);
                if(M95_read_bytes(addr, nbytes, eeprom_sram_io_buffer) < 0) {
                    uart_puts("ERR:EEPROM_READ\n\r");
                } else {
                    uart_puts("OK:EEPROM_READ:");
                    for(int i = 0; i < nbytes; i++) {
                        putch_hex((unsigned char)eeprom_sram_io_buffer[i]);
                    }
                    uart_puts("\n\r");
                }
            }
            // SRAM write: w0abdeadbeef
            else if(cmd_buffer[0] == 'w') {
                if(len < 5) { uart_puts("ERR:BAD_CMD\n\r"); continue; }
                unsigned int addr = hexstr_to_uint(cmd_buffer+1, 3);
                int datalen = len - 4;
                if(datalen <= 0) { uart_puts("ERR:NO_DATA\n\r"); continue; }
                if(datalen > 128) { uart_puts("ERR:TOO_LONG\n\r"); continue; } // Prevent buffer overrun
                if(datalen % 2 != 1) { uart_puts("ERR:ODD_HEX\n\r"); continue; } // Prevent odd hex string
                // if(datalen % 2 != 0) { uart_puts("ERR:ODD_HEX\n\r"); continue; } // Prevent odd hex string
                int bytes = hexstr_to_bytes(cmd_buffer+4, datalen, eeprom_sram_io_buffer, sizeof(eeprom_sram_io_buffer));
                int retval = SRAM_write_bytes(addr, bytes, eeprom_sram_io_buffer);
                if(retval < 0) {
                    uart_puts("ERR:SRAM_WRITE\n\r");
                } else {
                    uart_puts("OK:SRAM_WRITE:");
                    putch_hex(retval);
                    uart_puts("\n\r");
                }
            }
            // SRAM read: r0ab004
            else if(cmd_buffer[0] == 'r') {
                if(len < 7) { uart_puts("ERR:BAD_CMD\n\r"); continue; }
                unsigned int addr = hexstr_to_uint(cmd_buffer+1, 3);
                unsigned int nbytes = hexstr_to_uint(cmd_buffer+4, 3);
                if(nbytes > sizeof(eeprom_sram_io_buffer)) nbytes = sizeof(eeprom_sram_io_buffer);
                if(SRAM_read_bytes(addr, nbytes, eeprom_sram_io_buffer) < 0) {
                    uart_puts("ERR:SRAM_READ\n\r");
                } else {
                    uart_puts("OK:SRAM_READ:");
                    for(int i = 0; i < nbytes; i++) {
                        putch_hex(eeprom_sram_io_buffer[i]);
                    }
                    uart_puts("\n\r");
                }
            }
            // 6502 un-reset: O
            else if(cmd_buffer[0] == 'O') {
                cpu6502_unreset();
                uart_puts("OK:CPU_UNRESET\n\r");
            }
            // 6502 reset: -
            else if(cmd_buffer[0] == '-') {
                cpu6502_reset();
                uart_puts("OK:CPU_RESET\n\r");
            }
            // 6502 interrupt
            else if(cmd_buffer[0] == 'I') {
                cpu6502_interrupt();
                uart_puts("OK:CPU_IRQ\n\r");
            }
            // 6502 un-interrupt
            else if(cmd_buffer[0] == 'i') {
                cpu6502_uninterrupt();
                uart_puts("OK:CPU_IRQ_CLEAR\n\r");
            }
            // Version/status query: ?
            else if(cmd_buffer[0] == '?') {
                uart_puts("OK:VERSION:");
                uart_puts(COMM_VERSION);
                uart_puts("\n\r");
            }
            // Unknown command
            else {
                uart_puts("ERR:UNKNOWN_CMD\n\r");
            }
        }
    }
}

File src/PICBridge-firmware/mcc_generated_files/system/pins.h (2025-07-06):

/**
 * Generated Pins header File
 * 
 * @file pins.h
 * 
 * @defgroup  pinsdriver Pins Driver
 * 
 * @brief This is generated driver header for pins. 
 *        This header file provides APIs for all pins selected in the GUI.
 *
 * @version Driver Version  3.0.0
*/

/*
© [2025] Microchip Technology Inc. and its subsidiaries.

    Subject to your compliance with these terms, you may use Microchip 
    software and any derivatives exclusively with Microchip products. 
    You are responsible for complying with 3rd party license terms  
    applicable to your use of 3rd party software (including open source  
    software) that may accompany Microchip software. SOFTWARE IS ?AS IS.? 
    NO WARRANTIES, WHETHER EXPRESS, IMPLIED OR STATUTORY, APPLY TO THIS 
    SOFTWARE, INCLUDING ANY IMPLIED WARRANTIES OF NON-INFRINGEMENT,  
    MERCHANTABILITY, OR FITNESS FOR A PARTICULAR PURPOSE. IN NO EVENT 
    WILL MICROCHIP BE LIABLE FOR ANY INDIRECT, SPECIAL, PUNITIVE, 
    INCIDENTAL OR CONSEQUENTIAL LOSS, DAMAGE, COST OR EXPENSE OF ANY 
    KIND WHATSOEVER RELATED TO THE SOFTWARE, HOWEVER CAUSED, EVEN IF 
    MICROCHIP HAS BEEN ADVISED OF THE POSSIBILITY OR THE DAMAGES ARE 
    FORESEEABLE. TO THE FULLEST EXTENT ALLOWED BY LAW, MICROCHIP?S 
    TOTAL LIABILITY ON ALL CLAIMS RELATED TO THE SOFTWARE WILL NOT 
    EXCEED AMOUNT OF FEES, IF ANY, YOU PAID DIRECTLY TO MICROCHIP FOR 
    THIS SOFTWARE.
*/

#ifndef PINS_H
#define PINS_H

#include <xc.h>

#define INPUT   1
#define OUTPUT  0

#define HIGH    1
#define LOW     0

#define ANALOG      1
#define DIGITAL     0

#define PULL_UP_ENABLED      1
#define PULL_UP_DISABLED     0

// get/set IO_RA5 aliases
#define IO_RA5_TRIS                 TRISAbits.TRISA5
#define IO_RA5_LAT                  LATAbits.LATA5
#define IO_RA5_PORT                 PORTAbits.RA5
#define IO_RA5_WPU                  WPUAbits.WPUA5
#define IO_RA5_OD                   ODCONAbits.ODCA5
#define IO_RA5_ANS                  ANSELAbits.ANSA5
#define IO_RA5_SetHigh()            do { LATAbits.LATA5 = 1; } while(0)
#define IO_RA5_SetLow()             do { LATAbits.LATA5 = 0; } while(0)
#define IO_RA5_Toggle()             do { LATAbits.LATA5 = ~LATAbits.LATA5; } while(0)
#define IO_RA5_GetValue()           PORTAbits.RA5
#define IO_RA5_SetDigitalInput()    do { TRISAbits.TRISA5 = 1; } while(0)
#define IO_RA5_SetDigitalOutput()   do { TRISAbits.TRISA5 = 0; } while(0)
#define IO_RA5_SetPullup()          do { WPUAbits.WPUA5 = 1; } while(0)
#define IO_RA5_ResetPullup()        do { WPUAbits.WPUA5 = 0; } while(0)
#define IO_RA5_SetPushPull()        do { ODCONAbits.ODCA5 = 0; } while(0)
#define IO_RA5_SetOpenDrain()       do { ODCONAbits.ODCA5 = 1; } while(0)
#define IO_RA5_SetAnalogMode()      do { ANSELAbits.ANSA5 = 1; } while(0)
#define IO_RA5_SetDigitalMode()     do { ANSELAbits.ANSA5 = 0; } while(0)
#define RA5_SetInterruptHandler  IO_RA5_SetInterruptHandler
// get/set IO_RB0 aliases
#define IO_RB0_TRIS                 TRISBbits.TRISB0
#define IO_RB0_LAT                  LATBbits.LATB0
#define IO_RB0_PORT                 PORTBbits.RB0
#define IO_RB0_WPU                  WPUBbits.WPUB0
#define IO_RB0_OD                   ODCONBbits.ODCB0
#define IO_RB0_ANS                  ANSELBbits.ANSB0
#define IO_RB0_SetHigh()            do { LATBbits.LATB0 = 1; } while(0)
#define IO_RB0_SetLow()             do { LATBbits.LATB0 = 0; } while(0)
#define IO_RB0_Toggle()             do { LATBbits.LATB0 = ~LATBbits.LATB0; } while(0)
#define IO_RB0_GetValue()           PORTBbits.RB0
#define IO_RB0_SetDigitalInput()    do { TRISBbits.TRISB0 = 1; } while(0)
#define IO_RB0_SetDigitalOutput()   do { TRISBbits.TRISB0 = 0; } while(0)
#define IO_RB0_SetPullup()          do { WPUBbits.WPUB0 = 1; } while(0)
#define IO_RB0_ResetPullup()        do { WPUBbits.WPUB0 = 0; } while(0)
#define IO_RB0_SetPushPull()        do { ODCONBbits.ODCB0 = 0; } while(0)
#define IO_RB0_SetOpenDrain()       do { ODCONBbits.ODCB0 = 1; } while(0)
#define IO_RB0_SetAnalogMode()      do { ANSELBbits.ANSB0 = 1; } while(0)
#define IO_RB0_SetDigitalMode()     do { ANSELBbits.ANSB0 = 0; } while(0)
// get/set IO_RB1 aliases
#define IO_RB1_TRIS                 TRISBbits.TRISB1
#define IO_RB1_LAT                  LATBbits.LATB1
#define IO_RB1_PORT                 PORTBbits.RB1
#define IO_RB1_WPU                  WPUBbits.WPUB1
#define IO_RB1_OD                   ODCONBbits.ODCB1
#define IO_RB1_ANS                  ANSELBbits.ANSB1
#define IO_RB1_SetHigh()            do { LATBbits.LATB1 = 1; } while(0)
#define IO_RB1_SetLow()             do { LATBbits.LATB1 = 0; } while(0)
#define IO_RB1_Toggle()             do { LATBbits.LATB1 = ~LATBbits.LATB1; } while(0)
#define IO_RB1_GetValue()           PORTBbits.RB1
#define IO_RB1_SetDigitalInput()    do { TRISBbits.TRISB1 = 1; } while(0)
#define IO_RB1_SetDigitalOutput()   do { TRISBbits.TRISB1 = 0; } while(0)
#define IO_RB1_SetPullup()          do { WPUBbits.WPUB1 = 1; } while(0)
#define IO_RB1_ResetPullup()        do { WPUBbits.WPUB1 = 0; } while(0)
#define IO_RB1_SetPushPull()        do { ODCONBbits.ODCB1 = 0; } while(0)
#define IO_RB1_SetOpenDrain()       do { ODCONBbits.ODCB1 = 1; } while(0)
#define IO_RB1_SetAnalogMode()      do { ANSELBbits.ANSB1 = 1; } while(0)
#define IO_RB1_SetDigitalMode()     do { ANSELBbits.ANSB1 = 0; } while(0)
// get/set IO_RB2 aliases
#define IO_RB2_TRIS                 TRISBbits.TRISB2
#define IO_RB2_LAT                  LATBbits.LATB2
#define IO_RB2_PORT                 PORTBbits.RB2
#define IO_RB2_WPU                  WPUBbits.WPUB2
#define IO_RB2_OD                   ODCONBbits.ODCB2
#define IO_RB2_ANS                  ANSELBbits.ANSB2
#define IO_RB2_SetHigh()            do { LATBbits.LATB2 = 1; } while(0)
#define IO_RB2_SetLow()             do { LATBbits.LATB2 = 0; } while(0)
#define IO_RB2_Toggle()             do { LATBbits.LATB2 = ~LATBbits.LATB2; } while(0)
#define IO_RB2_GetValue()           PORTBbits.RB2
#define IO_RB2_SetDigitalInput()    do { TRISBbits.TRISB2 = 1; } while(0)
#define IO_RB2_SetDigitalOutput()   do { TRISBbits.TRISB2 = 0; } while(0)
#define IO_RB2_SetPullup()          do { WPUBbits.WPUB2 = 1; } while(0)
#define IO_RB2_ResetPullup()        do { WPUBbits.WPUB2 = 0; } while(0)
#define IO_RB2_SetPushPull()        do { ODCONBbits.ODCB2 = 0; } while(0)
#define IO_RB2_SetOpenDrain()       do { ODCONBbits.ODCB2 = 1; } while(0)
#define IO_RB2_SetAnalogMode()      do { ANSELBbits.ANSB2 = 1; } while(0)
#define IO_RB2_SetDigitalMode()     do { ANSELBbits.ANSB2 = 0; } while(0)
// get/set IO_RB3 aliases
#define IO_RB3_TRIS                 TRISBbits.TRISB3
#define IO_RB3_LAT                  LATBbits.LATB3
#define IO_RB3_PORT                 PORTBbits.RB3
#define IO_RB3_WPU                  WPUBbits.WPUB3
#define IO_RB3_OD                   ODCONBbits.ODCB3
#define IO_RB3_ANS                  ANSELBbits.ANSB3
#define IO_RB3_SetHigh()            do { LATBbits.LATB3 = 1; } while(0)
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

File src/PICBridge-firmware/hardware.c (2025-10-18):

#include "hardware.h"
#include "mcc_generated_files/system/system.h"

/****************
 *   SRAM I/O   *
 ****************/

/**
 * Initialize SRAM interface
 * Sets control pins to safe states and data bus to high-Z
 */
void SRAM_init(void) {
    // Set data bus (PORTF) to high-Z (inputs)
    TRISF = 0xFF;
    // Set data bus pins as digital
    ANSELF = 0x00;
    // Set control pins to safe states
    LATDbits.LATD7 = 1;  // ~OE high (disabled)
    LATDbits.LATD6 = 1;  // R/~W high (read mode)
    LATDbits.LATD5 = 1;  // ~CE high (deselected)
    LATDbits.LATD4 = 1;  // BUSY high (not busy - slave device input)
    
    // Clear address bus
    LATC = 0x00;       // A0-A7
    LATE &= 0xF8;      // Clear RE0, RE1, RE2 (A10, A9, A8)
    NOP();
    NOP();  // Small delay for latch to settle

    // Set address bus pins as outputs
    TRISC = 0x00;       // A0-A7
    TRISE &= 0xF8;      // RE0, RE1, RE2 as outputs (A10, A9, A8)

    // Set control pins as outputs
    TRISDbits.TRISD7 = 0; // ~OE
    TRISDbits.TRISD6 = 0; // R/~W
    TRISDbits.TRISD5 = 0; // ~CE
    TRISDbits.TRISD4 = 0; // BUSY (output from PIC, input to SRAM slave)
    
    // Initialize CPU control pins
    // Ensure digital mode (clear ANSELA bits 0 and 1)
    ANSELA &= 0xFC;        // Clear ANSA0 and ANSA1 (bits 0 and 1)
    
    // Set outputs before configuring as outputs
    LATAbits.LATA0 = 1;    // IRQ high (not asserted)
    LATAbits.LATA1 = 0;    // RESB low (in reset)
    TRISAbits.TRISA0 = 0;  // IRQ as output
    TRISAbits.TRISA1 = 0;  // RESB as output
}

/**
 * Set SRAM address on address bus
 * @param addr 11-bit address (0-2047)
 */
static void SRAM_set_address(unsigned int addr) {
    // Mask to 11 bits for 2kiB addressing
    addr &= 0x07FF;
    
    // Set A0-A7 on PORTC
    LATC = addr & 0xFF;
    
    // Set A8-A10 on PORTE (bits 0, 1, 2)
    LATE = (LATE & 0xF8) | ((addr >> 8) & 0x07);
    NOP();  // Small delay for address setup
}

/**
 * Read a byte from SRAM
 * @param addr Address to read from (0-2047)
 * @return Data byte read
 */
unsigned char SRAM_read(unsigned int addr) {
    unsigned char data;
    
    // Set read mode (should already be set)
    LATDbits.LATD6 = 1;  // R/~W high
    LATDbits.LATD7 = 1;  // ~OE high
    LATDbits.LATD5 = 1;  // ~CE high

    // Ensure data bus is TRULY high-Z (input)
    ANSELF = 0x00;  // Ensure digital mode
    LATF = 0x00;    // Clear output latch
    TRISF = 0xFF;   // Set as input
    NOP();          // Give time for bus to float

    // Set address
    SRAM_set_address(addr);
    
    // Select chip
    LATDbits.LATD5 = 0;  // ~CE low
    NOP();
    NOP();  // CE to output delay (~60ns)

    // Enable output
    LATDbits.LATD7 = 0;  // ~OE low
    
    // Wait for SRAM to drive bus
    NOP();
    NOP();  // Output enable delay (~60ns)
    
    // Read data
    data = PORTF;
    
    // Disable output
    LATDbits.LATD7 = 1;  // ~OE high
    NOP();
    
    // Park just below interrupt vectors
    SRAM_set_address(0xFFF3);

    SRAM_deselect();
    return data;
}

/**
 * Write a byte to SRAM
 * @param addr Address to write to (0-2047)
 * @param data Data byte to write
 */
void SRAM_write(unsigned int addr, unsigned char data) {
    // Ensure ~OE is high before changing data direction
    LATDbits.LATD7 = 1;  // ~OE high
    LATDbits.LATD6 = 1;  // R/~W high initially
    
    // Set address
    SRAM_set_address(addr);
    NOP();  // Address setup time
    
    // Select chip (keep low for entire write cycle)
    LATDbits.LATD5 = 0;  // ~CE low
    NOP();  // CE setup time
    
    // Set data bus to output
    TRISF = 0x00;
    
    // Put data on bus
    LATF = data;
    NOP();  // Data setup time before write pulse
    
    // Write pulse: R/~W low then high
    LATDbits.LATD6 = 0;  // R/~W low (start write)
    NOP();
    NOP();  // Write pulse width (~60ns)
    LATDbits.LATD6 = 1;  // R/~W high (end write)
    
    NOP();  // Data hold time
    
    // Deselect chip
    LATDbits.LATD5 = 1;  // ~CE high
    
    // Set data bus back to high-Z
    TRISF = 0xFF;
    
    // Park just below interrupt vectors
    SRAM_set_address(0xFFF3);

    SRAM_deselect();
}

// Write 'len' bytes from 'data' to SRAM starting at 'addr'
int SRAM_write_bytes(uint32_t addr, int len, const uint8_t* data) {
    // Ensure ~OE is high before changing data direction
    LATDbits.LATD7 = 1;  // ~OE high
    LATDbits.LATD6 = 1;  // R/~W high initially
    
    // Set data bus to output
    TRISF = 0x00;

    int stop = addr+len;
    for(int addri = addr; addri < stop; addri++) {
        // Set address
        SRAM_set_address(addri);
        NOP();  // Address setup time
        
        // Select chip
        LATDbits.LATD5 = 0;  // ~CE low
        NOP();  // CE setup time
        
        // Put data on bus
        LATF = *data;
        NOP();  // Data setup time before write pulse
        
        // Write pulse: R/~W low then high
        LATDbits.LATD6 = 0;  // R/~W low (start write)
        NOP();
        NOP();  // Write pulse width (~60ns)
        LATDbits.LATD6 = 1;  // R/~W high (end write)
        
        NOP();  // Data hold time
        
        // Deselect chip
        LATDbits.LATD5 = 1;  // ~CE high
        
        data++;  // Go to the next loc in memory next round
        NOP();
        NOP();  // Inter-write delay (~60ns)
    }    
    // Set data bus back to high-Z
    TRISF = 0xFF;
    
    // Park just below interrupt vectors
    SRAM_set_address(0xFFF3);
    
    SRAM_deselect();
    return len;
}

// Read 'len' bytes from SRAM starting at 'addr' into 'data'
int SRAM_read_bytes(uint32_t addr, int len, uint8_t* data) {
    // Set read mode (should already be set)
    LATDbits.LATD6 = 1;  // R/~W high
    LATDbits.LATD7 = 1;  // ~OE high
    LATDbits.LATD5 = 1;  // ~CE high

    // Ensure data bus is TRULY high-Z (input)
    ANSELF = 0x00;  // Ensure digital mode
    LATF = 0x00;    // Clear output latch
    TRISF = 0xFF;   // Set as input
    NOP();          // Give time for bus to float

    // Select chip
    LATDbits.LATD5 = 0;  // ~CE low
    NOP();
    NOP();  // CE to output delay (~60ns)

    // Enable output
    LATDbits.LATD7 = 0;  // ~OE low
    
    int stop = addr+len;
    for(int addri = addr; addri < stop; addri++) {
        // Set address
        SRAM_set_address(addri);
        NOP();
        NOP();  // Wait for SRAM to drive bus (~60ns)
        
        // Read data
        *data = PORTF;
        data++;  // Go to the next loc in memory next round
    }

    // Disable output
    LATDbits.LATD7 = 1;  // ~OE high
    NOP();
    
    // Park just below interrupt vectors
    SRAM_set_address(0xFFF3);

    SRAM_deselect();
    return len;
}
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

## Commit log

2025-02-22 Init software boilerplate and Makefile
    [kernel_target.cfg]
2025-02-22 Working vm and cc65 config
    [kernel_target.cfg]
2025-03-01 Created KiCad project
    [6502sbc.kicad_pcb, 6502sbc.kicad_sch]
2025-03-01 Remove KiCad lock file; do not track
2025-06-08 KiCAD schematic is mostly complete
    [6502sbc.kicad_pcb, 6502sbc.kicad_sch, DMA_cpu_board_interface.kicad_sch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]
2025-06-08 Preliminary schematic
    [6502sbc.kicad_sch, DMA_cpu_board_interface.kicad_sch, addr_decode.kicad_sch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]
2025-06-15 Schematic is nearly done
    [6502sbc.kicad_sch, DMA_cpu_board_interface.kicad_sch, addr_decode.kicad_sch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]
2025-06-15 Most footprints assigned
    [6502sbc.kicad_sch, DMA_cpu_board_interface.kicad_sch, addr_decode.kicad_sch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]
2025-06-16 Ready to begin pcb layout
    [6502sbc.kicad_pcb, 6502sbc.kicad_sch, char_io.kicad_sch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]
2025-06-17 Overhaul of structure, etc
    [DMA_cpu_board_interface.kicad_sch, Hombrew6502Project.kicad_pcb, Hombrew6502Project.kicad_sch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]
2025-06-19 Some connector changes
    [DMA_cpu_board_interface.kicad_sch, Hombrew6502Project.kicad_pcb, Hombrew6502Project.kicad_sch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]
2025-06-19 Made DMA peripheral stuff on same board
    [DMA_cpu_board_interface.kicad_sch]
2025-06-19 footprint assignments and separate project for RAM board
    [Hombrew6502Project.kicad_pcb, Hombrew6502Project.kicad_sch, RamBanks.kicad_pcb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]
2025-06-25 Peripheral io layout done; snapshot of current state before redoing much of the rest of the layout.
    [Hombrew6502Project.kicad_pcb, Hombrew6502Project.kicad_sch, char_io.kicad_sch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]
2025-06-29 Layout mostly finished
    [DMA_cpu_board_interface.kicad_sch, Hombrew6502Project.kicad_sch, addr_decode.kicad_sch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]
2025-06-29 Fixed typo in KiCAD project name
    [DMA_cpu_board_interface.kicad_sch, Homebrew6502Project.kicad_sch, addr_decode.kicad_sch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]
2025-07-04 Layout of Rev a is finished
    [DMA_cpu_board_interface.kicad_sch, Homebrew6502Project.kicad_sch, RamBanks.kicad_pcb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]
2025-07-04 Generated Gerbers
    [Homebrew6502Project-B_Cu.gbl, Homebrew6502Project-B_Mask.gbs, Homebrew6502Project-B_Paste.gbp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]
2025-07-04 Plotted schematic
2025-07-05 Initial kernel project setup
    [kernel_target.cfg]
2025-07-05 linguist ignore kicad html bom
2025-07-06 Added pcb renders
2025-07-13 Beginnings of the debug bootloading scheme
    [loader6502.cfg]
2025-07-17 basic uart is working
2025-10-11 Commit to save current state. SRAM access not working, figured out some latching issues
    [hardware.c, main.c]
2025-10-18 working blinking on 6502
    [loader6502.cfg]
2025-10-26 Added image of current PCB for README
2025-10-26 Revise PCB status and add images
    Updated the current status of the PCB assembly and functionality.
